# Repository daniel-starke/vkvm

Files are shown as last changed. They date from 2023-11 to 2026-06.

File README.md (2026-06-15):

vkvm
====

**V**irtual **K**eyboard **V**ideo **M**ouse equipment.  
This project consists of a software part which runs on the host (controller) computer and a hardware
unit (periphery). The periphery is connected via HDMI and USB to the USB port at the controller. The
controller uses this connection to control the connected periphery computer. Control works similar to
the control of a system running within a virtual machine.  
The vkvm ensures a non-intrusive connection to the periphery device. Therefore, no special drivers or
software is needed at the periphery. This grants maximum compatibility and high security not found in
VPN or SSH like solutions and works also before OS start-up (e.g. remote BIOS control).

```txt
+------------+       +----------------------+      +---------------+
|            |  <--- | Video Capture Device | <--- |               |
| Controller |       +----------------------+      | Remote Device |
|            |  <--> | VKVM Periphery       | <--> |               |
+------------+       +----------------------+      +---------------+
```

Features
========

- control application support for Windows and Linux
- USB UVC capture device compatible at controller
- USB HID boot keyboard/mouse compatible at periphery
- easy setup and use via plug'n'play
- cheap, small, low latency and portable design
- supports direct video output capture of periphery or web cam based operation
- multiple hardware variants are available to meet different hardware assembly skills and usage requirements
- remote device access before OS startup (e.g. enter BitLocker password or set BIOS settings)

Usage
=====

Use an available display to USB (not the other way around) converter to capture the video output
of a periphery machine at the controller. See chapter example for some possible variants. Connect
the VKVM hardware device to controller and periphery to control the keyboard and mouse of the
periphery via the controller. The vkvm control application enables you to perform the described hardware
connection on software level.  
Here you choose the connected capture source and serial interface which connects the vkvm hardware.
Click into the video frame to start controlling the remote device. Hit the right SHIFT and right CTRL key
to return control. Alternatively, press CTRL-K without a connected capture source for blind control.
This can be useful when controlling the periphery device with a connected physical monitor.  
To improve periphery operation, multiple ways of inputting data from controller (paste text) are provided.
Each type exists due to different compatibilities, either by applications or on OS level.  
Most of the user interface is made up of icons to avoid language barriers.

Status LED of the VKVM periphery:

|LED |State |Meaning
|:---:|---|---
| |always off|No remote device connected.
|LED0|blinking  |Power from remote device but not USB connection.
|LED1|always on |Fully connected to remote device.

Documentation
=============

- [Windows: VKVM Control Driver Installation](doc/win-driver.md)
- [Hardware](doc/hardware.md)
- [Software Architecture](doc/architecture.md)
- [Serial Protocol](doc/protocol.md)

Building
========


    

The following dependencies are given.  
Controller:  
- C99
- C++11
- [FLTK 1.3.4-1](https://github.com/fltk/fltk/tree/release-1.3.4-1)
- [nanosvg](https://github.com/memononen/nanosvg) (modified source included)
- OpenGL
- DirectShow (only on Windows)
- libv4l2 (only on Linux)
- lv4lconvert (only on Linux)

Periphery:  
- C18
- C++14
- [PlatformIO](https://platformio.org/)
- [STM32CubeDuino](https://github.com/daniel-starke/STM32CubeDuino)
- [HidDescCTC](https://github.com/daniel-starke/HidDescCTC)

Choose the appropriate Makefile to match your target system configuration.  
Windows with MinGW and GCC:  
```sh
make -f Makefile.mingw
```

Linux with GCC:
```sh
make -f Makefile.linux
```

This creates two applications:
- `vkvm`  
  The actual VKVM control application.
- `keyTest`  
  Development tool to create the OS key code to USB key code mapping.

To build and upload the firmware (depending on the target hardware):
```sh
pio run -e arduino -t upload
pio run -e vkm-b-controller -t upload
pio run -e vkm-b-periphery -t upload
```

Note that `VKVM_LED_PWM` for `vkm-b-periphery` can be changed in `platformio.ini` to any value
between 0 and 65535 to adjust the brightness of the status LED.

Also note that it is possible to set `upload_protocol = dfu` for `STM32CubeDuino` in `platformio.ini`
allowing first time programming via USB.

Open Points
===========

- [ ] command-line operations for instant video/serial connect and full screen switch
- [ ] automatically reconnect last serial/video device if it re-appears and was not disconnected by user
- [ ] alternative serial/video implementation using libusb/libuvc
- [ ] force aspect ratio option in aspect ratio button
- [ ] audio support
- [ ] configurable hot keys
- [ ] media key support (needs changes in the periphery firmware)
- [ ] fast store and load option for capture source settings
- [ ] option for file exchange via USB MTP (media transfer protocol)
- [ ] option for shared network access via USB ECM (Ethernet control model)

Limitation
==========

- keyboard and mouse input may not work with the Arduino firmware variant due to legacy BIOS
  incompatibilities with the CDC interface included by Arduino
- no OCR support (out of scope and can be done with existing screen reader applications)
- root permissions are required for the vkvm application on Linux

Debugging
=========

Choose the appropriate Makefile to match your target system configuration.  
Windows with MinGW and GCC:  
```sh
make -f Makefile.mingw DEBUG=1
```

Linux with GCC:
```sh
make -f Makefile.linux DEBUG=1
```

The macro `VKVM_TRACE` can be defined to create the serial trace file `vkvm.log`
during runtime. The GAWK script `script/prot-dec.awk` is able to decode this file into
a human readable format. The macro can be enabled by passing `TRACE=1` to Gnumake.

To debug the periphery firmware run:
```sh
pio debug -e vkm-b-periphery
pio run -e vkm-b-periphery -t upload -t nobuild
pio debug  -e vkm-b-periphery --interface=gdb -- -x .pioinit
```

The HID reports on the periphery device can be traced using
Wireshark (see [description](https://wiki.wireshark.org/CaptureSetup/USB)).

In Linux it is also possible to read and analyze the HID reports
with the following command:
```sh
cat /sys/kernel/debug/<dev>/events
```

This shows how the Linux HID driver interprets the HID reports.

License
=======

See [LICENSE](LICENSE).  

Contributions
=============

No content contributions are accepted. Please file a bug report or feature request instead.  
This decision was made in consideration of the used license.

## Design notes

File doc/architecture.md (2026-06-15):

Software Architecture
=====================

Controller
----------

### Basic Data Flow

```txt
+-------------+         +------+ 
|             | <-----> | User | ----.
|             |         +------+     |
|             |           A          V 
|             |           |    +-----------+      +--------------+      +---------+
|             | <---------+--> |VkvmDevice | <--> | SerialCommon | <--> | tSerial |
|             |           |    +-----------+      +--------------+      +---------+
| VkvmControl |           |
|             |      +----------+      +---------------+      +-----------------+
|             | <--> | VkvmView | <--- | CaptureDevice | <--- | DirectShow/V4L2 |
|             |      +----------+      +---------------+      +-----------------+
|             |
|             |      +--------------------------+
|             | <--- | NativeSerialPortProvider |
|             |      +--------------------------+
|             |      +----------------------------+
|             | <--- | NativeVideoCaptureProvider |
+-------------+      +----------------------------+
```

### GUI

The `VkvmControl` provides the main application window.

- `pcf::gui::VkvmControl` main control GUI
  - `pcf::video::NativeVideoCaptureProvider videoSource`  
    instance which provides capture devices
  - `pcf::serial::NativeSerialPortProvider serialPortSource`  
    instance which provides serial devices
  - `pcf::serial::VkvmDevice videoDevices`  
    actual video capture handle
  - `pcf::serial::SerialPort serialPorts`  
    actual serial handle

It receives device change notifications for serial and capture devices to
update the source lists and handle source device disconnections.  
The `VkvmControl` also owns sub classes for GUI control.

- `pcf::gui::<anonymous>::LicenseInfoWindow`  
  shows the license in a new window
- `pcf::gui::<anonymous>::OnClickBox`  
  helper class to add a mouse push callback to the status bar
- `pcf::gui::VkvmControlRotationPopup`  
  pop-up window for the possible capture rotation settings
- `pcf::gui::VkvmControlStatusPopup`  
  pop-up window for the status bar event history

And a control background thread to forward longer inputs (paste text) to the periphery.

- `pcf::gui::VkvmControlSerialSend`  
  forwards text in the given encoding to the periphery

The following classes implement further GUI functions used by `VkvmControl`.

- `pcf::gui::DynWidthButton`  
  add automatic width from label text function to `HoverButton`
- `pcf::gui::HoverButton`  
  flat `Fl_Button` with hover style used for toolbar icons
- `pcf::gui::HoverChoice`  
  flat `Fl_Menu_` with hover style used for toolbar menu entries
- `pcf::gui::HoverDropDown`  
  flat `Fl_Menu_` with hover style used for toolbar drop-down lists
- `pcf::gui::SvgButton`  
  button with optional hover style which shows an SVG image instead of text used for toolbar icons
- `pcf::gui::ScrollableValueInput`  
  adds value manipulation via mouse wheel to Fl_Value_Input (used in `src/pcf/video/CaptureVideo4Linux2.ipp`)
- `pcf::gui::SvgView`  
  SVG image viewer widget used for status bar icons
- `pcf::gui::VkvmView`  
  video capture device viewer

The SVG images used in this application can be found in `src/pcf/gui/SvgData.hpp`
and as original file in `src/*.svg`.

### Serial Device

These classes provide functions to list and handle serial devices for VKVM.

- `pcf::serial::SerialPort`  
  single serial port description
- `pcf::serial::SerialPortList`  
  list of serial port descriptions
- `pcf::serial::SerialPortListChangeCallback`  
  interface to receive serial port change notifications (plug/unplug)
- `pcf::serial::NativeSerialPortProvider`  
  platform specific serial port description provider (e.g. list available ports)
- `pcf::serial::VkvmCallback`  
  interface to receive VKVM command responses
- `pcf::serial::VkvmDevice`  
  handles a VKVM periphery device which all available commands; also allows to grab and forward the keyboard

The actual implementation of `VkvmDevice` and `NativeSerialPortProvider` is hidden
via PIMPLE pattern to allow easy replacement when linked dynamically.  
`VkvmDevice` and `VkvmCallback` can be used to implement a custom interface
(e.g. for scripting) to the VKVM device. `NativeSerialPortProvider` acts as helper
for this task.  
The actual OS portable serial device implementation is done in `src/libpcf/serial.h`
and `src/libpcf/serial.c`.  

### Video Device

These classes provide functions to list and handle video capture devices for VKVM.

- `pcf::serial::CaptureOrientation`  
  enumeration of possible vertical row orders
- `pcf::serial::CaptureCallback`  
  interface to receive VKVM capture frames
- `pcf::serial::CaptureDeviceChangeCallback`  
  interface to receive video capture device change notifications (plug/unplug)
- `pcf::serial::CaptureDevice`  
  handles a VKVM video capture device
- `pcf::serial::CaptureDeviceList`  
  list of multiple capture device instances
- `pcf::serial::CaptureDeviceProvider`  
  interface to handle video capture device lists
- `pcf::serial::NativeVideoCaptureProvider`  
  platform specific implementation of `CaptureDeviceProvider`

`NativeVideoCaptureProvider` uses DirectShow on Windows and Video4Linux2 on Linux.  
The DirectShow implementations uses the native configuration dialog for the capture device.  
The Video4Linux2 implementation uses a custom FLTK dialog to configure the capture device.

### Utility

#### Color utility classes

- `pcf::color::Rgb555`  
  helper for RBG555 color format
- `pcf::color::Rgb565`  
  helper for RBG565 color format
- `pcf::color::Rgb24`  
  helper for RGB24 color format
- `pcf::color::Bgr24`  
  helper for BGR24 color format
- `pcf::color::Rgb32`  
  helper for RGB32 color format
- `pcf::color::Bgr32`  
  helper for BGR32 color format
- `pcf::color::SplitColor`  
  helper to hold and convert between RGB and HSV color values

#### Image manipulation classes/functions

- `pcf::image::blendOver()`  
  blend foreground color over the opaque background color
- `pcf::image::drawCircleAA()`  
  draw anti-aliased circle
- `pcf::image::drawEllipseAA()`  
  draw anti-aliased ellipse
- `pcf::image::Filter`
  helper class to render an RGBA32 image with different visual filters
- `pcf::image::SvgRenderer`  
  SVG renderer based on [nanosvg](https://github.com/memononen/nanosvg)

#### GUI classes/functions/macros

- `pcf::gui::noSymLabelDraw()`  
  FLTK drawing function to draw text without symbol interpretion
- `pcf::gui::noSymLabelMeasure()`  
  FLTK measurement function to draw text without symbol interpretion
- `pcf::gui::adjDpiH()`  
  returns pixel width equivalent for 96 DPI
- `pcf::gui::adjDpiV()`  
  returns pixel height equivalent for 96 DPI
- `pcf::gui::LinkedHoverState`  
  interface used to link the hover state of multiple widgets (implemented in `SvgButton`)
- `PCF_GUI_BIND()`
  creates a static member function which maps the FLTK callback to a class method
- `PCF_GUI_CALLBACK()`
  derives the static member function name created via `PCF_GUI_BIND()`

#### String functions

- `cvutf8_toUtf16()`  
  converts a null-terminated UTF-8 string to UTF-16
- `cvutf8_toUtf16N()`  
  converts a fixed length UTF-8 string to UTF-16
- `cvutf8_fromUtf16()`  
  converts a null-terminated UTF-16 string to UTF-8
- `cvutf8_fromUtf16N()`  
  converts a fixed length UTF-16 string to UTF-8
- `ncs_cmp()`  
  compares two null-terminated string with natural order
- `ncs_icmp()`  
  compares two null-terminated string with natural order case-insensitive

#### Miscellaneous classes/functions/macros

- `pcf::CloneableInterface<Base>`  
  interface for classes that implement the cloneable API
- `pcf::Cloneable`  
  implements the `CloneableInterface<Derived, Base>`
- `pcf::ScopeExit`  
  helper class to implement `makeScopeExit()`
- `pcf::makeScopeExit()`  
  executes the given function at end of scope
- `pcf::xEINTR()`  
  Linux specific helper to redo an ioctl on `EINTR` error
- `PCF_IS_WIN`  
  macro which is `1` for Windows platforms and not defined otherwise
- `PCF_IS_NO_WIN`  
  macro which is `1` for non-Windows platforms and not defined otherwise
- `PCF_IS_LINUX`  
  macro which is `1` for Linux platforms and not defined otherwise
- `PCF_IS_NO_LINUX`  
  macro which is `1` for non-Linux platforms and not defined otherwise
- `PCF_PATH_SEP`  
  macro which evaluates to the platform typical path separator
- `PCF_UNUSED()`  
  macro to suppress variable not used warnings
- `PCF_PRINTF()`  
  macro to tell the compiler to warn if incorrect arguments have been passed
  to a `printf()`-like function

Firmware
--------

@todo

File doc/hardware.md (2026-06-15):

Hardware
========

VKM
----

### PCB

The VKVM periphery to control keyboard and mouse of the periphery can be ordered using the provided
Gerber and placement or KiCAD files. It is recommended to use the latest hardware version for full
function support.

- [KiCAD](../hw/vkm-c)
- [Gerber, BOM and placement](../hw/vkm-c/jlcpcb) for orders at [JLCPCB](https://jlcpcb.com/)
  - USB-A (J4) needs to be soldered by hand (may be required to sand a bit off from the PCB side)
  - The pin headers J2 (ST-Link) and J3 (UART) are optional.

**Important:** Be sure that the USB connectors are fully inserted and aligned when soldering.
Especially when handling the USB-A plug (J4). The plastic pins of the USB-A plug may need to be
removed to accomplish this depending on the actual component type.

Use the following parameters when ordering the PCB. Note that the values have only been tested with JLCPCB.
- layers: 2
- base material: FR4
- dimensions: 35.8x18.5mm
- thickness: 1mm
- surface finish: lead free HASL
- impedance control: no
- outer copper weight: 1oz

With no special extras.

### Connectors

- J1 shall be connected to the remote periphery.
- J2 is used for debugging and firmware upload.
- J3 is used for tracing.
- J4 shall be connected to the controller.
- The 3D printed connector housings [stlink-conn-A.stl](../hw/vkm-c/stlink-conn-A.stl) and [stlink-conn-B.stl](../hw/vkm-c/stlink-conn-B.stl)
  can be used to connect J2 to a Chinese [ST-Link/V2 clone](https://stm32world.com/wiki/DIY_STM32_Programmer_(ST-Link/V2-1)).
  Just glue them to jumper cables with the correct pin out.

### Wiring

Wiring for debugging/tracing via ST-Link/V2.

|VKVM  |ST-Link/V2 |Target |
|---|---|---|
|RESET |RST |Controller |
|BOOT  |- |Controller |
|SWDIO |SWDIO |Controller |
|SWCLK |SWCLK |Controller |
|GND |GND |Controller/Periphery |
|SWCLK |SWCLK |Periphery |
|SWDIO |SWDIO |Periphery |
|BOOT  |- |Periphery |
|RESET |RST |Periphery |

### Case

The case can be 3D printed in for example in PLA.  
Pre-created STL files for the variant without any pin header are included.
- [case-bottom.stl](../hw/vkm-c/case-bottom.stl)
- [case-top.stl](../hw/vkm-c/case-top.stl)

Tolerance can be adjusted to match the one of the printer using the spreadsheet within the included FreeCAD file.
This also includes cases for board variants with pin header.
- [case.FCStd](../hw/vkm-c/case.FCStd)

Use the given orientation for printing and the following parameters:
- layer height: 0.2mm
- infill: ≥15%
- solid layers: ≥5 top, ≥4 bottom
- perimeters: ≥3
- supports: none

Insert a transparent 1.75mm filament into the LED hole and cut it off at the case top edge. This acts as light guide.
Note that both sides of the case should just snap together. No glue is required.

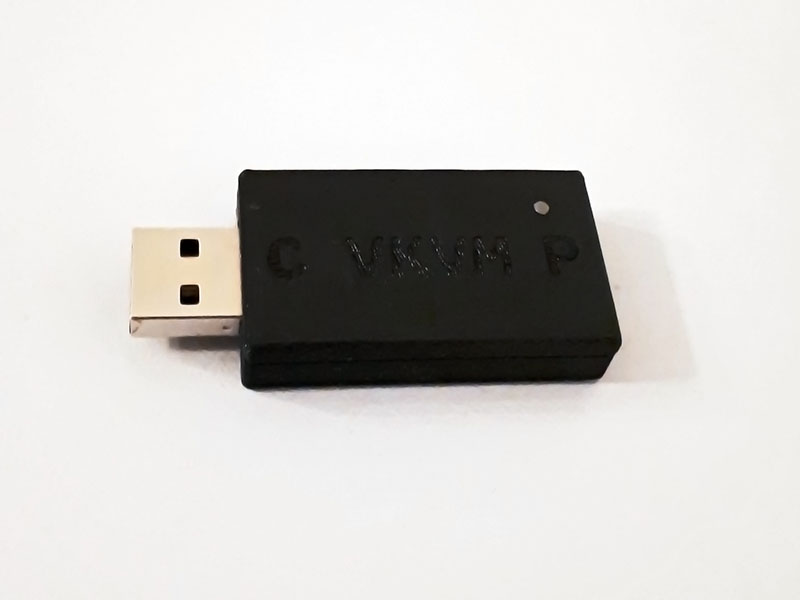
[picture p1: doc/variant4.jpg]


### Firmware Upload

The firmware can be uploaded via J2 using an ST-Link/V2 programmer or
by DFU upload at the first time with no firmware uploaded yet. Later
can be done by connecting each of the VKM USB connects once to the PC
and choosing DFU as upload method. Later uploads require an ST-Link/V2
programmer or similar device.

### Older Variants

Previous attempts to design a VKM device have been made and are listed here for reference.

#### Variant 1

Parts used:
- [HDMI Capture Variant 1](hdmi-cap1.md)
  - The board inside was reused without the housing.
- 4-Port USB2.0 Extension Board Module
  - https://www.aliexpress.com/item/4001031421760.html
  - https://www.aliexpress.com/item/4000355651437.html
  - https://www.aliexpress.com/item/1005003614172238.html
  - https://www.amazon.com/dp/B09P4899CF
- USB-A to TLL CH340G Module with modified pin header
  - https://www.aliexpress.com/item/4000120687489.html
  - https://www.aliexpress.com/item/4000120687489.html
  - https://www.amazon.com/dp/B09MKW6ZQ8
- TTL to Arduino ProMicro Board with Isolation
  - [PCB](../hw/ser)
- Short Arduino ProMicro
  - https://www.aliexpress.com/item/1005003717649243.html
  - https://eu.robotshop.com/products/cytron-arduino-pro-micro-compatible-w-pre-soldered-headers
  - https://www.amazon.com/dp/B09C5H78BP
- 3D printed case
  - [FreeCAD](../res/Case.FCStd)
  - [STL part A](../res/CaseA.stl)
  - [STL part B](../res/CaseB.stl)
- 1x 24..25mm M3 screw with nut

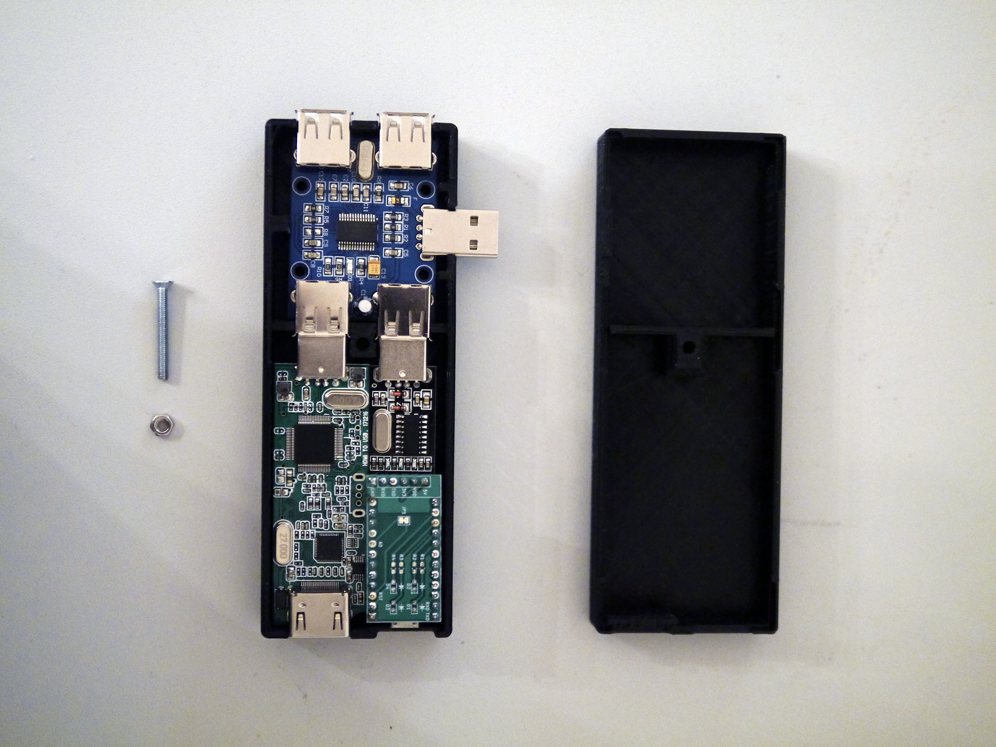
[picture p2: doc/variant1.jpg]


#### Variant 2

This is basically variant 1 without the HDMI capture device included.  
Parts used:
- 4-Port USB2.0 Extension Board Module
  - see variant 1
- USB-A to TLL CH340G Module with modified pin header
  - see variant 1
- TTL to Arduino ProMicro Board with Isolation
  - [PCB](../hw/ser)
- Short Arduino ProMicro
  - see variant 1
- 3D printed case
  - [FreeCAD](../res/Case.FCStd)
  - [STL part A](../res/SmallCaseA.stl)
  - [STL part B](../res/SmallCaseB.stl)
- 2x 22mm M3 screw with nuts

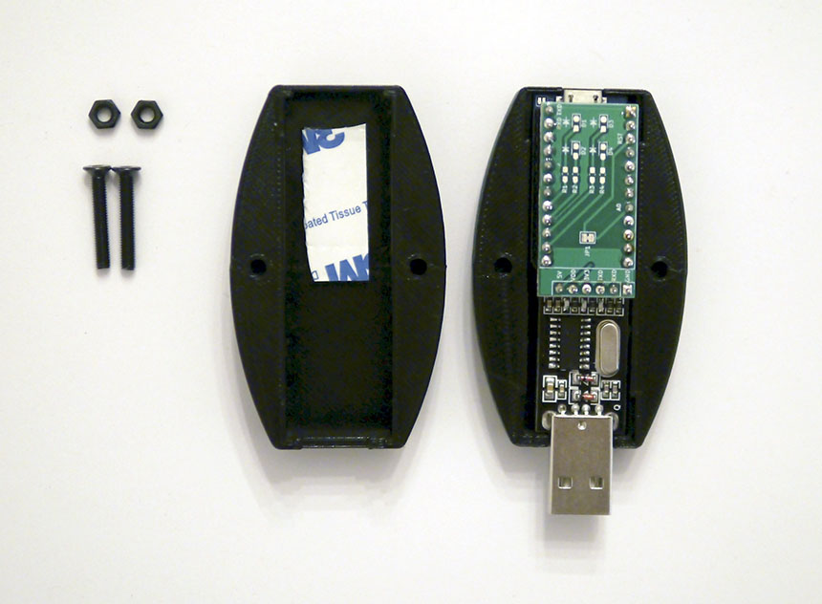
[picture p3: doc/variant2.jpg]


Video Capture Devices
---------------------

The following variants have been tested.

- [HDMI Capture Variant 1](hdmi-cap1.md)  
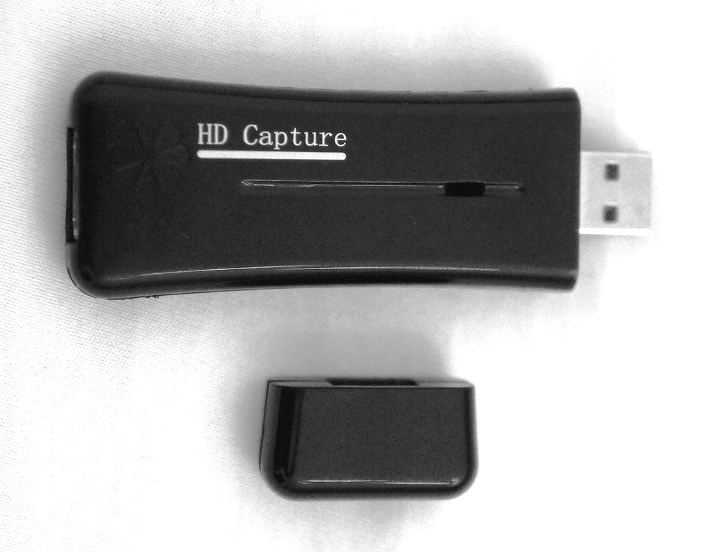
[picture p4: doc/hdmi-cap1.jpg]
  
- [HDMI Capture Variant 2](hdmi-cap2.md)  
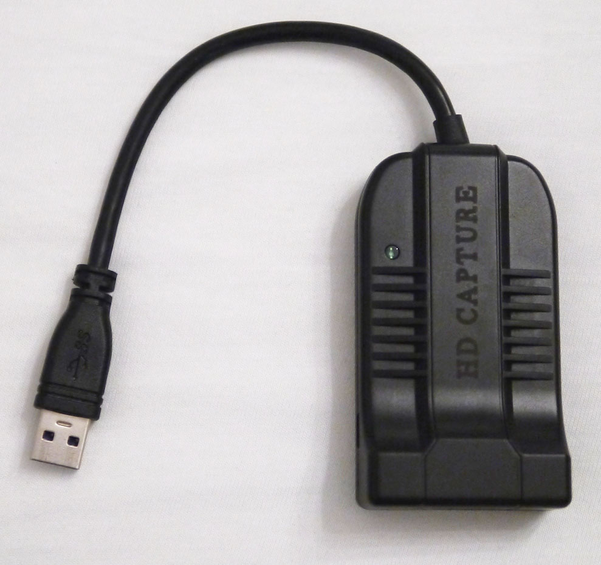
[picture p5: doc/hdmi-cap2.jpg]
  
- [HDMI Capture Variant 3](hdmi-cap3.md)  
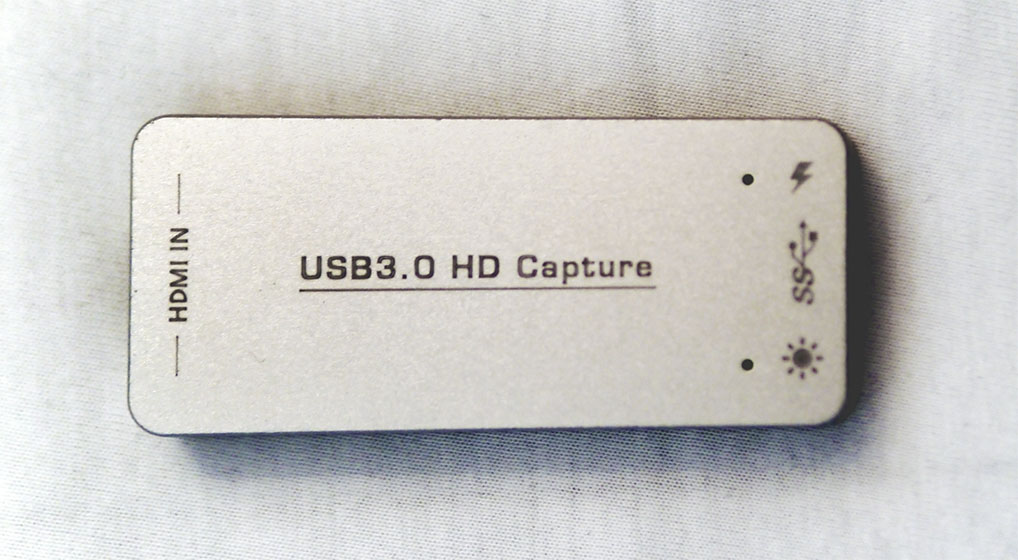
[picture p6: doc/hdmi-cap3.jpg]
  
- [HDMI Capture Variant 4](hdmi-cap4.md)  
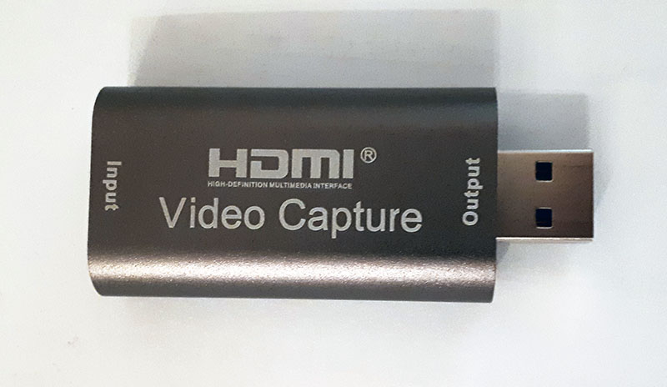
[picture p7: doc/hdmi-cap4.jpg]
  
- [HDMI Capture Variant 5](hdmi-cap5.md)  
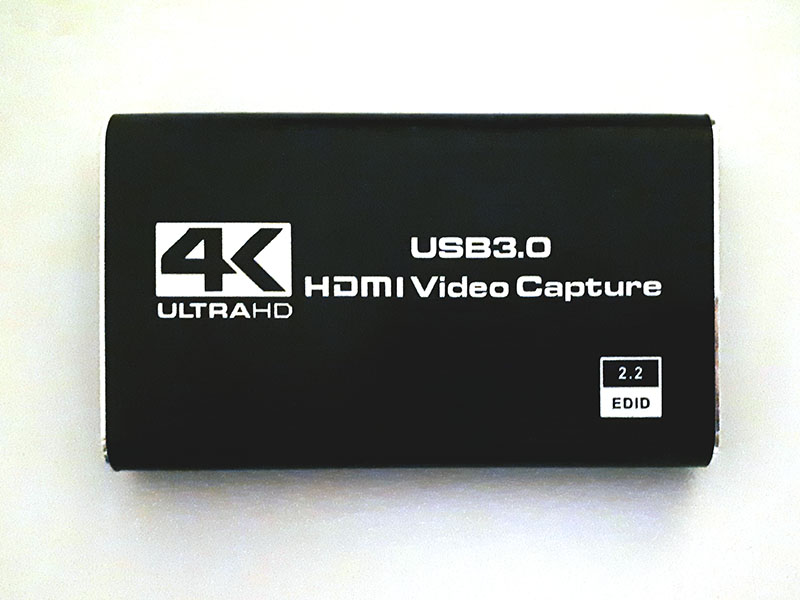
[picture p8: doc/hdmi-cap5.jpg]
  
- [HDMI Capture Variant 6](hdmi-cap6.md)  
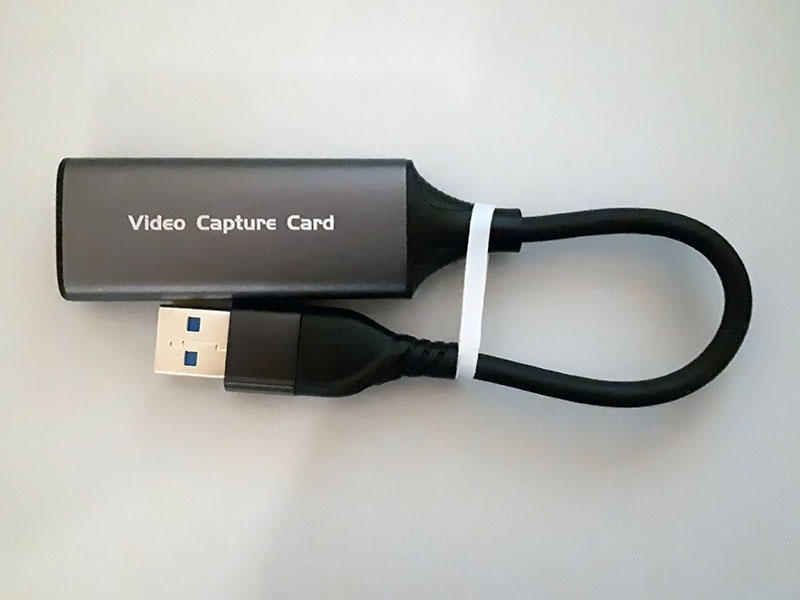
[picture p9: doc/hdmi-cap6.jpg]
  
- [HDMI Capture Variant 7](hdmi-cap7.md)  
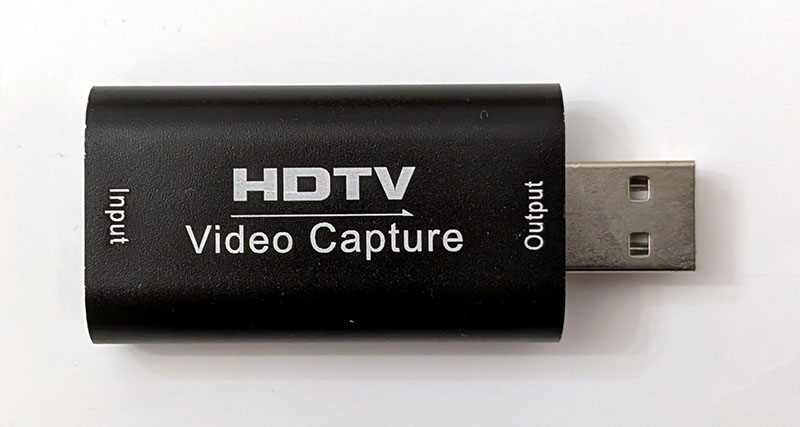
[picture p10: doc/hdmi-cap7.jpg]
  
- [HDMI Capture Variant 8](hdmi-cap8.md)  
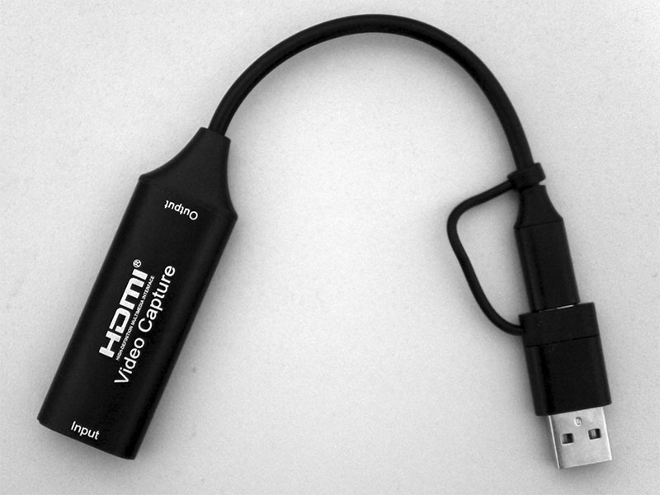
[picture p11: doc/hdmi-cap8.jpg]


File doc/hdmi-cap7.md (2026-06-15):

HDMI Capture Variant 7
======================



Available at AliExpress.com:
* https://www.aliexpress.com/item/1005006599533634.html
* https://www.aliexpress.com/item/1005006890646282.html
* https://www.aliexpress.com/item/1005006825608006.html

Supports plug and play with a UVC and UVA compatible USB capture interface.

**On Windows 7:**  
Monitor (HDMI connection) is detected as `1. MACROSILICON` with `HJW1836` (4096x2160, 1280x720 recommended).  
Capture device (USB connection) is detected as `USB Video` with `USB\VID_534D&PID_2109&REV_2100&MI_00` for video and `USB Digital Audio` with `USB\VID_534D&PID_2109&REV_2100&MI_02` for audio.

Description
===========

4K USB3.0 USB2.0 Audio Video Capture Card HDMI To USB 3.0 2.0 Acquisition
Card Live Streaming Plate Camera Switch Game Recording video capture can
capture both HDMI video and HDMI audio, sending audio and video signals to
computers and smart phones for preview and storage. Suitable for high
definition acquisition, teaching recording, medical imaging, etc.

Feature
-------

* Support input max resolution 3840×2160@30Hz;
* Support output max resolution 1920×1080@30Hz/60Hz;
* Support 8/10/12bit deep color;
* Support AWG26 HDMI standard cable: input up to 15 meters, (1080P and below resolution);
* Support most acquisition software, such as VLC, OBS, Amcap, etc;
* Support for Windows、Android and MacOS;
* Conform to USB Video and for UVC standard;
* Conform to USB Audio for UAC standard;
* Without external power supply, compact and portable.

Specifications
--------------

|Parameter | Value
|---|---
|HDMI resolution |Max input can be 3840×2160@30Hz
|Support video format |8/10/12bit Deep color
|Video output format |YUV, JPEG
|Video output resolution |Max output can be 1920×1080@30Hz/60Hz
|Support audio format |L-PCM
|Input cable distance |≤15m, AWG26 HDMI standard cable
|Max working current |0.4A/5VDC

Connection and Operation
------------------------

1. Connect the UHD signal source to the HDMI input of the video capture with one HDMI cable.
2. Connect the computer to the usb port of the video capture with usb cable.
3. Operation steps for USB video capture(OBS): Open the software→Choose sources of
   "Video capture Device" → Set the size of image → Choose "Studio Mode" (double window) → Choose "Start Recording".

Operation Example as below
1. Add new sources, choose "Nsendato Video Capture Device"

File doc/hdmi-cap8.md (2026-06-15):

HDMI Capture Variant 8
======================



Available at AliExpress.com:
* https://www.aliexpress.com/item/1005009379106163.html
* https://www.aliexpress.com/item/1005010107915473.html

Supports plug and play with a UVC and UVA compatible USB capture interface.

**On Windows 7:**  
Monitor (HDMI connection) is detected as `HD TO USB` with `HJW2109` (4096x2160, 1280x720 recommended).  
Capture device (USB connection) is detected as `USB Video` with `USB\VID_345F&PID_2109&REV_2100&MI_00` for video and `USB Digital Audio` with `USB\VID_345F&PID_2109&REV_2100&MI_02` for audio.

Description
===========

The video capture can capture both HDMI-compatible video and HDMI-compatible audio,
sending audio and video signals to computers and smart phones for previews and storage.
Suitable for high definition acquisition, teaching recording, medical imaging, etc.

Feature
-------

* Support input max resolution 4K@30Hz;
* Support output max resolution 1080P@60Hz;
* Support 24/30/36bit deep color;
* Support AWG26 HDMI-compatible standard cable: input up to 15 meters, (1080P and below resolution);
* Support most acquisition software, such as VLC, OBS, Amcap, etc;
* Support Windows, Android and MacOS;
* Conform to USB Video and UVC standard;
* Conform to USB Audio UAC standard;
* Support uncompressed(YUY2 1080P@60Hz) acquisition (USB3.0);
* No need external power supply, compact and portable.

Specifications
--------------

|Parameter | Value
|---|---
|HDMI resolution |Max input can be 3840x2160@30Hz
|Support video format |8/10/12bit Deep color
|Video output format |YUV, JPEG
|Video output resolution |Max output can be 1920x1080@60Hz
|Support audio format |L-PCM
|Input cable distance |≤15m, AWG26 HDMI standard cable
|Max working current |0.4A/5VDC
|Operating Temperature range |(-10 to +55°C)
|Dimension (L x W x H) |64x28x13 (mm)
|Weight |21.4g

Connection and Operation
------------------------

1. Connect the UHD signal source to the HDMI input of the video capture with
   one HDMI cable.
2. Connect the computer to the usb port of the video capture with usb cable.
3. Operation steps for USB video capture (OBS): Open the software→Choose
   source of "Video capture Device"→Set the size of image→Choose "Studio
   Mode"(double window)  Choose "Start Recording".
   Operation Example as below

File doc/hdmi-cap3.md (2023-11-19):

HDMI Capture Variant 3
======================



Available at AliExpress.com:
* https://www.aliexpress.com/item/4000417318610.html
* https://www.aliexpress.com/item/4000263805121.html
* https://www.aliexpress.com/item/4000315707681.html
* https://www.aliexpress.com/item/4000268193173.html

High heat buildup at full resolution and frame rate. Internal chips have thermal pads glued to the external aluminum case.  
Capture rate (not monitor rate) can only be 30 or 60 FPS.  
Supports plug and play with a UVC and UVA compatible USB capture interface.

**On Windows 7:**  
Monitor (HDMI connection) is detected as `SUNTECH PVR` with `SUM0000` (1920x1080).  
Capture device (USB connection) is detected as `UHD Capture` (or `FHD Capture` on USB2.0 port) with `USB\VID_1BCF&PID_2C99&REV_0200&MI_00` for video and `USB\VID_1BCF&PID_2C99&REV_0200&MI_02` for audio.

Product Description
===================

HDMI USB 3.0 Video Capture Card Adapter 1080HD Recorder Box for Windows HD Video Capture Card Adapter

Features: This is a HD to USB 3.0 video capture card adapter, which offers acquisition of single channel
HDMI HD audio and video signals, no drive needed, plug and play.
The input and output video signal is up to 1080P/60Hz.
Meets UVC standard, compatible with video capture and YUV422 video output.
Meets UAC standard, compatible with HDMI audio capture and 48KHz PCM audio output.
Suitable for Windows, for Linux, for OS X operation systems.

|Parameter | Value
|---|---
|Model Number |HD Video Capture Card
|Interface Type |USB
|Package |No
|Type |Video & TV Tuner Cards
|HDMI Capture |placa de captura HDMI
|HDMI Recorder |HDMI to USB 3.0 Video Capture
|HDMI Capture Card |Card Video Capture

Specification:

|Parameter | Value
|---|---
|HDMI |HDMI 1.4/HDCP 1.4, compatible with DVI 1.0
|USB |USB 3.0 * 300-350Mbps, USB 2.0 * 40Mbps
|HDMI Input Resolution |480i, 480p, 576i, 576p, 720p50, 720p60, 1080i50, 1080i60, 1080p24/25/30/50/60
|HDMI Output Resolution|640x480 / 720x480 / 720x576 / 768x576 / 800x600 / 1024x768 / 1280x720 / 1280x800 / 1280x960 / 1280x1024 / 1368x768 / 1440x900 / 1600x1200 / 1680x1050 / 1920x1080 / 1920x1200 / 640x360 / 856x480 / 960x540 / 1024x576
|Chromaticity Space |RGB/YCBCR 4:2:2 / YCBCR 4:4:4
|Audio Input |LPCM 32-192KHz
|Audio Output |LPCM 48KHz
|Bandwidth |165MHz (4.95Gbps)
|ESD Protection |Human-body Model ±8kV (air-gap discharge), ±4kV (contact discharge)
|Material |metal
|Color |silver
|Working Temperature |0°C to 40°C
|Storage Temperature |-20°C to 60°C
|Relative Humidity |20% to 90% RH (non-condensing)
|Size |approx. 9.9x5.5x1.5cm / 3.9x2.2x0.6in
|Weight |approx. 227g

Package Contents:
* 1x HD Video Capture Card Adapter
* 1x UBS Cable
* 1x HD line

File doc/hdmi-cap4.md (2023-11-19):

HDMI Capture Variant 4
======================



Available at AliExpress.com:
* https://www.aliexpress.com/item/1005001382235274.html
* https://www.aliexpress.com/item/1005005709766777.html
* https://www.aliexpress.com/item/1005005709924119.html
* https://www.aliexpress.com/item/1005005709924119.html

Supports plug and play with a UVC and UVA compatible USB capture interface.

**On Windows 7:**  
Monitor (HDMI connection) is detected as `HJW1836` with `MACROSILICON` (4096x2160, 1280x720 recommended).  
Capture device (USB connection) is detected as `USB Video` with `USB\VID_534D&PID_2109&REV_2100&MI_00` for video and `USB\VID_534D&PID_2109&REV_2100&MI_02` for audio.

Description
===========

The HD vedio capture card can capture HD vedio and audio at the same time.
USB 3.0 video converter transmit vedio and audio to the computer and smart phone to store it.
The HD 1080P audio recorder device supports 60fps and USB3.0, VLC, OBS,,Amcap.
The 60fps audio recorder can used to capture hd collection, teaching recording and medical image.
HD video converter surpports, replacement for Windows/replacement for Android/replacement for MacOS, so that it can be used widely.

Specification:

|Parameter | Value
|---|---
|HD resolution |3840x2160@60Hz
|Video input format |8/10/12 bit color depth
|Video output mode |YUV, JPEG
|Video output resolution |1920x1080@60Hz
|Support audio format |L-PCM
|Input cable length |≤15m, AWG26 HD cable
|Maximum working current |0.4A/5VDC
|Operating temperature range|-10 to +55°C
|Size |64x28x13mm
|Weight |21.4g

Package included:
* 1x capture card

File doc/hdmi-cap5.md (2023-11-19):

HDMI Capture Variant 5
======================



Available at AliExpress.com:
* https://www.aliexpress.com/item/1005006068616088.html
* https://www.aliexpress.com/item/1005002628899307.html
* https://www.aliexpress.com/item/1005004183322712.html
* https://www.aliexpress.com/item/1005006172319734.html

Supports plug and play with a UVC and UVA compatible USB capture interface.

**On Windows 7:**  
Monitor (HDMI connection) is detected as `1. Capture` with `CAP0100` (4096x2160, 3840x2160 recommended).  
Capture device (USB connection) is detected as `USB3.0 HD Video Capture` with `USB\VID_EBA4&PID_7588&REV_0328&MI_02` for video and `USB3.0 HD Audio Capture` with `USB\VID_EBA4&PID_7588&REV_0328&MI_00` for audio.

Description
===========

This USB capture card can collect HDMI-Compatible audio and video. HDMI-Compatible audio and video signals can be
transmitted to the computer and smartphone for preview and storage. Suitable for high-definition acquisition, teaching recording, medical imaging, etc.

Features
--------

* Support input resolution up to 4K
* Support output resolution up to 1080P
* One HDMI-Compatible input, One HDMI-Compatible loop out, Watching and Recording
* One Microphone input
* One 3.5mm stereo output
* Support 8/10/12 bit color depth
* Support AWG26 HDMI-Compatible standard cable, the maximum input transmission distance is 15 meters (1080P and below resolution)
* Support most acquisition software, such as for VLC, OBS, Amcap, etc.
* Support for Windows, for Android and for Mac OS
* Complies with USB video UVC specifications
* Complies with USB audio UAC specifications
* No external power supply, compact size, easy to Carry

Specification
-------------

|Parameter | Value
|---|---
|HDMI-Compatible resolution  |Maximum input support 4K
|Video input format |8/10/12-bit color depth
|Video output mode |MJPEG
|Video output resolution |Maximum output resolution 1080P @ 30Hz
|Support audio format |LPCM
|Input cable length |≤15m, AWG26 HDMI-Compatible-Compatible standard cable
|Maximum working current |0.4A / 5V DC
|Operating temperature range |(-10 to + 55°C)
|Product size(LxWxH) |68x27x9(mm)
|Product weight |50g

Connection Operation
--------------------

1. Connect the USB port of the video capture card to the USB port of the computer.
2. Use the HDMI-Compatible cable to connect the “HDMI-Compatible IN”interface of the capture card to the HDMI-Compatible output port of the video source device to be captured, and use another HDMI-Compatible cable to connect the “HDMI-Compatible OUT” interface of the video capture card to the display device,
3. Insert the microphone into the MIC interface of the capture card
4. Connect the headset or sound system to the R/L interface of the capture card, and the preliminary installation and connection work is completed.

Note
----

Computer hardware configuration requirements  
CPU: PC i5-3400 or above; NB i7-3537U 2.0GHZ or above  
Graphics card: PC NVIDIA GT630 or above; NC NVIDIA GT35M or above  
Storage: 4G RAM

Package included
----------------

* 1x HDMI-Compatible to USB Video Capture Card
* 1x User Manual

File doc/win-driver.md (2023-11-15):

Windows: VKVM Control Driver Installation
=========================================

The controller side of the VKVM periphery may require the user to install a driver.
The default USB VID/PID is treated as Arduino Leonardo and is automatically available
if the [Arduino IDE](https://www.arduino.cc/en/software) has been installed.

At its base it used a standard USB CDC/ACM interface for which Windows already offers the
right device driver. Follow the following steps to assign it manually to the VKVM periphery
controller side without any additional software being required.

1. Open the device manager. E.g. press WIN+R and run `devmgmt.msc`.
   Right click on the new device and select "Update driver".  
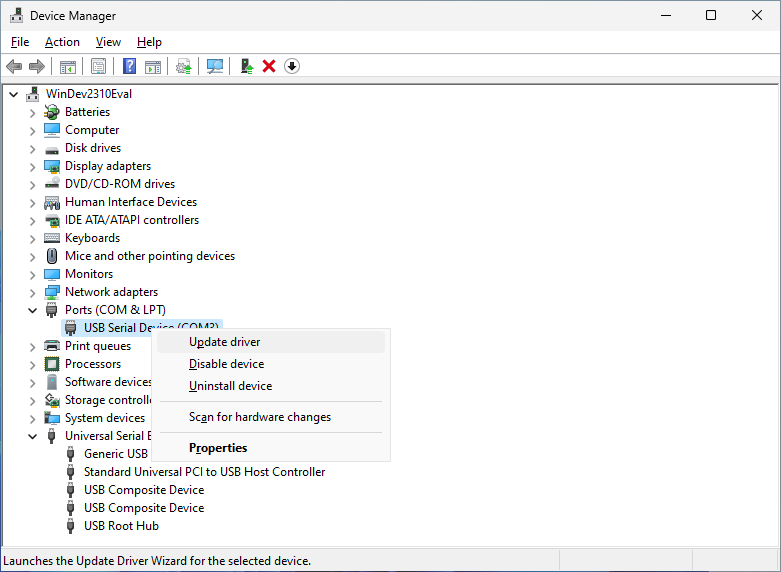
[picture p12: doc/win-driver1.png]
Device Manager
   
2. Choose "Browse my computer for drivers".  
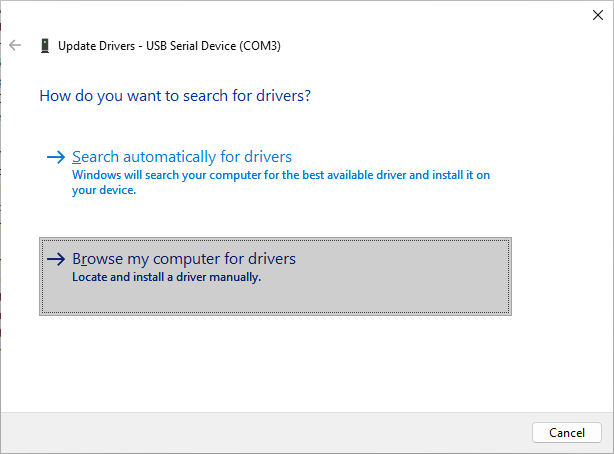
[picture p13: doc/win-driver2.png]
Source Selection
   
3. Choose "Let me pick from a list of available drivers on my computer".  
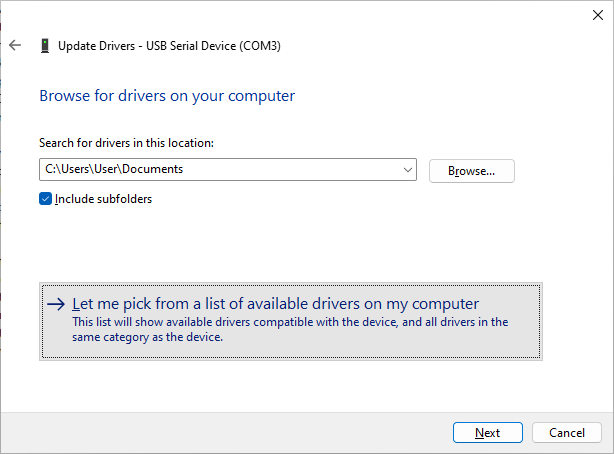
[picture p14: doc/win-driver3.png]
Path Selection
   
4. Clear "Show compatible hardware" and select "USB Serial Device" or a similar entry
   from "Microsoft". Other serial device drivers like from Prolific may also work.  
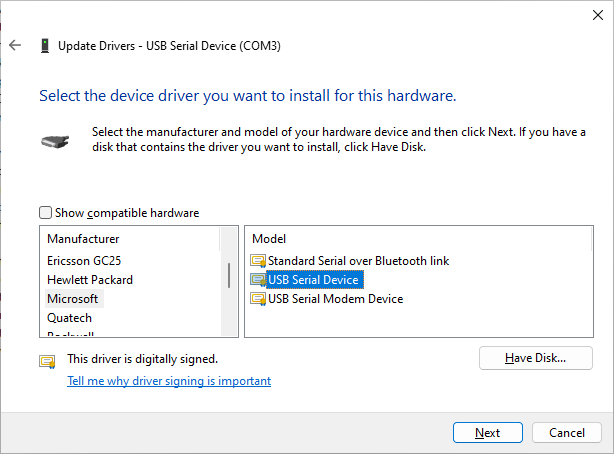
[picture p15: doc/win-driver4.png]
Driver Selection 1
   
5. For example "Serial" from "(Standard port types)".  
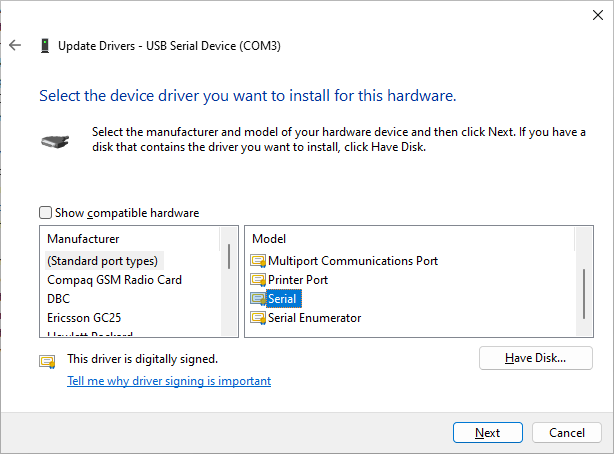
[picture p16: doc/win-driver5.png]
Driver Selection 2
   
6. Press "Next" to finish the driver installation.

This example applies to Windows 11 and is similar with other Windows versions.

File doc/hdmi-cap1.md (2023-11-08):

HDMI Capture Variant 1
======================



Available at AliExpress.com:
* https://www.aliexpress.com/item/4000007234729.html
* https://www.aliexpress.com/item/33054049749.html
* https://www.aliexpress.com/item/32996784167.html
* https://www.aliexpress.com/item/33007122036.html

Little heat buildup at full resolution and frame rate. No HD output (only input).  
Seems to use an HDMI to S-Video to USB converter internally.  
Contrast, brightness and other values are not optimal set by default and need to be adjusted for an optimal image.  
Chip: HD DVR1997 1824N 7AJP47457.000 BPM583.8  
**Caution: This device has no UVC/UVA support and needs special capture drivers usually found on the included CD.**  

**On Windows 7:**  
Monitor (HDMI connection) is detected as `HDMI` with `AGO0001` (1920x1080, 1024x768 recommended).  
Capture device (USB connection) is detected as `usbtv007` with `USB\VID_1B71&PID_3002&REV_0100` for video and audio.

Product Description
===================

HD Video Capture Card, USB 2.0 HDMI Video Capture Cards Accessories For Computer

Features:
* HDMI input resolution: 720x480 (30p), 720x576 (30p), 1280x720p (30P), 1280x720p (30p) 1920x1080 pixels at 30x, 1920x1080 pixels at 30P.
* Accord with Universal Serial Bus Specification Version 2.0.
* HDMI output 720 * 576 (50p).
* Video input: HDMI; Audio input: HDMI.
* Premium material guarantees a everlasting durability.

Specifications:

|Parameter | Value
|---|---
|Type |Video capture card
|Color |Black
|USB |USB 2.0
|HDMI input resolution |720x480 (30p), 720x576 (30p), 1280x720p (30P), 1280x720p (30p) 1920x1080 pixels at 30x, 1920x1080 pixels at 30P.
|Video/audio input |HDMI
|Dimension |8.7x3.1x1.3cm

System Requirement:
* P4 1.7GHz or higher.
* 256MB RAM.
* 32Mb VGA memory.
* USB2.0 port.
* Supports Windows XP/Vista/7/8/10 

Package list:
* 1x USB 2.0 HDMI Video Capture Card
* 1x Quick Start Guide
* 1x Software CD 

Sample Output
=============

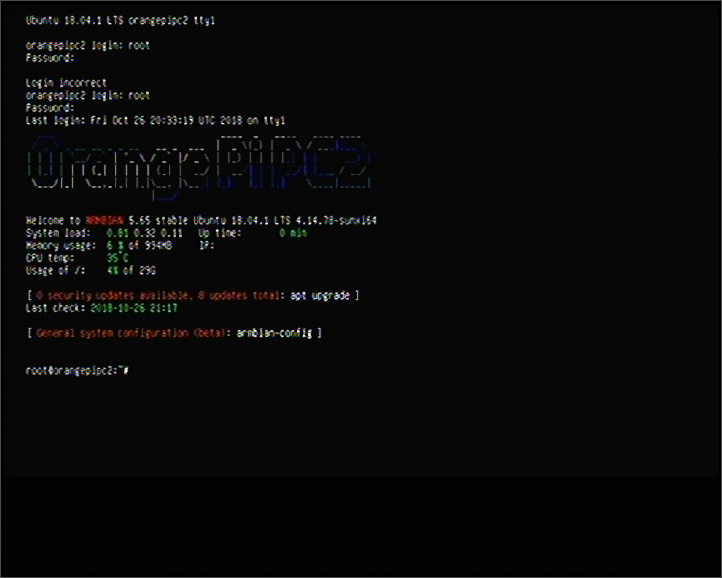
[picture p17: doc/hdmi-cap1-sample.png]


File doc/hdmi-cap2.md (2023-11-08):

HDMI Capture Variant 2
======================



Available at AliExpress.com (may look different now):
* https://www.aliexpress.com/item/33047139542.html
* https://www.aliexpress.com/item/4000162637370.html
* https://www.aliexpress.com/item/4000178966049.html
* https://www.aliexpress.com/item/1005002339348567.html

Moderate heat buildup at full resolution and frame rate.
Supports plug and play with a UVC and UVA compatible USB capture interface.

**On Windows 7:**  
Monitor (HDMI connection) is detected as `CAPTURE` with `GSM7666` (1920x1080).  
Capture device (USB connection) is detected as `FHD Capture` with `USB\VID_1BCF&PID_2C99&REV_0200&MI_00` for video and `USB\VID_1BCF&PID_2C99&REV_0200&MI_02` for audio.

[Included Manual (original)](hdmi-cap2.pdf)
===========================================

**USB 3.0 High Definition video capture, no driver support**  
**streaming media and live broadcast**

## 1. Introduction

It is a HDMI to USB3.0 High-definition Video Capture Dongle which no need
to install the drivers and supports plug and play. It features superior
performance, superior compatibility and easy to install & carry. It can
capture one single channel HD HDMI video signals and support the
resolution of Input and Output Video Signal up to 1080P@60Hz. In additional,
it has super compatibility, compatible with Windows, Linux, Mac OS X and
USB 3.0 interface. It will bring you much convenience and fun.

## 2. features

* USB 3.0 high-speed interface, which can record HD HDMI video to PC.
* UVC design, no need to install the drivers.
* Support most of the video software from windows system and the MAC system.
* Support video streaming, URL live and video conferencing, etc.
* Video Signal up to 1080P@60Hz

## 3. Application

It applies to a variety of fields include Medical, lecture recording, video
conference, live broadcast and IPTV, etc.

## 4. Specifications

|Connection |
|---|---
|Output |USB3.0 * 300-350MB/s bandwidth; USB3.0 40MB/s bandwidth
|Input |HDMI * 1
|HDMI Video input |1 * 1080P/60hz high definition HDMI signal
|HDMI Audio input |1 * LPCM Audio signal
|Standard |
|HDMI Input |HDMI 1.4a, support 1080p/60hz 8-bit, (RGB, YUV)
|Output |Resolution: 640 * 480, 720 * 480, 720 * 576, 800 * 600, 1280 * 720, 1280 * 800, 1280 * 960, 1280 * 1024, 1368 * 768, 960 * 540, 1024 * 576<br/>Frame rate: 25/29.97/30/50/59.94/60fps
|Video sampling rate |HDMI: 165MHZ
|Audio and Video capture  |UVC (USB video class), UAC (USB audio class)
|Color |YUY2, RGB24
|Video processing |
|Color space |Hardware
|Image zooming |Hardware
|Image adjustment |Brightness, contrast ratio, tone, saturation
|Others |
|System |X86 and X64 of Windows 7, Windows Server 2008 r2, Windows 8, Windows 8.1, Linux (Kernel version 2.6.38 and above), OS X (10.8 and Above)
|Compatibility |Windows Media Encoder (Windows), Adobe flash media live encoder (windows, OS X), Real Producer Plus (Windows), VLC (Windows, OS X, Linux), QuickTime Player (OS X), Wirecast (Windows, OS X), etc.

## 5. Installation Guide

Please confirm the package contents as below before you installation:
1) USB 3.0 to HDMI video capture * 1
2) User manual * 1

Installation Steps:
1) HDMI to USB3.0 video capture support hot-swappable. Please insert the USB 3.0 port to your PC.
2) USB3.0 is PnP device which do no need installation drivers, for example, POWER and ACTION LED work, then it works.

**Remind: Please insert  the HDMI cable at first, then insert the USB cable to the PC because the voltage of the HDMI port and the USB port is different. Otherwise, it is possible the product would not work correctly.**

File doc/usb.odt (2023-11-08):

USB Protocol

# Packets

Each packet transmits an integral number of bytes at the current transmission rate. Packets start with a synchronization pattern, followed by the data bytes of the packet, and concluded with an End-of-Packet (EOP) signal. All USB packet patterns are transmitted least significant bit first. Before and after the packet, the bus is in idle state.

A special packet is the Start-of-Frame packet (SOF) that splits the USB bus into time segments. Each pipe is allocated a slot in each frame. The Start-of-Frame packet is sent every 1ms on full speed links. At high speed, the 1ms frame is divided into 8 microframes of 125μs each. A Start-of-Frame packet is sent at the beginning of each microframe using the same frame number. The frame number increments every 1ms.

- Token packets
  - Initiate transaction

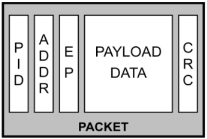
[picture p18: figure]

  - Identify device involved in transaction
  - Always sourced by the host
- Data packets
  - Delivers payload data
  - Sourced by host or device
- Handshake packets
  - Acknowledge error-free data receipt
  - Sourced by receiver of data
- Special packets

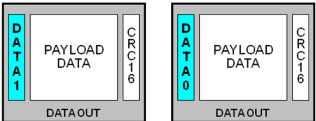
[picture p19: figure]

  - Facilitates speed differentials
  - Sourced by host-to-hub devices

# Transaction

1. The token packet is the header defining the transaction type and direction, the device address, and the endpoint.
2. Data is transferred in a data packet.
3. The final status of the transaction is acknowledges in the handshake packet.

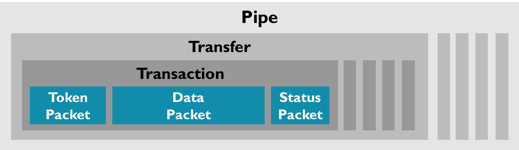
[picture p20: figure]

The transfer direction is specified in the token packet that is sent from the USB Host. Then, the source sends a data packet or indicates it has no data to transfer. In general, the destination responds with a handshake packet indicating whether the transfer was successful.

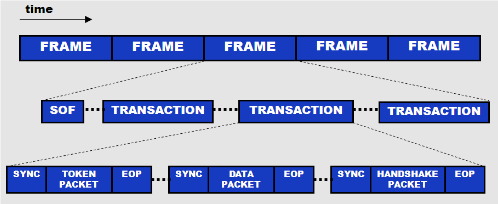
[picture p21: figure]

# Transfers

Transfers (data flow types) can consist of one or more transactions. A pipe supports only one of the following transfer types:

- Control Transfers are typically used to setup an USB device. They always use IN/OUT Endpoint 0.
- Interrupt Transfers can be used where data is sent regularly, for example for status updates.
- Isochronous Transfers transmit real-time data such as audio and video. They have a guaranteed, fixed bandwidth, but no error detection.
- Bulk Transfers can be used to send data where timing is not important, for example to a printer.

# Pipes

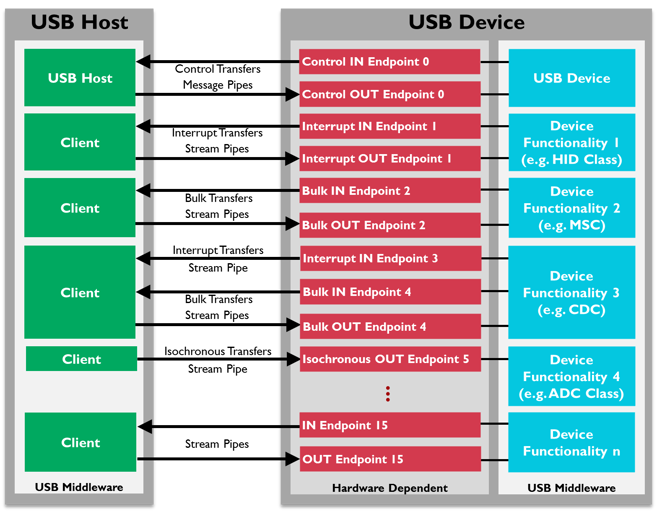
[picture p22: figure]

- Message pipes have a defined USB format and are host controlled. Message pipes allow data to flow in both directions and support Control Transfers only.
- Stream pipes have no defined USB format and can either be controlled by the host or by the device. The data stream has a predefined direction, either IN or OUT. Stream pipes support Interrupt Transfers, Isochronous Transfers, and Bulk Transfers.

Most pipes come into existence when an USB Device has been connected to the USB Bus and configured by the USB Host. A pipe originates from a data buffer within the host client and terminates inside the USB Device at an Endpoint.

# Endpoints

- A device can have up to 16 OUT and 16 IN endpoints.
- Each endpoint can have only one transfer direction.
- Endpoint 0 is used for control transfers only and can not be assigned to any other function.
- OUT always refers to the direction pointing from the host to the device.
- IN always refers to the direction pointing towards the host.

The total number of endpoints and the capability of each endpoint is defined by the underlying hardware.

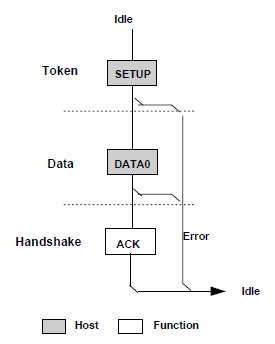
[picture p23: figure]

# Control Transfers

Control Transfers are bi-directional transfers reserved for the host to send and request configuration information to and from the device using the IN and OUT Endpoint 0.

Control Transfers have three stages:

1. The SETUP stage carries 8 bytes called the Setup packet, defining the request, and specifying how many data should be transferred in the DATA stage.
2. The DATA stage is optional. If present, it always starts with a transaction containing a DATA1 packet. Then, the transaction type alternates between DATA0 and DATA1 until all required data have been transferred.
3. The STATUS stage is a transaction containing a zero-length DATA1 packet. If the DATA stage was IN, then the STATUS stage is OUT, and vice-versa.

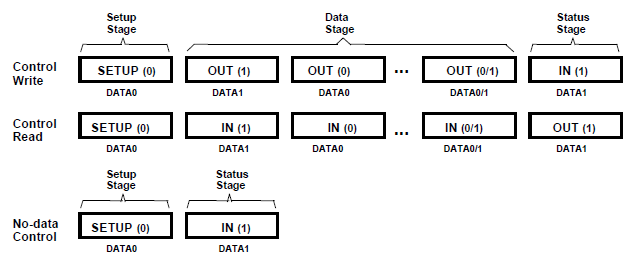
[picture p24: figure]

► https://www.beyondlogic.org/usbnutshell/usb4.shtml

References:

- https://www.cypress.com/file/134171/download
- https://www.beyondlogic.org/usbnutshell/usb3.shtml#USBProtocols
- https://www.keil.com/pack/doc/mw/USB/html/_u_s_b__endpoints.html
- http://www.usbmadesimple.co.uk/ums_4.htm

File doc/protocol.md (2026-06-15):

Serial Protocol
===============

The VKVM control and periphery communicate via USB CDC like a serial device.
This makes it necessary to use a proper framing protocol.
All related function to this are included in [Framing.hpp](../src/vkm-periphery/Framing.hpp).
The framing is done similar to [RFC 1662][RFC1662] with `0x7E` as start/stop byte,
`0x7D` as escape byte, which indicates that the next byte is XOR `0x20` to quote bytes
used for framing. The actual frame has the following structure with all bytes except
STX/ETX being properly quoted.

|Byte |Size |Field|Description |
|----:|----:|-----|---|
| 0| 1|STX  |Start of frame (`0x7E`). |
| 1| 1|SEQ  |Frame sequence number. |
| 2|  N-5|DATA |User payload. |
|  N-3| 2|CRC16|CRC16 over the unquoted payload.|
|  N-1| 1|ETX  |End of frame (`0x7E`). |

CRC16-CCITT like in HDLC (see [RFC 1662][RFC1662]) is being used here.

[RFC1662]: https://www.rfc-editor.org/rfc/rfc1662

### Constants

|Field |Name |Value |Description |
|---|---|-----:|---|
|RES |S_OK |  0x00|The request has been processed. |
|RES |I_USB_STATE_UPDATE |  0x40|Updated event of the USB periphery state.|
|RES |I_LED_UPDATE |  0x41|Updated event of the LED states. |
|RES |D_MESSAGE |  0x60|Debug message. |
|RES |E_BROKEN_FRAME |  0x80|Received broken frame. |
|RES |E_UNSUPPORTED_REQ_TYPE |  0x81|Received unsupported request type. |
|RES |E_INVALID_REQ_TYPE |  0x82|Received invalid request type. |
|RES |E_INVALID_FIELD_VALUE |  0x83|Received invalid field value. |
|RES |E_HOST_WRITE_ERROR |  0x85|Failed write to remote host. |
|REQ |GET_PROTOCOL_VERSION |  0x00|Request protocol version. |
|REQ |GET_ALIVE |  0x01|Request keep alive. |
|REQ |GET_USB_STATE |  0x02|Request USB periphery state. |
|REQ |GET_KEYBOARD_LEDS |  0x03|Request keyboard LED states. |
|REQ |SET_KEYBOARD_DOWN |  0x04|Push keyboard key down. |
|REQ |SET_KEYBOARD_UP |  0x05|Release keyboard key. |
|REQ |SET_KEYBOARD_ALL_UP |  0x06|Release all keyboard keys. |
|REQ |SET_KEYBOARD_PUSH |  0x07|Single push keyboard key. |
|REQ |SET_KEYBOARD_WRITE |  0x08|Write keyboard keys. |
|REQ |SET_MOUSE_BUTTON_DOWN |  0x09|Push mouse button down. |
|REQ |SET_MOUSE_BUTTON_UP |  0x0A|Release mouse button. |
|REQ |SET_MOUSE_BUTTON_ALL_UP |  0x0B|Release all mouse buttons. |
|REQ |SET_MOUSE_BUTTON_PUSH |  0x0C|Single push mouse button. |
|REQ |SET_MOUSE_MOVE_ABS |  0x0D|Absolute mouse movement. |
|REQ |SET_MOUSE_MOVE_REL |  0x0E|Relative mouse movement. |
|REQ |SET_MOUSE_SCROLL |  0x0F|Mouse wheel change. |
|USB |USBSTATE_OFF |  0x00|USB periphery is physically disconnected.|
|USB |USBSTATE_ON |  0x01|USB periphery is physically connected. |
|USB |USBSTATE_CONFIGURED |  0x02|USB periphery is configured by host. |
|USB |USBSTATE_ON_CONFIGURED |  0x03|USB periphery is fully functional. |
|USB |USBSTATE_BOOT_KEYBOARD |  0x04|USB periphery is in keyboard boot mode.  |
|USB |USBSTATE_BOOT_REL_MOUSE |  0x08|USB periphery is in rel mouse boot mode. |
|USB |USBSTATE_BOOT_ABS_MOUSE |  0x10|USB periphery is in abs mouse boot mode. |
|LED&#185; |USBLED_NUM_LOCK |  0x01|Num lock key status. |
|LED&#185; |USBLED_CAPS_LOCK |  0x02|Caps lock key status. |
|LED&#185; |USBLED_SCROLL_LOCK |  0x04|Scroll lock key status. |
|LED&#185; |USBLED_COMPOSE |  0x08|Composition mode enabled status. |
|LED&#185; |USBLED_KANA |  0x10|Kana key status. |
|LED&#185; |USBLED_POWER |  0x20|Power status. |
|LED&#185; |USBLED_SHIFT |  0x40|Shift function status. |
|LED&#185; |USBLED_DO_NOT_DISTURB |  0x80|Shift function status. |
|KEY&#178; |USBKEY_NO_EVENT |  0x00|No keyboard event indicator. |
|KEY&#178; |USBKEY_ERROR_ROLL_OVER |  0x01|Keyboard ErrorRollOver |
|KEY&#178; |USBKEY_POST_FAIL |  0x02|Keyboard POSTFail |
|KEY&#178; |USBKEY_ERROR_UNDEFINED |  0x03|Keyboard ErrorUndeﬁned |
|KEY&#178; |USBKEY_A |  0x04|Keyboard a and A |
|KEY&#178; |USBKEY_B |  0x05|Keyboard b and B |
|KEY&#178; |USBKEY_C |  0x06|Keyboard c and C |
|KEY&#178; |USBKEY_D |  0x07|Keyboard d and D |
|KEY&#178; |USBKEY_E |  0x08|Keyboard e and E |
|KEY&#178; |USBKEY_F |  0x09|Keyboard f and F |
|KEY&#178; |USBKEY_G |  0x0A|Keyboard g and G |
|KEY&#178; |USBKEY_H |  0x0B|Keyboard h and H |
|KEY&#178; |USBKEY_I |  0x0C|Keyboard i and I |
|KEY&#178; |USBKEY_J |  0x0D|Keyboard j and J |
|KEY&#178; |USBKEY_K |  0x0E|Keyboard k and K |
|KEY&#178; |USBKEY_L |  0x0F|Keyboard l and L |
|KEY&#178; |USBKEY_M |  0x10|Keyboard m and M |
|KEY&#178; |USBKEY_N |  0x11|Keyboard n and N |
|KEY&#178; |USBKEY_O |  0x12|Keyboard o and O |
|KEY&#178; |USBKEY_P |  0x13|Keyboard p and P |
|KEY&#178; |USBKEY_Q |  0x14|Keyboard q and Q |
|KEY&#178; |USBKEY_R |  0x15|Keyboard r and R |
|KEY&#178; |USBKEY_S |  0x16|Keyboard s and S |
|KEY&#178; |USBKEY_T |  0x17|Keyboard t and T |
|KEY&#178; |USBKEY_U |  0x18|Keyboard u and U |
|KEY&#178; |USBKEY_V |  0x19|Keyboard v and V |
|KEY&#178; |USBKEY_W |  0x1A|Keyboard w and W |
|KEY&#178; |USBKEY_X |  0x1B|Keyboard x and X |
|KEY&#178; |USBKEY_Y |  0x1C|Keyboard y and Y |
|KEY&#178; |USBKEY_Z |  0x1D|Keyboard z and Z |
|KEY&#178; |USBKEY_1 |  0x1E|Keyboard 1 and ! |
|KEY&#178; |USBKEY_2 |  0x1F|Keyboard 2 and @ |
|KEY&#178; |USBKEY_3 |  0x20|Keyboard 3 and # |
|KEY&#178; |USBKEY_4 |  0x21|Keyboard 4 and $ |
|KEY&#178; |USBKEY_5 |  0x22|Keyboard 5 and % |
|KEY&#178; |USBKEY_6 |  0x23|Keyboard 6 and ^ |
|KEY&#178; |USBKEY_7 |  0x24|Keyboard 7 and & |
|KEY&#178; |USBKEY_8 |  0x25|Keyboard 8 and * |
|KEY&#178; |USBKEY_9 |  0x26|Keyboard 9 and ( |
|KEY&#178; |USBKEY_0 |  0x27|Keyboard 0 and ) |
|KEY&#178; |USBKEY_ENTER |  0x28|Keyboard Return (ENTER) |
|KEY&#178; |USBKEY_ESCAPE |  0x29|Keyboard ESCAPE |
|KEY&#178; |USBKEY_BACKSPACE |  0x2A|Keyboard DELETE (Backspace) |
|KEY&#178; |USBKEY_TAB |  0x2B|Keyboard Tab |
|KEY&#178; |USBKEY_SPACE |  0x2C|Keyboard Spacebar |
|KEY&#178; |USBKEY_MINUS |  0x2D|Keyboard - and (underscore) |
|KEY&#178; |USBKEY_EQUAL |  0x2E|Keyboard = and + |
|KEY&#178; |USBKEY_OPEN_BRACKET |  0x2F|Keyboard \[ and { |
|KEY&#178; |USBKEY_CLOSE_BRACKET |  0x30|Keyboard ] and } |
|KEY&#178; |USBKEY_BACKSLASH |  0x31|Keyboard \\ and &#124; |
|KEY&#178; |USBKEY_NON_US_HASH |  0x32|Keyboard Non-US # and ˜ |
|KEY&#178; |USBKEY_SEMICOLON |  0x33|Keyboard ; and : |
|KEY&#178; |USBKEY_APOSTROPHE |  0x34|Keyboard ‘ and “ |
|KEY&#178; |USBKEY_ACCENT |  0x35|Keyboard Grave Accent and Ti |
|KEY&#178; |USBKEY_COMMA |  0x36|Keyboard , and < |
|KEY&#178; |USBKEY_PERIOD |  0x37|Keyboard . and > |
|KEY&#178; |USBKEY_SLASH |  0x38|Keyboard / and ? |
|KEY&#178; |USBKEY_CAPS_LOCK |  0x39|Keyboard Caps Lock |
|KEY&#178; |USBKEY_F1 |  0x3A|Keyboard F1 |
|KEY&#178; |USBKEY_F2 |  0x3B|Keyboard F2 |
|KEY&#178; |USBKEY_F3 |  0x3C|Keyboard F3 |
|KEY&#178; |USBKEY_F4 |  0x3D|Keyboard F4 |
|KEY&#178; |USBKEY_F5 |  0x3E|Keyboard F5 |
|KEY&#178; |USBKEY_F6 |  0x3F|Keyboard F6 |
|KEY&#178; |USBKEY_F7 |  0x40|Keyboard F7 |
|KEY&#178; |USBKEY_F8 |  0x41|Keyboard F8 |
|KEY&#178; |USBKEY_F9 |  0x42|Keyboard F9 |
|KEY&#178; |USBKEY_F10 |  0x43|Keyboard F10 |
|KEY&#178; |USBKEY_F11 |  0x44|Keyboard F11 |
|KEY&#178; |USBKEY_F12 |  0x45|Keyboard F12 |
|KEY&#178; |USBKEY_PRINT_SCREEN |  0x46|Keyboard PrintScreen |
|KEY&#178; |USBKEY_SCROLL_LOCK |  0x47|Keyboard Scroll Lock |
|KEY&#178; |USBKEY_PAUSE |  0x48|Keyboard Pause |
|KEY&#178; |USBKEY_INSERT |  0x49|Keyboard Insert |
|KEY&#178; |USBKEY_HOME |  0x4A|Keyboard Home |
|KEY&#178; |USBKEY_PAGE_UP |  0x4B|Keyboard PageUp |
|KEY&#178; |USBKEY_DELETE |  0x4C|Keyboard Delete Forward |
|KEY&#178; |USBKEY_END |  0x4D|Keyboard End |
|KEY&#178; |USBKEY_PAGE_DOWN |  0x4E|Keyboard PageDown |
|KEY&#178; |USBKEY_RIGHT_ARROW |  0x4F|Keyboard RightArrow |
|KEY&#178; |USBKEY_LEFT_ARROW |  0x50|Keyboard LeftArrow |
|KEY&#178; |USBKEY_DOWN_ARROW |  0x51|Keyboard DownArrow |
|KEY&#178; |USBKEY_UP_ARROW |  0x52|Keyboard UpArrow |
|KEY&#178; |USBKEY_NUM_LOCK |  0x53|Keypad Num Lock and Clear |
|KEY&#178; |USBKEY_KP_DIVIDE |  0x54|Keypad / |
|KEY&#178; |USBKEY_KP_MULTIPLY |  0x55|Keypad * |
|KEY&#178; |USBKEY_KP_SUBTRACT |  0x56|Keypad - |
|KEY&#178; |USBKEY_KP_ADD |  0x57|Keypad + |
|KEY&#178; |USBKEY_KP_ENTER |  0x58|Keypad ENTER |
|KEY&#178; |USBKEY_KP_1 |  0x59|Keypad 1 and End |
|KEY&#178; |USBKEY_KP_2 |  0x5A|Keypad 2 and Down Arrow |
|KEY&#178; |USBKEY_KP_3 |  0x5B|Keypad 3 and PageDn |
|KEY&#178; |USBKEY_KP_4 |  0x5C|Keypad 4 and Left Arrow |
|KEY&#178; |USBKEY_KP_5 |  0x5D|Keypad 5 |
|KEY&#178; |USBKEY_KP_6 |  0x5E|Keypad 6 and Right Arrow |
|KEY&#178; |USBKEY_KP_7 |  0x5F|Keypad 7 and Home |
|KEY&#178; |USBKEY_KP_8 |  0x60|Keypad 8 and Up Arrow |
|KEY&#178; |USBKEY_KP_9 |  0x61|Keypad 9 and PageUp |
|KEY&#178; |USBKEY_KP_0 |  0x62|Keypad 0 and Insert |
|KEY&#178; |USBKEY_KP_DECIMAL |  0x63|Keypad . and Delete |
|KEY&#178; |USBKEY_NON_US_BACKSLASH |  0x64|Keyboard Non-US \\ and &#124; |
|KEY&#178; |USBKEY_APPLICATION |  0x65|Keyboard Application |
|KEY&#178; |USBKEY_POWER |  0x66|Keyboard Power |
|KEY&#178; |USBKEY_KP_EQUAL |  0x67|Keypad = |
|KEY&#178; |USBKEY_F13 |  0x68|Keyboard F13 |
|KEY&#178; |USBKEY_F14 |  0x69|Keyboard F14 |
|KEY&#178; |USBKEY_F15 |  0x6A|Keyboard F15 |
|KEY&#178; |USBKEY_F16 |  0x6B|Keyboard F16 |
|KEY&#178; |USBKEY_F17 |  0x6C|Keyboard F17 |
|KEY&#178; |USBKEY_F18 |  0x6D|Keyboard F18 |
|KEY&#178; |USBKEY_F19 |  0x6E|Keyboard F19 |
|KEY&#178; |USBKEY_F20 |  0x6F|Keyboard F20 |
|KEY&#178; |USBKEY_F21 |  0x70|Keyboard F21 |
|KEY&#178; |USBKEY_F22 |  0x71|Keyboard F22 |
|KEY&#178; |USBKEY_F23 |  0x72|Keyboard F23 |
|KEY&#178; |USBKEY_F24 |  0x73|Keyboard F24 |
|KEY&#178; |USBKEY_EXECUTE |  0x74|Keyboard Execute |
|KEY&#178; |USBKEY_HELP |  0x75|Keyboard Help |
|KEY&#178; |USBKEY_MENU |  0x76|Keyboard Menu |
|KEY&#178; |USBKEY_SELECT |  0x77|Keyboard Select |
|KEY&#178; |USBKEY_STOP |  0x78|Keyboard Stop |
|KEY&#178; |USBKEY_AGAIN |  0x79|Keyboard Again |
|KEY&#178; |USBKEY_UNDO |  0x7A|Keyboard Undo |
|KEY&#178; |USBKEY_CUT |  0x7B|Keyboard Cut |
|KEY&#178; |USBKEY_COPY |  0x7C|Keyboard Copy |
|KEY&#178; |USBKEY_PASTE |  0x7D|Keyboard Paste |
|KEY&#178; |USBKEY_FIND |  0x7E|Keyboard Find |
|KEY&#178; |USBKEY_MUTE |  0x7F|Keyboard Mute |
|KEY&#178; |USBKEY_VOLUME_UP |  0x80|Keyboard Volume Up |
|KEY&#178; |USBKEY_VOLUME_DOWN |  0x81|Keyboard Volume Down |
|KEY&#178; |USBKEY_LOCKING_CAPS_LOCK |  0x82|Keyboard Locking Caps Lock |
|KEY&#178; |USBKEY_LOCKING_NUM_LOCK |  0x83|Keyboard Locking Num Lock |
|KEY&#178; |USBKEY_LOCKING_SCROLL_LOCK |  0x84|Keyboard Locking Scroll Lock |
|KEY&#178; |USBKEY_KP_COMMA |  0x85|Keypad Comma |
|KEY&#178; |USBKEY_KP_EQUAL_SIGN |  0x86|Keypad Equal Sign |
|KEY&#178; |USBKEY_INT_1 |  0x87|Keyboard International1 |
|KEY&#178; |USBKEY_INT_2 |  0x88|Keyboard International2 |
|KEY&#178; |USBKEY_INT_3 |  0x89|Keyboard International3 |
|KEY&#178; |USBKEY_INT_4 |  0x8A|Keyboard International4 |
|KEY&#178; |USBKEY_INT_5 |  0x8B|Keyboard International5 |
|KEY&#178; |USBKEY_INT_6 |  0x8C|Keyboard International6 |
|KEY&#178; |USBKEY_INT_7 |  0x8D|Keyboard International7 |
|KEY&#178; |USBKEY_INT_8 |  0x8E|Keyboard International8 |
|KEY&#178; |USBKEY_INT_9 |  0x8F|Keyboard International9 |
|KEY&#178; |USBKEY_IME_KANA |  0x88|Keyboard International1 |
|KEY&#178; |USBKEY_IME_CONVERT |  0x8A|Keyboard International2 |
|KEY&#178; |USBKEY_IME_NONCONVERT |  0x8B|Keyboard International3 |
|KEY&#178; |USBKEY_LANG_1 |  0x90|Keyboard LANG1 |
|KEY&#178; |USBKEY_LANG_2 |  0x91|Keyboard LANG2 |
|KEY&#178; |USBKEY_LANG_3 |  0x92|Keyboard LANG3 |
|KEY&#178; |USBKEY_LANG_4 |  0x93|Keyboard LANG4 |
|KEY&#178; |USBKEY_LANG_5 |  0x94|Keyboard LANG5 |
|KEY&#178; |USBKEY_LANG_6 |  0x95|Keyboard LANG6 |
|KEY&#178; |USBKEY_LANG_7 |  0x96|Keyboard LANG7 |
|KEY&#178; |USBKEY_LANG_8 |  0x97|Keyboard LANG8 |
|KEY&#178; |USBKEY_LANG_9 |  0x98|Keyboard LANG9 |
|KEY&#178; |USBKEY_ALT_ERASE |  0x99|Keyboard Alternate Erase |
|KEY&#178; |USBKEY_ATTN |  0x9A|Keyboard SysReq/Attention |
|KEY&#178; |USBKEY_CANCEL |  0x9B|Keyboard Cancel |
|KEY&#178; |USBKEY_CLEAR |  0x9C|Keyboard Clear |
|KEY&#178; |USBKEY_PRIOR |  0x9D|Keyboard Prior |
|KEY&#178; |USBKEY_RETURN |  0x9E|Keyboard Return |
|KEY&#178; |USBKEY_SEPARATOR |  0x9F|Keyboard Separator |
|KEY&#178; |USBKEY_OUT |  0xA0|Keyboard Out |
|KEY&#178; |USBKEY_OPER |  0xA1|Keyboard Oper |
|KEY&#178; |USBKEY_CLEAR_AGAIN |  0xA2|Keyboard Clear/Again |
|KEY&#178; |USBKEY_CRSEL_PROPS |  0xA3|Keyboard CrSel/Props |
|KEY&#178; |USBKEY_EXSEL |  0xA4|Keyboard ExSel |
|KEY&#178; |USBKEY_KP_00 |  0xB0|Keypad 00 |
|KEY&#178; |USBKEY_KP_000 |  0xB1|Keypad 000 |
|KEY&#178; |USBKEY_THOUSENDS_SEP |  0xB2|Thousands Separator |
|KEY&#178; |USBKEY_DECIMAL_SEP |  0xB3|Decimal Separator |
|KEY&#178; |USBKEY_CURRENCY_UNIT |  0xB4|Currency Unit |
|KEY&#178; |USBKEY_CURRENCY_SUB_UNIT |  0xB5|Currency Sub-unit |
|KEY&#178; |USBKEY_KP_OPEN_BRACKET |  0xB6|Keypad ( |
|KEY&#178; |USBKEY_KP_CLOSE_BRACKET |  0xB7|Keypad ) |
|KEY&#178; |USBKEY_KP_OPEN_CURLY_BRACKET  |  0xB8|Keypad { |
|KEY&#178; |USBKEY_KP_CLOSE_CURLY_BRACKET |  0xB9|Keypad } |
|KEY&#178; |USBKEY_KP_TAB |  0xBA|Keypad Tab |
|KEY&#178; |USBKEY_KP_BACKSPACE |  0xBB|Keypad Backspace |
|KEY&#178; |USBKEY_KP_A |  0xBC|Keypad A |
|KEY&#178; |USBKEY_KP_B |  0xBD|Keypad B |
|KEY&#178; |USBKEY_KP_C |  0xBE|Keypad C |
|KEY&#178; |USBKEY_KP_D |  0xBF|Keypad D |
|KEY&#178; |USBKEY_KP_E |  0xC0|Keypad E |
|KEY&#178; |USBKEY_KP_F |  0xC1|Keypad F |
|KEY&#178; |USBKEY_KP_XOR |  0xC2|Keypad XOR |
|KEY&#178; |USBKEY_KP_CARET |  0xC3|Keypad ^ |
|KEY&#178; |USBKEY_KP_PERCENT |  0xC4|Keypad % |
|KEY&#178; |USBKEY_KP_LESS |  0xC5|Keypad < |
|KEY&#178; |USBKEY_KP_GREATER |  0xC6|Keypad > |
|KEY&#178; |USBKEY_KP_AND |  0xC7|Keypad & |
|KEY&#178; |USBKEY_KP_AND2 |  0xC8|Keypad && |
|KEY&#178; |USBKEY_KP_OR |  0xC9|Keypad &#124; |
|KEY&#178; |USBKEY_KP_OR2 |  0xCA|Keypad &#124;&#124; |
|KEY&#178; |USBKEY_KP_COLON |  0xCB|Keypad : |
|KEY&#178; |USBKEY_KP_HASH |  0xCC|Keypad # |
|KEY&#178; |USBKEY_KP_SPACE |  0xCD|Keypad Space |
|KEY&#178; |USBKEY_KP_AT |  0xCE|Keypad @ |
|KEY&#178; |USBKEY_KP_EXCLAMATION |  0xCF|Keypad ! |
|KEY&#178; |USBKEY_KP_MEM_STORE |  0xD0|Keypad Memory Store |
|KEY&#178; |USBKEY_KP_MEM_RECALL |  0xD1|Keypad Memory Recall |
|KEY&#178; |USBKEY_KP_MEM_CLEAR |  0xD2|Keypad Memory Clear |
|KEY&#178; |USBKEY_KP_MEM_ADD |  0xD3|Keypad Memory Add |
|KEY&#178; |USBKEY_KP_MEM_SUB |  0xD4|Keypad Memory Subtract |
|KEY&#178; |USBKEY_KP_MEM_MUL |  0xD5|Keypad Memory Multiply |
|KEY&#178; |USBKEY_KP_MEM_DIV |  0xD6|Keypad Memory Divide |
|KEY&#178; |USBKEY_KP_PLUS_MINUS |  0xD7|Keypad +/- |
|KEY&#178; |USBKEY_KP_CLEAR |  0xD8|Keypad Clear |
|KEY&#178; |USBKEY_KP_CLEAR_ENTRY |  0xD9|Keypad Clear Entry |
|KEY&#178; |USBKEY_KP_BIN |  0xDA|Keypad Binary |
|KEY&#178; |USBKEY_KP_OCT |  0xDB|Keypad Octal |
|KEY&#178; |USBKEY_KP_DEC |  0xDC|Keypad Decimal |
|KEY&#178; |USBKEY_KP_HEX |  0xDD|Keypad Hexadecimal |
|KEY&#178; |USBKEY_LEFT_CONTROL |  0xE0|Keyboard LeftControl |
|KEY&#178; |USBKEY_LEFT_SHIFT |  0xE1|Keyboard LeftShift |
|KEY&#178; |USBKEY_LEFT_ALT |  0xE2|Keyboard LeftAlt |
|KEY&#178; |USBKEY_LEFT_GUI |  0xE3|Keyboard Left GUI |
|KEY&#178; |USBKEY_RIGHT_CONTROL |  0xE4|Keyboard RightControl |
|KEY&#178; |USBKEY_RIGHT_SHIFT |  0xE5|Keyboard RightShift |
|KEY&#178; |USBKEY_RIGHT_ALT |  0xE6|Keyboard RightAlt |
|KEY&#178; |USBKEY_RIGHT_GUI |  0xE7|Keyboard Right GUI |
|MOD |USBWRITE_LEFT_CONTROL |  0x01|Left control key is being pressed. |
|MOD |USBWRITE_LEFT_SHIFT |  0x02|Left shift key is being pressed. |
|MOD |USBWRITE_LEFT_ALT |  0x04|Left alt key is being pressed. |
|MOD |USBWRITE_RIGHT_CONTROL |  0x08|Right control key is being pressed. |
|MOD |USBWRITE_RIGHT_SHIFT |  0x10|Right shift key is being pressed. |
|MOD |USBWRITE_RIGHT_ALT |  0x20|Right alt key is being pressed. |
|MOD |USBWRITE_RIGHT_NUM_LOCK |  0x40|Num lock is active. |
|MOD |USBWRITE_RIGHT_KANA |  0x80|Kana is being enabled. |
|BUTTON&#179; |USBBUTTON_LEFT |  0x01|Button 1 (primary/trigger) |
|BUTTON&#179; |USBBUTTON_RIGHT |  0x02|Button 2 (secondary) |
|BUTTON&#179; |USBBUTTON_MIDDLE |  0x04|Button 3 (tertiary) |

1\) See also [HID Usage Tables for USB v1.2 ch. 11](https://www.usb.org/sites/default/files/hut1_2.pdf#page=91) for LED values.  
2\) See also [HID Usage Tables for USB v1.2 ch. 10](https://www.usb.org/sites/default/files/hut1_2.pdf#page=83) for keyboard key values.  
3\) See also [HID Usage Tables for USB v1.2 ch. 12](https://www.usb.org/sites/default/files/hut1_2.pdf#page=103) for mouse button values.  

### Request/Response Fields

|Size |C Type  |Name |Description |
|----:|---:|---|---|
| 1| uint8_t|KEY |Keyboard key values. Up to 6 |
| 1| uint8_t|NKEY |Number of keys processed. |
| 1| uint8_t|MOD |Keyboard key modifier. |
| 1| uint8_t|USB |USB periphery state. |
| 1| uint8_t|LED |Keyboard LED bits. |
| 1| uint8_t|BUTTON  |Mouse button value. |
| 1| uint8_t|NBUTTON |Number of buttons processed. |
| 1|  int8_t|REL_X |Relative mouse x coordinate. |
| 1|  int8_t|REL_Y |Relative mouse y coordinate. |
| 1|  int8_t|WHEEL |Relative mouse wheel change. |
| 2| int16_t|ABS_X |Absolute mouse x coordinate. |
| 2| int16_t|ABS_Y |Absolute mouse y coordinate. |
| 2|uint16_t|VER |Protocol version (0x0101). |

### Request Message

The user payload is structured as following for requests (control &#8680; periphery).

|Byte |Size |Field |Description |
|----:|----:|---|---|
| 0| 1|REQ |Request type. |
| 1|  N-1|FIELDS|Request fields (optional).|

### Response Message

The user payload is structured as following for responses (control &#8678; periphery).

|Byte |Size |Field |Description |
|----:|----:|---|---|
| 0| 1|RES |Response type. |
| 1|  N-1|FIELDS|Response fields (optional).|

### Request/Response Description

The following request/response messages are defined including unsolicited responses.

|Name |Request Fields |Response Fields |
|---|---|---|
|GET_PROTOCOL_VERSION |- |VER |
|GET_ALIVE |- |- |
|GET_USB_STATE |- |USB |
|GET_KEYBOARD_LEDS |- |LED |
|SET_KEYBOARD_DOWN |KEY\[1..6] |- |
|SET_KEYBOARD_UP |KEY\[1..6] |- |
|SET_KEYBOARD_ALL_UP |- |- |
|SET_KEYBOARD_PUSH |KEY\[0..N]&#185; |NKEY |
|SET_KEYBOARD_WRITE |MOD, KEY\[0..N]&#185;|NKEY |
|SET_MOUSE_BUTTON_DOWN |BUTTON\[1..3] |- |
|SET_MOUSE_BUTTON_UP |BUTTON\[1..3] |- |
|SET_MOUSE_BUTTON_ALL_UP |- |- |
|SET_MOUSE_BUTTON_PUSH |BUTTON\[0..N]&#185;  |NBUTTON |
|SET_MOUSE_MOVE_ABS |ABS_X, ABS_Y |- |
|SET_MOUSE_MOVE_REL |REL_X, REL_Y |- |
|SET_MOUSE_SCROLL |WHEEL |- |
|USB state update interrupt&#178;|- |USB |
|LED update interrupt&#179; |- |LED |
|DEBUG message&#8308; |- |<arbitrary string>|

1\) The maximum frame size is 256 bytes which limits the maximum number of keys/buttons per request.  
2\) The USB state update interrupt has the sequence number 0 and response type I_USB_STATE_UPDATE.  
3\) The LED update interrupt has the sequence number 0 and response type I_LED_UPDATE.  
4\) The DEBUG message has the sequence number 0 and response type D_MESSAGE.

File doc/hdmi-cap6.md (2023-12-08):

HDMI Capture Variant 6
======================



Available at AliExpress.com:
* https://www.aliexpress.com/item/1005005567572444.html
* https://www.aliexpress.com/item/1005005936067068.html
* https://www.aliexpress.com/item/1005005940071989.html

Supports plug and play with a UVC and UVA compatible USB capture interface.

**On Windows 7:**  
Monitor (HDMI connection) is detected as `1. HDMI Encoder` with `___8360` (3840x2160, 1920x1080 recommended).  
Capture device (USB connection) is detected as `Display capture-UVC05` with `USB\VID_1DE1&PID_F105&REV_0409&MI_00` for video and `Display capture-UVC05` with `USB\VID_1DE1&PID_F105&REV_0409&MI_02` for audio.

Description
===========

Specifications
--------------

* Brand: Unnlink
* Name: HDMI to USB/Type-C Video Capture Card
* Input: HDMI(4K30fps)
* Output: USB/Type-C(1080P60fps-record)
* USB version: USB2.0
* Shell: Alloy

Package
-------

* 1x Video Capture Card
* 1x Manual


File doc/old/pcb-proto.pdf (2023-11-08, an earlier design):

PCB Prototyping

Iteration | Total
Type | Fix Costs | Costs | Duration | Costs | Duration | 1x Stencil | Solderable | Reflow | Reference
toner+silver adhesive | 20,00 € | 0,50 € | 00:10:00 | 22,50 € | 00:50:00 | no | no | yes | https://www.youtube.com/watch?v=mwwA1d2s2OQhttps://en.wikipedia.org/wiki/Flexible_electronics
manufacturer | 0,00 € | 5,00 € | 1680:00:00 | 25,00 € | 8400:00:00 | 16,00 € | yes | yes | https://www.smart-prototyping.com/PCB-Prototyping.html
toner+etching | 20,00 € | 10,00 € | 01:00:00 | 70,00 € | 05:00:00 | no | yes | yes | https://www.mikrocontroller.net/articles/Platinenherstellung_mit_der_Tonertransfermethodehttps://www.youtube.com/watch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
pen+etching | 100,00 € | 10,00 € | 01:00:00 | 150,00 € | 05:00:00 | no | yes | yes | https://www.youtube.com/watch?v=oPVc9ixj0iU
inkjet with graphene ink | 260,00 € | 0,50 € | 00:01:00 | 262,50 € | 00:05:00 | no | no | yes | https://www.instructables.com/id/Print-Conductive-Circuits-With-An-Inkjet-Printer/https://cambridgenanosystems.com/product/camink-sp/https://www.youtube.com/watch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
standard 3D printer | 300,00 € | 5,00 € | 04:00:00 | 325,00 € | 20:00:00 | 5,00 € | no | no | https://www.blackmagic3d.com/Conductive-p/grphn-pla.htm
laser+etching | 300,00 € | 10,00 € | 01:00:00 | 350,00 € | 05:00:00 | 2,00 € | yes | yes | https://www.youtube.com/watch?v=1hFNj86L7skhttps://www.youtube.com/watch?v=ZzO9skEYqwY
laser+curing | 300,00 € | 10,00 € | 01:00:00 | 350,00 € | 05:00:00 | 3,00 € | yes | yes | https://www.youtube.com/watch?v=Z228xymQYho
inkjet with silver nano particle ink | 350,00 € | 0,50 € | 00:01:00 | 352,50 € | 00:05:00 | no | no | yes | https://www.instructables.com/id/Print-Conductive-Circuits-With-An-Inkjet-Printer/http://diamond-jet.com/silvernanoinkjetsystem.aspx
laser cutter (15W blue laser) | 400,00 € | 5,00 € | 00:30:00 | 425,00 € | 02:30:00 | 5,00 € | yes | yes
CNC mill for PCB | 1.600,00 € | 5,00 € | 01:00:00 | 1.625,00 € | 05:00:00 | 5,00 € | yes | yes | https://www.zippyrobotics.com/
special 3D printer | 3.000,00 € | 20,00 € | 01:00:00 | 3.100,00 € | 05:00:00 | unneeded | yes | included | https://www.voltera.io/store/
laser cutter (50W fiber laser) | 6.000,00 € | 5,00 € | 00:30:00 | 6.025,00 € | 02:30:00 | 5,00 € | yes | yes

Target: 5 iterations with 2 PCBs each, 16mil width/spacing, single layer

https://de.aliexpress.com/item/Assembled-15W-laser-15000MW-diy-laser-engraving-machine-14-20cm-metal-engraver-marking-machine-metal-carving/32776808845.html

https://de.aliexpress.com/item/Raycus-IPG-faserlaser-50-Watt-laserbeschriftungsanlage-faser-laserbeschriftungsanlage-30-Watt-20-Watt-50-watt-100-watt/32852134879.htm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

## Etching Techniques

### CuCl can be recycled by electrolysis

Type | Chemicals | Reference
Standard | FeCl3 | https://www.youtube.com/watch?v=tWnfnt2rNO0
Standard | Na2S2O8 | https://www.youtube.com/watch?v=fCUWmfDF_ho
Standard | MnO2, HCl | https://www.youtube.com/watch?v=qE-PBOXzpbQ
Sponge | FeCl3 | https://www.youtube.com/watch?v=M0Gy8ISjvhE
Electrolysis | H2O, NaCl | https://www.youtube.com/watch?v=L4KyRhFN4qUhttps://www.youtube.com/watch?v=ANwnmT1PLH8

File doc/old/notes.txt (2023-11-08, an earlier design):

VKVM (Virtual Keyboard Video Mouse) Adapter
===========================================

- provide USB keyboard/mouse and VGA connector to slave
- offer screen and keyboard/mouse control to master
- ESP8266 for remote access
- Windows Keyboard Hooks: http://ntcoder.com/bab/2007/06/12/wh_keyboard_ll/
- OpenGL Keyboard Mouse Events with glutKeyboardFunc() and glutMouseFunc()
- Linux Keyboard/Mouse Hooks: https://gist.github.com/matthewaveryusa/a721aad80ae89a5c69f7c964fa20fec1

- Monitor Boards (to LVDS):
  3EUR http://cnd.manufacturer.globalsources.com/si/6008834407515/pdtl/LCD-controller/1159217153/LVDS-LCD-controller-board.htm
  3EUR http://cnd.manufacturer.globalsources.com/si/6008834407515/pdtl/LCD-controller/1158952800/LCD-Monitor-VGA-Board.htm
  5EUR http://cnd.manufacturer.globalsources.com/si/6008834407515/pdtl/LCD-controller/1160399179/LCD-panel-controller-board.htm
  5EUR https://www.pollin.de/p/lvds-interface-pi-mt6820-vga-zu-lvds-810220

- VGA decoder IC:
! http://www.ti.com/lit/ds/symlink/tvp7002.pdf
  -> 5EUR https://www.digikey.com/product-detail/en/texas-instruments/TVP7002PZPR/296-41784-2-ND/1910137
  -> 7EUR https://www.mouser.de/ProductDetail/Texas-Instruments/TVP7002PZPR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
  https://media.digikey.com/pdf/Data%20Sheets/Texas%20Instruments%20PDFs/TVP5146.pdf
  -> 4EUR https://www.aliexpress.com/item/TVP5146PFP-TVP5146-QFP-100-Original/32830664185.html
  -> 8EUR https://www.mouser.de/ProductDetail/Texas-Instruments/TVP5146M2PFP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
  -> 8EUR https://www.digikey.de/product-detail/de/texas-instruments/TVP5146M2PFP/296-18306-ND/807613
  https://www.intersil.com/content/dam/Intersil/documents/tw88/tw8832-32s.pdf
  -> 7EUR https://www.aliexpress.com/item/TW8832S-LB1-CR-80LQFP-TW8832S-LB1-CR-8832-TW8832S-TW8832-1PCS/1000006347742.html
  -> 8EUR https://www.digikey.de/product-detail/de/renesas-electronics-america-inc/TW8832-LB1-CR/TW8832-LB1-CR-ND/2773224
  -> 8EUR https://www.mouser.de/ProductDetail/Renesas-Intersil/TW8832-LB1-CR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
  https://www.intersil.com/content/dam/Intersil/documents/tw88/tw8830.pdf
  -> 7EUR https://www.digikey.de/products/de?keywords=TW8830
  https://www.intersil.com/content/dam/Intersil/documents/isl7/isl79985-86.pdf
  -> 10EUR https://www.mouser.de/ProductDetail/Renesas-Intersil/ISL79985IRZ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
  https://media.digikey.com/pdf/Data%20Sheets/Texas%20Instruments%20PDFs/THS8200.pdf
  -> 7EUR https://www.digikey.de/product-detail/de/texas-instruments/THS8200PFP/296-15622-ND/571452
  -> 7EUR https://www.mouser.de/ProductDetail/Texas-Instruments/THS8200PFP?qs=sGAEpiMZZMuo%252bmZx5g6tFBtdy9TJ1eQT
  http://www.ti.com/product/TVP70025I
  -> 9EUR https://www.digikey.de/product-detail/de/texas-instruments/TVP70025IPZP/296-23680-ND/1910134
  https://www.marutsu.co.jp/contents/shop/marutsu/ds/tw8835.pdf
  -> 10EUR https://www.digikey.de/product-detail/de/renesas-electronics-america-inc/TW8835-LA2-CR/TW8835-LA2-CR-ND/3178336
  http://www.analog.com/media/en/technical-documentation/data-sheets/ADV7181D.pdf
  -> 12EUR https://www.digikey.de/product-detail/de/analog-devices-inc/ADV7181DBCPZ/ADV7181DBCPZ-ND/4915078
  -> 13EUR https://www.aliexpress.com/item/ADV7181DWBCPZ-LFCSP-64-IC-VIDEO-DECODER-SD-HD-64LFCSP-ADV7181D/32857019510.html
  https://www.intersil.com/content/dam/intersil/documents/isl9/isl98001.pdf
  -> 12EUR https://www.digikey.de/product-detail/de/renesas-electronics-america-inc/ISL98001IQZ-140/ISL98001IQZ-140-ND/1915145
  -> 12EUR https://www.mouser.de/ProductDetail/Renesas-Intersil/ISL98001IQZ-140?qs=sGAEpiMZZMsLKVrzu2LM0AT5Qi2F4f4a
  http://www.analog.com/media/en/technical-documentation/data-sheets/ADV7181C.pdf
  -> 13EUR https://www.digikey.de/product-detail/de/analog-devices-inc/ADV7181CBSTZ/ADV7181CBSTZ-ND/1971692
  -> 13EUR https://www.mouser.de/ProductDetail/Analog-Devices/ADV7181CBSTZ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
  https://www.intersil.com/content/dam/Intersil/documents/isl9/isl98002.pdf
  -> 18EUR https://www.digikey.de/product-detail/de/renesas-electronics-america-inc/ISL98002CRZ-170/ISL98002CRZ-170-ND/1976767
  -> 18EUR https://www.mouser.de/ProductDetail/Renesas-Intersil/ISL98002CRZ-170?qs=sGAEpiMZZMsLKVrzu2LM0M8Fpq7UuMM6
  -> 18EUR https://www.avnet.com/shop/us/products/renesas-electronics/isl98002crz-170-3074457345624817358/
  http://www.analog.com/media/en/technical-documentation/data-sheets/ADV7604.pdf (VGA+HDMI)
  -> 19EUR https://www.digikey.de/products/de?keywords=ADV7604
  -> ????? https://www.mouser.de/ProductDetail/Analog-Devices/ADV7604BBCZ-5P?qs=sGAEpiMZZMv9Q1JI0Mo%2ftTRrUseWGTpx
  https://www.intersil.com/content/dam/Intersil/documents/tw88/tw8813b.pdf
  -> 26EUR https://www.mouser.de/ProductDetail/Renesas-Intersil/TW8813-LB2-GR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

- VGA decoder IC (with TTL output):
  https://www.intersil.com/content/dam/Intersil/documents/tw88/tw8826.pdf
  -> 6EUR https://www.digikey.de/product-detail/de/renesas-electronics-america-inc/TW8826-LA3-GR/TW8826-LA3-GR-ND/2391823
  https://www.intersil.com/content/dam/Intersil/documents/tw88/tw8830.pdf
  -> 7EUR https://www.digikey.de/products/de?keywords=TW8830
  https://www.intersil.com/content/dam/Intersil/documents/tw88/tw8832-32s.pdf
  -> 7EUR https://www.aliexpress.com/item/TW8832S-LB1-CR-80LQFP-TW8832S-LB1-CR-8832-TW8832S-TW8832-1PCS/1000006347742.html
  -> 8EUR https://www.digikey.de/product-detail/de/renesas-electronics-america-inc/TW8832-LB1-CR/TW8832-LB1-CR-ND/2773224
  -> 8EUR https://www.mouser.de/ProductDetail/Renesas-Intersil/TW8832-LB1-CR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
  http://www.intersil.com/content/dam/Intersil/documents/tw88/tw8834.pdf
  -> 9EUR https://www.digikey.de/product-detail/de/renesas-electronics-america-inc/TW8834-TA2-CR/TW8834-TA2-CR-ND/4895560
  -> 9EUR https://www.mouser.de/ProductDetail/Renesas-Intersil/TW8834-TA2-CR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
  https://www.marutsu.co.jp/contents/shop/marutsu/ds/tw8835.pdf
  -> 10EUR https://www.digikey.de/product-detail/de/renesas-electronics-america-inc/TW8835-LA2-CR/TW8835-LA2-CR-ND/3178336
  http://www.intersil.com/content/dam/Intersil/documents/tw88/tw8823c.pdf
  -> 21EUR https://www.digikey.de/product-detail/de/renesas-electronics-america-inc/TW8823-LC2-CE/TW8823-LC2-CE-ND/4439577
  http://www.analog.com/media/en/technical-documentation/data-sheets/ADV7403.pdf
  -> 37EUR https://www.digikey.de/product-detail/de/analog-devices-inc/ADV7403BSTZ-110/ADV7403BSTZ-110-ND/996492

- TDMS (DVI/HDMI) Deserializer:
  http://www.ti.com/lit/ds/symlink/tfp401a.pdf
  -> 8EUR https://www.digikey.de/product-detail/de/texas-instruments/TFP401APZP/296-9991-ND/380157
  http://www.ti.com/lit/ds/symlink/tfp401.pdf
  -> 8EUR https://www.mouser.de/ProductDetail/Texas-Instruments/TFP401PZP?qs=sGAEpiMZZMuo%252bmZx5g6tFDrLhqmO%252bWg2
  http://www.analog.com/media/en/technical-documentation/data-sheets/ADV7611.pdf
  -> 13EUR https://www.digikey.de/product-detail/de/analog-devices-inc/ADV7611BSWZ-P/ADV7611BSWZ-P-ND/2643232

- ADC:
  http://www.ti.com/lit/ds/symlink/adc08060.pdf

- SDRAM:
  http://www.winbond.com/resource-files/w9864g6kh_a03_20170326.pdf
  -> 2EUR https://www.digikey.com/product-detail/en/winbond-electronics/W9864G6KH-6/W9864G6KH-6-ND/4490112
  https://www.mouser.de/datasheet/2/198/42-45S16400J-258565.pdf
  -> 2EUR https://www.mouser.de/ProductDetail/ISSI/IS42S16400J-5TL?qs=sGAEpiMZZMti5BT4iPSEnZSv2uQuVb3PJGb1N565sig%3d
  https://www.alliancememory.com/wp-content/uploads/pdf/Alliance%20Memory_64M_AS6C6416-55TIN%20v1.0%20July%202017.pdf
  -> 24EUR https://www.digikey.de/product-detail/de/alliance-memory-inc/AS6C6416-55TIN/1450-1464-ND/7791412
  https://www.mouser.de/datasheet/2/12/Alliance%20Memory_64M_AS6C6416-55TIN%20v1.0%20July%202017-1223671.pdf
  -> 25EUR https://www.mouser.de/ProductDetail/Alliance-Memory/AS6C6416-55TIN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

- DRAM (with DQS):
  https://www.mouser.de/datasheet/2/12/Datasheet%20Alliance%20128Mb%20DDR1_AS4C8M16D1A-5T(CI)N--1288448.pdf
  -> 2EUR https://www.mouser.de/ProductDetail/Alliance-Memory/AS4C8M16D1A-5TCN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

- CPU:
  http://ww1.microchip.com/downloads/en/DeviceDoc/SAM-E70S70V70V71-Family%20DataSheet-DS60001527B.pdf (SRAM, SDRAM)
  -> 6EUR https://www.digikey.com/product-detail/en/microchip-technology/ATSAMS70J21A-AN/1611-ATSAMS70J21A-AN-ND/6829743
  -> 9EUR https://www.mouser.de/ProductDetail/Microchip-Technology/ATSAMS70Q19A-AN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
  -> 9EUR https://www.digikey.de/product-detail/de/microchip-technology/ATSAMS70Q19A-AN/ATSAMS70Q19A-AN-ND/5235927
  -> 10EUR https://www.mouser.de/ProductDetail/Microchip-Technology/ATSAMS70J21A-AN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
  https://www.st.com/content/ccc/resource/technical/document/datasheet/65/cb/75/50/53/d6/48/24/DM00141306.pdf/files/DM00141306.pdf/jcr:content/translations/en.DM001413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 (SRAM, SDRAM)
  -> 6EUR https://www.digikey.de/product-detail/de/stmicroelectronics/STM32F446RCT6/497-17472-ND/7650386
  http://www.nxp.com/documents/data_sheet/LPC1850_30_20_10.pdf (SRAM, SDRAM)
  -> 8EUR https://www.digikey.de/product-detail/de/nxp-usa-inc/LPC1820FBD144551/568-13151-ND/3430905
  https://www.nxp.com/docs/en/data-sheet/LPC4350_30_20_10.pdf (SRAM, SDRAM)
  -> 8EUR https://www.digikey.de/product-detail/de/nxp-usa-inc/LPC4330FBD144551/568-9450-ND/2840463
  https://www.nxp.com/docs/en/data-sheet/LPC540xx.pdf (SRAM, SDRAM)
  -> 8EUR https://www.digikey.de/product-detail/de/nxp-usa-inc/LPC54005JBD100E/568-13833-ND/8134961
  https://www.microchip.com/wwwproducts/en/ATSAM3X8E (SRAM)
  -> 10EUR https://www.digikey.com/product-detail/en/microchip-technology/ATSAM3X8EA-AU/ATSAM3X8EA-AU-ND/3128687
  http://www.nxp.com/documents/data_sheet/LPC178X_7X.pdf (SDRAM)
  -> 11EUR https://www.digikey.de/product-detail/de/nxp-usa-inc/LPC1788FBD144551/568-7576-ND/2677570
  https://www.nxp.com/docs/en/data-sheet/LPC1769_68_67_66_65_64_63.pdf (No Real External Memory Interface)
  -> 12EUR https://www.digikey.com/product-detail/en/nxp-usa-inc/LPC1768FBD100551/568-4796-ND/2089968

- FPGA:
  http://www.latticesemi.com/~/media/LatticeSemi/Documents/DataSheets/MachXO23/MachXOFamilyDataSheet.pdf
  -> 6EUR https://www.digikey.de/product-detail/de/lattice-semiconductor-corporation/LCMXO1200C-3TN144C/220-1178-ND/2731479
  -> 6EUR https://www.mouser.de/ProductDetail/Lattice/LCMXO1200C-3TN144C?qs=sGAEpiMZZMu6TJb8E8Cjr%2fcQ3fuZ6KqL
  https://www.xilinx.com/support/documentation/data_sheets/ds529.pdf
  -> 10EUR https://www.digikey.de/product-detail/de/xilinx-inc/XC3S50A-4TQG144C/122-1541-ND/1756100
  https://www.xilinx.com/support/documentation/data_sheets/ds162.pdf
  -> 10EUR https://www.digikey.de/product-detail/de/xilinx-inc/XC6SLX4-2TQG144C/122-1734-ND/2339857
  https://www.mouser.de/datasheet/2/225/MachXO2FamilyDataSheet-948089.pdf
  -> 10EUR https://www.mouser.de/ProductDetail/Lattice/LCMXO2-4000HC-4TG144C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
  -> 10EUR https://www.digikey.de/product-detail/de/lattice-semiconductor-corporation/LCMXO2-4000HC-4TG144C/220-1460-ND/2785571
  https://www.intel.com/content/dam/www/programmable/us/en/pdfs/literature/hb/cyc2/cyc2_cii5v1.pdf
  -> 14EUR https://www.mouser.de/ProductDetail/Intel-Altera/EP2C5Q208C8N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
  -> 14EUR https://www.digikey.de/product-detail/de/intel/EP2C5Q208C8N/544-1673-ND/1084587
  https://www.mouser.de/datasheet/2/225/LatticeXP2FamilyDataSheet-310950.pdf
  -> 14EUR https://www.mouser.de/ProductDetail/Lattice/LFXP2-5E-5QN208C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

- FPGA with Ballgrid Array:
  http://www.latticesemi.com/view_document?document_id=50461
  https://www.latticestore.com/products/tabid/417/categoryid/9/productid/122770/searchid/1/searchvalue/lfe5u-12f-6bg256c/default.aspx
  -> 5EUR https://www.digikey.de/product-detail/de/lattice-semiconductor-corporation/LFE5U-12F-6BG256C/220-2202-ND/9553915
  -> 5EUR https://www.mouser.de/ProductDetail/Lattice/LFE5U-12F-6BG256C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
  https://www.latticesemi.com/view_document?document_id=50121
  -> 11EUR https://www.digikey.de/product-detail/de/lattice-semiconductor-corporation/LCMXO3L-9400E-5BG256C/220-2163-ND/8687502

- FGPA with SERDES (serializer/deserializer)
  https://www.xilinx.com/support/documentation/data_sheets/ds162.pdf
  -> 10EUR https://www.digikey.de/product-detail/de/xilinx-inc/XC6SLX4-2TQG144C/122-1734-ND/2339857
  https://www.xilinx.com/support/documentation/data_sheets/ds162.pdf
  -> 15EUR https://www.digikey.de/product-detail/de/xilinx-inc/XC6SLX9-2TQG144C/122-1745-ND/2339919
  https://www.xilinx.com/support/documentation/data_sheets/ds162.pdf
  -> 17EUR https://www.digikey.de/product-detail/de/xilinx-inc/XC6SLX9-2FTG256C/122-1951-ND/2339917

- CPLD:
  https://www.intel.com/content/dam/www/programmable/us/en/pdfs/literature/hb/max-v/mv51003.pdf
  -> 5EUR https://www.digikey.com/product-detail/en/intel/5M240ZT100C5N/544-2716-ND/2499439
  -> 5EUR https://www.mouser.de/ProductDetail/Intel-Altera/5M240ZT100C5N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
  https://www.mouser.de/datasheet/2/612/max5_handbook-1098935.pdf
  -> 7EUR https://www.mouser.de/ProductDetail/Intel-Altera/5M570ZT100C5N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
  -> 7EUR https://www.digikey.de/products/de?keywords=5M570ZT100C5N
  https://www.intel.com/content/dam/www/programmable/us/en/pdfs/literature/hb/max2/max2_mii51006.pdf
  -> 8EUR https://www.digikey.com/product-detail/en/intel/EPM240T100C5N/544-1964-ND/705409
  https://www.xilinx.com/support/documentation/data_sheets/ds093.pdf
  -> 9EUR https://www.digikey.com/product-detail/en/xilinx-inc/XC2C128-7VQG100C/122-1285-ND/826888
  https://www.intel.com/content/dam/www/programmable/us/en/pdfs/literature/hb/max-v/mv51003.pdf
  -> 9EUR https://www.digikey.de/product-detail/de/intel/5M570ZT144C5N/544-2720-ND/2499443
  -> 9EUR https://www.mouser.de/ProductDetail/Intel-Altera/5M570ZT144C5N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
  https://www.intel.com/content/dam/www/programmable/us/en/pdfs/literature/hb/max-v/mv51003.pdf
  -> 10EUR https://www.digikey.de/product-detail/de/intel/5M1270ZT144C5N/544-2840-ND/2660788
  -> 10EUR https://www.mouser.de/ProductDetail/Intel-Altera/5M1270ZT144C5N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

- VGA HD15 Connector:
  https://www.mouser.de/datasheet/2/18/c-cd-0012-1365176.pdf
  -> 1EUR https://www.mouser.de/ProductDetail/Amphenol-FCI/ICD15S13E4GX00LF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
  -> 1EUR https://www.digikey.de/product-detail/de/amphenol-fci/ICD15S13E4GX00LF/609-5181-ND/1536501

- DVI-DA Connector:
  https://www.molex.com/pdm_docs/sd/743209004_sd.pdf
  -> 4EUR https://www.mouser.de/ProductDetail/Molex/74320-9004?qs=%2fha2pyFaduh4Ft0auSXQS%2fhhbJy%252b3m6SxATfBZv07PQ%3d
  -> 4EUR https://www.digikey.de/product-detail/de/molex-connector-corporation/74320-9004/WM6095-ND/1989238

- VGA-DVI-A Adapter:
  https://assets.tripplite.com/product-pdfs/en/p120000.pdf
  -> ???? https://www.mouser.de/ProductDetail/Tripp-Lite/P120-000?qs=sGAEpiMZZMtAYTMy7wxArxjV6M6xKDmRNn7UoKy237I%3d
  -> 6EUR https://www.digikey.de/product-detail/de/tripp-lite/P120-000/TL1135-ND/1533410
  https://www.intos.de/ArboroPDFCreatorSW4?id=17
  -> 3EUR https://www.amazon.de/InLine-Analog-Adapter-Monitoradapter-Stecker/dp/B000VFG6UC

- HDMI-DVI-D Adapter:
  -> 2EUR https://www.amazon.de/Stecker-Buchse-Konverter-Adapter-Unterstützung/dp/B01KH1UGMS
  -> 3EUR https://www.amazon.de/HDMI-Adapter-vergoldeten-Anschlüßen-Female/dp/B000NHNV1U

- HDMI Connector:
  https://www.mouser.de/datasheet/2/206/B-0233-2E_DC3-784461.pdf
  -> 2EUR https://www.mouser.de/ProductDetail/JAE-Electronics/DC3RX19JA3R1700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
  -> 2EUR https://www.digikey.de/product-detail/de/jae-electronics/DC3RX19JA3R1700/670-2861-1-ND/5823256

- USB Bridge:
  http://www.ftdichip.com/Support/Documents/DataSheets/ICs/DS_FT2232H.pdf
  -> 6EUR https://www.digikey.de/product-detail/de/ftdi-future-technology-devices-international-ltd/FT2232HL-REEL/768-1024-1-ND/1986057
  -> 6EUR https://www.mouser.de/ProductDetail/FTDI/FT2232HL-REEL?qs=sGAEpiMZZMs5ceO8zL%252bTx6ksD1BB0CN5

- USB HID Bridge:
  https://www.mouser.de/datasheet/2/163/DS_FT260-888033.pdf
  -> 2EUR https://www.mouser.de/ProductDetail/FTDI/FT260S-U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
  -> 2EUR https://www.digikey.de/product-detail/de/ftdi-future-technology-devices-international-ltd/FT260S-U/768-1282-5-ND/6124909

- USB-C Controller:
  https://www.mouser.de/datasheet/2/308/FUSB303-D-1315695.pdf
  -> 1EUR https://www.mouser.de/ProductDetail/ON-Semiconductor/FUSB303TMX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

- USB-Switch:
  https://www.mouser.de/datasheet/2/408/TC7USB42MU_datasheet_en_20130205-1082938.pdf
  -> 1EUR https://www.mouser.de/ProductDetail/Toshiba/TC7USB42MULF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

- 2x USB-C Connector:
  http://www.jae.com/z-en/pdf_download_exec.cfm?param=MB-0301-3E_DX07_PLUG.pdf
  -> 2EUR https://www.digikey.de/product-detail/de/amphenol-commercial-products/12401598E4-2A/12401598E4-2ACT-ND/6051824
  -> 2EUR https://www.mouser.de/ProductDetail/Amphenol-Commercial-Products/12401598E42A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

- 2x USB-C Cable:
  https://www.mouser.de/datasheet/2/276/0687980009_CABLE_ASSEMBLIES-1315748.pdf
  -> 6EUR https://www.mouser.de/ProductDetail/Molex/68798-0009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

- 2x JTAG Socket:
  https://drawings-pdf.s3.amazonaws.com/10492.pdf
  -> 1EUR https://www.digikey.de/product-detail/de/sullins-connector-solutions/PPPC062LFBN-RC/S7109-ND/810246
  https://www.mouser.de/datasheet/2/1/ts0815-31700.pdf
  -> 1EUR https://www.mouser.de/ProductDetail/3M-Electronic-Solutions-Division/929975-01-06-RK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

- 2x JTAG ARM 10-Pin:
  http://suddendocs.samtec.com/prints/ftsh-1xx-xx-xxx-dv-xxx-xxx-mkt.pdf
  -> 3EUR https://www.mouser.de/ProductDetail/Samtec/FTSH-105-01-L-DV-007-K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
  -> 3EUR https://www.digikey.de/product-detail/de/samtec-inc/FTSH-105-01-L-DV-007-K/SAM9438-ND/6678175

- 12MHz 30PPM <150pS Jitter Crystal (needed for USB Bridge):
  https://www.mouser.de/datasheet/2/3/abls-44621.pdf
  -> 1EUR https://www.mouser.de/ProductDetail/ABRACON/ABLS-12000MHZ-B4-T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
  -> 1EUR https://www.digikey.de/product-detail/de/abracon-llc/ABLS-12.000MHZ-B4-T/535-10218-1-ND/2184253

- 14.31818MHz Crystal (needed for VGA Decoder TVP5146)
  https://www.mouser.de/datasheet/2/741/LFXTAL026507Bulk-995055.pdf
  -> 1EUR https://www.mouser.de/ProductDetail/IQD/LFXTAL026507Bulk?qs=sGAEpiMZZMsMyYRRhGMFNnDI%2fhPdOp0nGmLAAMgbONQ%3d

- 20MHz Crystal:
  https://www.mouser.de/datasheet/2/741/LFXTAL020131Bulk-993049.pdf
  -> 1EUR https://www.mouser.de/ProductDetail/IQD/LFXTAL020131Bulk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

- 24MHz Oscillator:
  https://www.jauch.com/downloadfile/57ff59acdb721_99e1810aedd15407c828/jo22h-1v8-111115.pdf
  -> 2EUR https://www.digikey.de/product-detail/de/jauch-quartz/O-240-JO22H-E-18-1-T1-LF/1908-1005-1-ND/8108117
  https://www.mouser.de/datasheet/2/122/ECS-2520MV-1314080.pdf
  -> 1EUR https://www.mouser.de/ProductDetail/ECS/ECS-2520MV-240-BN-TR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
  https://www.mouser.de/datasheet/2/741/LFXTAL012504Bulk-940380.pdf
  -> 1EUR https://www.mouser.de/ProductDetail/IQD/LFXTAL012504Cutt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
  http://www.foxonline.com/pdfs/C4SD.pdf
  -> 1EUR https://www.digikey.de/product-detail/de/fox-electronics/FC4SDCBMF24.0-T1/631-1020-1-ND/1024725
  
-> 24MHz to 200MHz Multiplier:
  https://www.mouser.de/datasheet/2/268/PL611-01-1101889.pdf
  -> 1EUR https://www.mouser.de/ProductDetail/Microchip-Technology/PL611-01-F93TC-R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

Side notes:
- VGA spec:
  https://www.digikey.com/eewiki/pages/viewpage.action?pageId=15925278
  http://www.javiervalcarce.eu/html/vga-signal-format-timming-specs-en.html
  http://www.eng.ucy.ac.cy/theocharides/Courses/ECE664/VGA.pdf
  http://multimedia.3m.com/mws/media/297467O/3mtm-flat-panel-display-interface-technologies.pdf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
- DVI/HDMI (TMDS):
  https://www.latticesemi.com/en/Products/DesignSoftwareAndIP/IntellectualProperty/ReferenceDesigns/ReferenceDesign04/71LVDSVideoInterfaceXO2XO3ECP5
  https://www.latticesemi.com/en/Products/DesignSoftwareAndIP/IntellectualProperty/ReferenceDesigns/ReferenceDesigns02/HDMIDVIVideoInterface
  https://www.xilinx.com/support/documentation/application_notes/xapp495_S6TMDS_Video_Interface.pdf
  http://www.analog.com/en/products/audio-video/hdmidvi-receivers.html
  https://electronics.stackexchange.com/questions/130942/transmitting-hdmi-dvi-over-an-fpga-with-no-support-for-tmds
  https://www.fpga4fun.com/HDMI.html
  http://hamsterworks.co.nz/mediawiki/index.php/HDMI_Input
  http://www.latticesemi.com/-/media/LatticeSemi/Documents/UserManuals/JL/Lattice71VDSVideoDemoKitUsersGuide.ashx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
  https://kompendium.infotip.de/lvds_tmds.html
  https://www.xilinx.com/support/documentation/application_notes/xapp495_S6TMDS_Video_Interface.pdf
- HDMI License: https://www.hdmi.org/manufacturer/terms.aspx
- similar project: http://www.rpg.fi/desaster/blog/2013/04/19/vga-framegrabbing-with-tvp7002/
- HID implementation keyboard/mouse: https://www.sparkfun.com/tutorials/337
- multi HID implementation: https://github.com/NicoHood/HID
- FPGA to HS USB: https://www.eetimes.com/document.asp?doc_id=1279155
- FPGA to USB example: https://rohitksingh.in/ftdi-asynchronous-fifo-usb-communication-with-fpga.html
- FPGA Clock Mux: http://www.fpgadeveloper.com/2011/09/code-templates-clock-mux.html
- Difference between FPGA and CPLD: https://www.quora.com/What-is-the-difference-between-CPLD-and-FPGA
- LCD UV exposure to PCB:
  http://www.robotmaker.eu/ROBOTmaker/rapid-pcb-prototyping/prototyping-pcb-using-lcd
  https://www.heise.de/newsticker/meldung/Displayweek-3D-Drucker-mit-LCD-als-Belichtungsmaske-2678960.html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
  https://electronics.stackexchange.com/questions/247239/blasting-copper-off-a-substrate-with-a-808nm-laser-diode-viability
  https://electronics.stackexchange.com/questions/100857/laser-diode-to-remove-copper-layer-from-pcb
  https://www.youtube.com/watch?v=uIIwU29H3E8
  https://www.reichelt.de/fotoplatine-einseitig-160x100mm-1-5mm-35-bel-160x100-1-p33767.html
  https://www.conrad.de/de/basismaterial-fotobeschichtung-positiv-einseitig-35-m-l-x-b-160-mm-x-100-mm-130306e33-bungard-1-st-523580.html
- Printed Circuit: https://www.instructables.com/id/Print-Conductive-Circuits-With-An-Inkjet-Printer/ (Brother DCP-J140w)
  http://diamond-jet.com/silvernanoinkjetsystem.aspx
  https://www.blackmagic3d.com/Conductive-p/grphn-pla.htm

Memory Requirements (double buffering):
-  640x480x16 -> 10MBit
-  640x480x24 -> 15MBit
-  800x600x16 -> 16MBit
-  800x600x24 -> 24MBit
- 1024x768x16 -> 26MBit
- 1024x768x24 -> 38MBit

Pins:
  TMDS:
  -> 8 differential output for digital colors
  TVP7002:
  -> 27 output for digital colors
  -> 4 output for timings
  -> 10 input for analog colors
  -> 7 inputs for timings
  -> 3 for I2C interface
  FT2232H:
  -> 16 input/output for data
  -> 10 input/output for command
  FT260S:
  -> 2 input for HID selection
  -> 7 input/output for data
  DRAM:
  -> 28 input/output address/data/clock
  Total:
  -> 122 !!

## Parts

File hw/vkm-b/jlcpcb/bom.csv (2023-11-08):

Comment | Designator | Footprint | LCSC
10u | C7,C11 | Capacitor_Tantalum_SMD:CP_EIA-3216-10_Kemet-I | C7171
100n | C8,C9,C10,C4,C1,C2,C3,C6,C5 | Capacitor_SMD:C_0603_1608Metric | C14663
APM4953KC-TRG | Q1 | Package_SO:SOP-8_3.9x4.9mm_P1.27mm | C20897
5.1k | R1,R2 | Resistor_SMD:R_0603_1608Metric | C23186
10k | R3,R7,R4,R8 | Resistor_SMD:R_0603_1608Metric | C25804
2.2k | R6,R5 | Resistor_SMD:R_0603_1608Metric | C4190
STM32F042F6Px | U1,U2 | Package_SO:TSSOP-20_4.4x6.5mm_P0.65mm | C81000
AMS1117-3.3 | U3 | Package_TO_SOT_SMD:SOT-223-3_TabPin2 | C6186

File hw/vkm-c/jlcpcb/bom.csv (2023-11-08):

Comment | Designator | Footprint | LCSC
10u | C7,C11 | Capacitor_SMD:C_0603_1608Metric | C19702
100n | C8,C9,C10,C2,C3,C6,C5 | Capacitor_SMD:C_0603_1608Metric | C14663
B5819WSL | D1,D2 | Diode_SMD:D_SOD-123 | C8598
GREEN | D3 | LED_SMD:LED_0603_1608Metric | C72043
USB_C_Receptacle_USB2.0 | J1 | Connector_USB:USB_C_HRO_TYPE_C_31_M_12 | C165948
Conn_01x09 | J2 | Connector_PinHeader_2.54mm:PinHeader_1x09_P2.54mm_Vertical
Conn_01x03 | J3 | vkm-c:PinHeader_1x03_P2.54mm_Horizontal_Edge
USB_A | J4 | Connector_USB:USB_A_TH_AM90 | C9739
5.1k | R1,R2 | Resistor_SMD:R_0603_1608Metric | C23186
33k | R10,R9 | Resistor_SMD:R_0603_1608Metric | C4216
820R | R11 | Resistor_SMD:R_0603_1608Metric | C23253
10k | R3,R7,R4,R8 | Resistor_SMD:R_0603_1608Metric | C25804
2.2k | R6,R5 | Resistor_SMD:R_0603_1608Metric | C4190
USB1 | TP3 | TestPoint:TestPoint_Pad_D1.0mm
USB2 | TP4 | TestPoint:TestPoint_Pad_D1.0mm
5V | TP5 | TestPoint:TestPoint_Pad_D1.0mm
3V3 | TP6 | TestPoint:TestPoint_Pad_D1.0mm
GND | TP7 | TestPoint:TestPoint_Pad_D1.0mm
STM32F042F6Px | U1,U2 | Package_SO:TSSOP-20_4.4x6.5mm_P0.65mm | C81000
XC6206P332MR | U3 | Package_TO_SOT_SMD:SOT-23 | C5446

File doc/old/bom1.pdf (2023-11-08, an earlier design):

Bill of materials for variant 1

Pos Qty Type | Manufacturer Number | Description | Price 1 | Total 1 | Source 1
10 | 1 PCB | 5x 100x100mm PCB | 10.00 € | 10.00 € https://www.smart-prototyping.com/PCB-Prototyping.html
20 | 1 FPGA | LCMXO2-4000HC-4TG144C | 9.82 € | 9.82 € https://www.mouser.de/ProductDetail/Lattice/LCMXO2-4000HC-4TG144C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
30 | 1 VGA Decoder | TVP7002PZPR | 6.65 € | 6.65 € https://www.mouser.de/ProductDetail/Texas-Instruments/TVP7002PZPR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
40 | 1 VGA Connector | ICD15S13E4GX00LF | connection to slave | 1.06 € | 1.06 € https://www.mouser.de/ProductDetail/Amphenol-FCI/ICD15S13E4GX00LF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
50 | 1 DVI-DA Connector | 74320-9004 | connection to FPGA as optional input | 3.25 € | 3.25 € https://www.mouser.de/ProductDetail/Amphenol-FCI/ICD15S13E4GX00LF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
60 | 1 128MBit DRAM (DQS) AS4C8M16D1A-5TCN | image FIFO | 1.98 € | 1.98 € https://www.mouser.de/ProductDetail/Alliance-Memory/AS4C8M16D1A-5TCN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
70 | 1 USB Bridge | FT2232HL-REEL | connection to master | 5.70 € | 5.70 € https://www.mouser.de/ProductDetail/FTDI/FT2232HL-REEL?qs=sGAEpiMZZMs5ceO8zL%252bTx6ksD1BB0CN5
80 | 1 USB HID | FT260S-U | connection to slave | 1.56 € | 1.56 € https://www.mouser.de/ProductDetail/FTDI/FT260S-U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
90 | 2 USB-C Connector | 10137062-00021LF | to connect master and slave | 1.69 € | 3.38 € https://www.mouser.de/ProductDetail/Amphenol-FCI/10137062-00021LF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
100 | 2 USB-C Cable | 68798-0009 | to connect master and slave | 5.79 € | 11.58 € https://www.mouser.de/ProductDetail/Molex/68798-0009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
110 | 1 12MHz 30PPM Crystal LFXTAL020131Bulk | clock source for USB Bridge | 0.21 € | 0.21 € https://www.mouser.de/ProductDetail/ABRACON/ABLS-12000MHZ-B4-T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
120 | 1
130 | 1
140 | 1
150 | 1
Total: | 55.19 €

Last Update: 2018-09-03

maps VGA/DVI to USB via DRAM buffer and passes keyboard/mouse input from master to USB HID used to decode analog VGA
signals from slave to digital outputs https://www.mouser.de/ProductDetail/Lattice/LCMXO2-4000HC-4TG144C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

https://www.mouser.de/ProductDetail/Texas-Instruments/TVP7002PZPR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

https://www.mouser.de/ProductDetail/Amphenol-FCI/ICD15S13E4GX00LF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

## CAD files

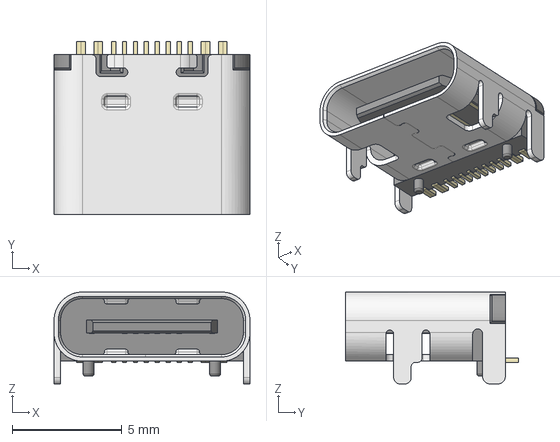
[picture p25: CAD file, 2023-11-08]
etc/HRO_TYPE-C-31-M-12.step
8.95 x 7.90 x 4.20 mm

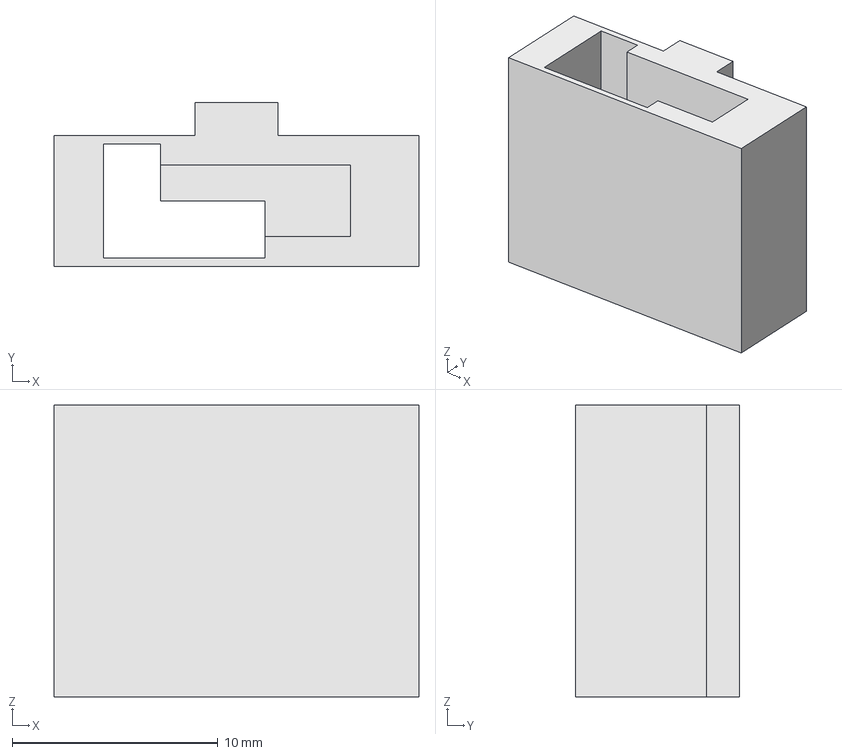
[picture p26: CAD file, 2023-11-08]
hw/vkm-c/stlink-conn.FCStd
17.8 x 7.96 x 14.2 mm

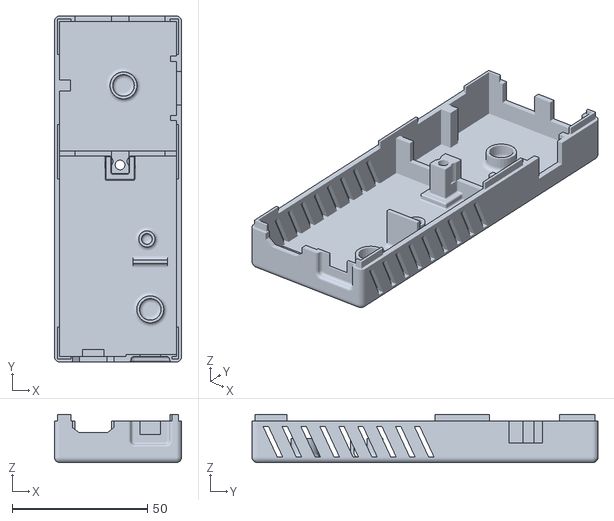
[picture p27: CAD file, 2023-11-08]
res/CaseA.stl
47.1 x 128.0 x 17.8

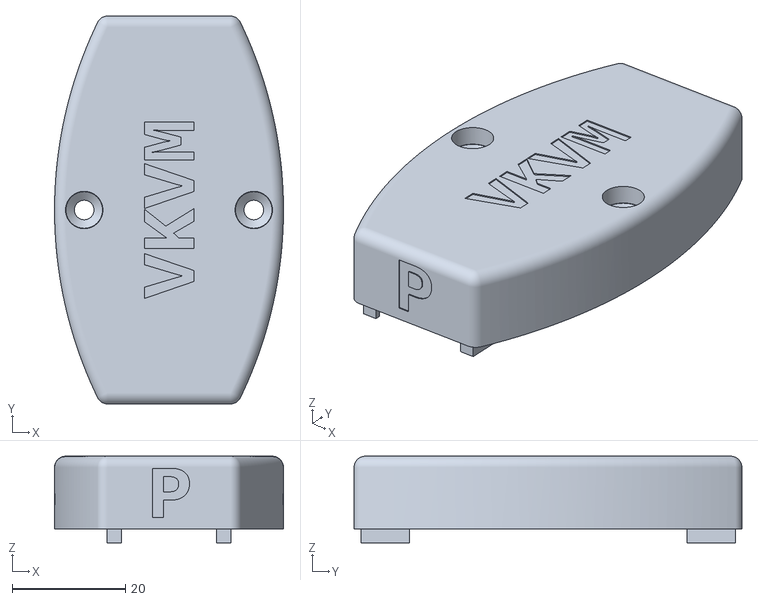
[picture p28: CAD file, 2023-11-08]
res/SmallCaseB.stl
40.4 x 68.5 x 15.3

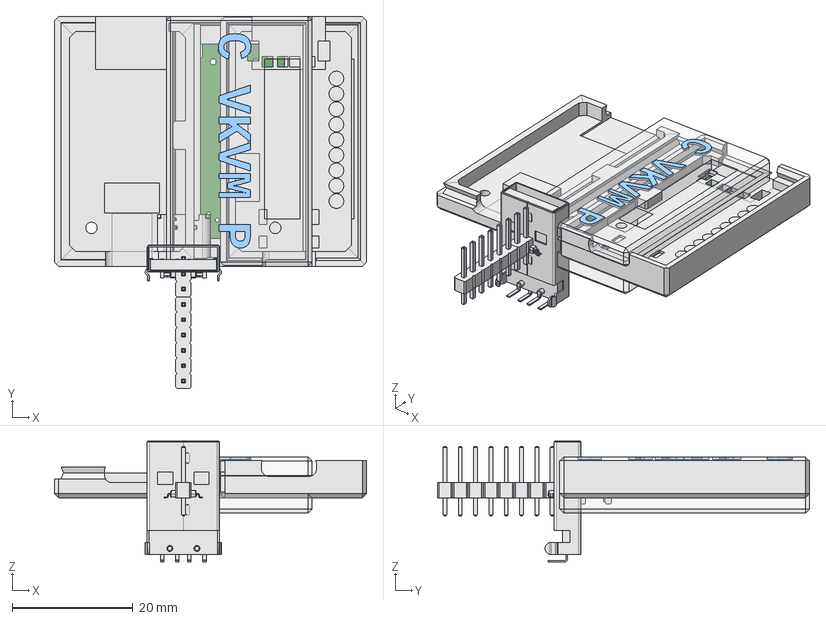
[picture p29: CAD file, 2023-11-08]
hw/vkm-c/case.FCStd
51.7 x 61.8 x 20.0 mm
Case
Gap
Labels
PO_DebugPinsBottom
PO_DebugPinsTop
PO_BaseBottom
PO_BaseTop
PO_AllPinsBottom
PO_AllPinsTop

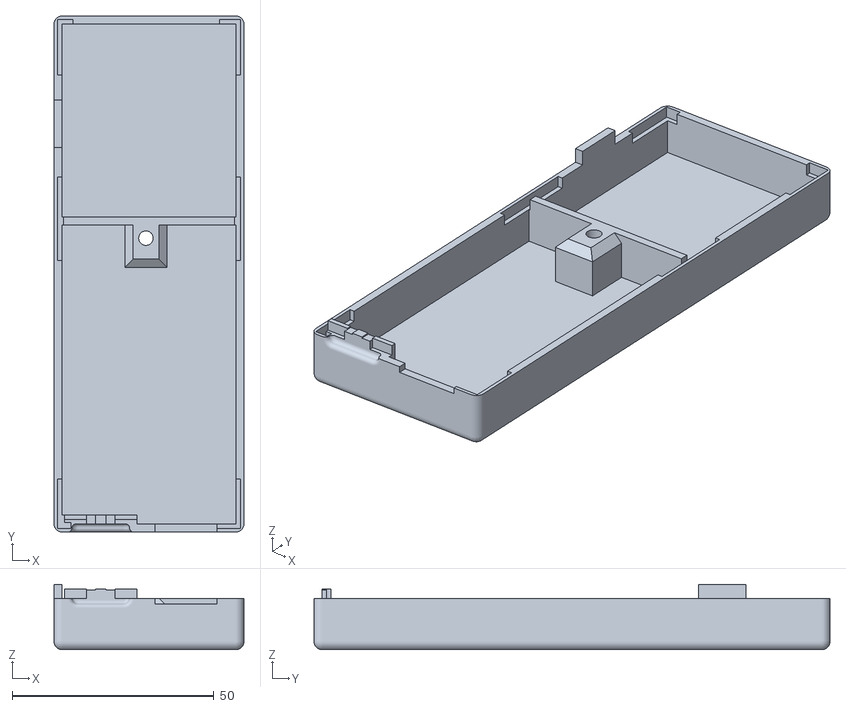
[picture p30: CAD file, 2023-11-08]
res/CaseB.stl
47.1 x 128.0 x 16.2

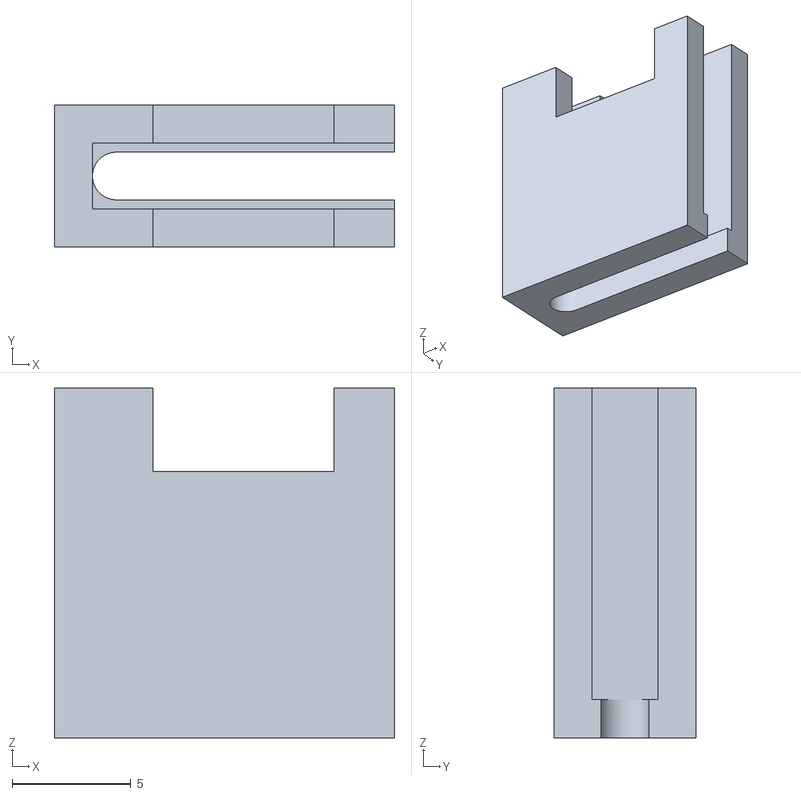
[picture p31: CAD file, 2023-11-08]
hw/vkm-c/stlink-conn-A.stl
14.3 x 5.98 x 14.7

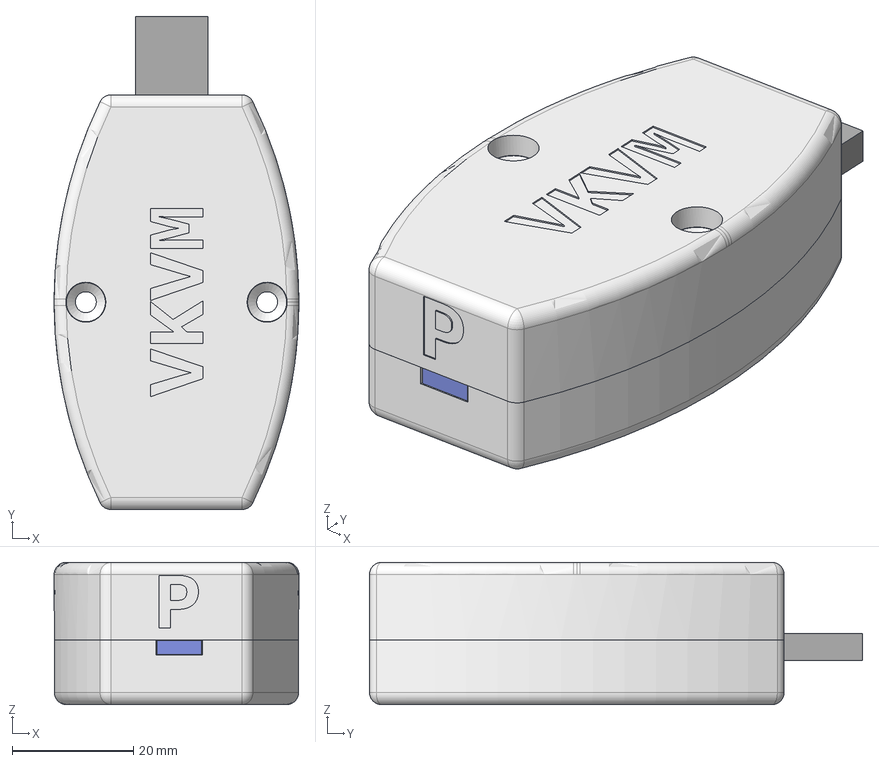
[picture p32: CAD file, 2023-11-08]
res/Case.FCStd
40.4 x 81.5 x 23.5 mm
UsbSer
UsbHid
Ser
SmallCaseA
SmallCaseB

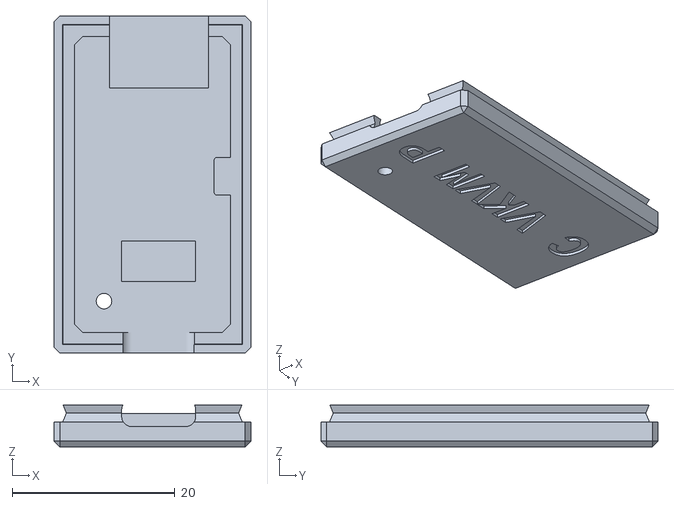
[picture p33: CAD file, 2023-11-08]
hw/vkm-c/case-top.stl
24.2 x 41.5 x 5.14

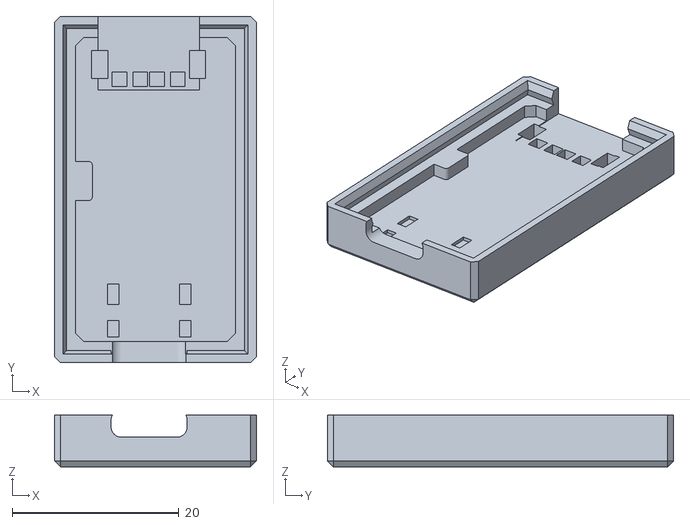
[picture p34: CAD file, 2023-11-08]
hw/vkm-c/case-bottom.stl
24.2 x 41.5 x 6.19

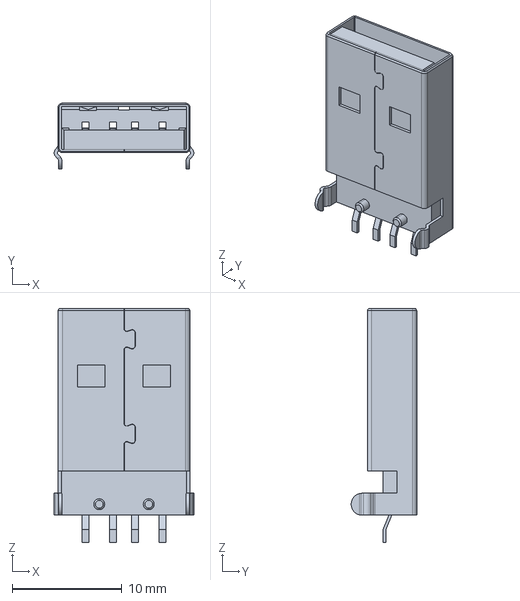
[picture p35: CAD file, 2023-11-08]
etc/480371000.stp
12.7 x 5.97 x 21.3 mm

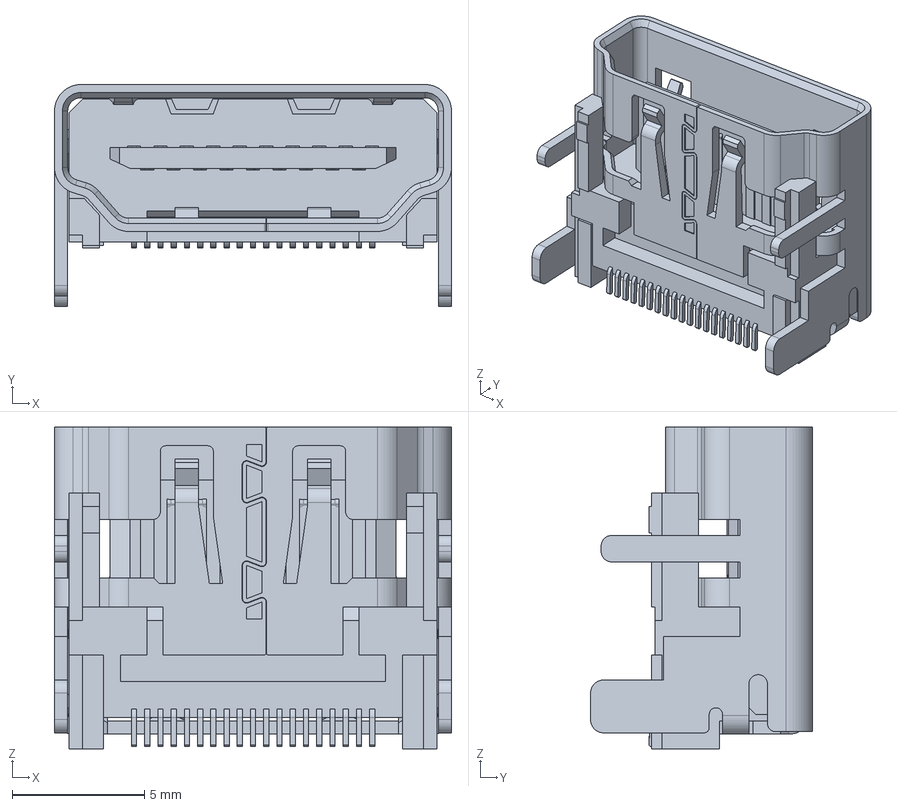
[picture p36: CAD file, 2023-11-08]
etc/2086581001.stp
15.0 x 8.38 x 12.2 mm

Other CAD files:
hw/vkm-c/stlink-conn-B.stl
etc/HRO_TYPE-C-31-M-12.FCStd

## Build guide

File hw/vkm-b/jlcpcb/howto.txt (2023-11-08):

Gerber: https://support.jlcpcb.com/article/44-how-to-export-kicad-pcb-to-gerber-files
BOM+Placement: https://support.jlcpcb.com/article/84-how-to-generate-the-bom-and-centroid-file-from-kicad
Order: https://jlcpcb.com/

Important: Be sure to place the auxilary point in pcbnew (KiCad) at the bottom left corner of the board (including any gerber output dimensions, not only board edge) before generation all files for JLCPCB to ensure positive coordinates

Fix wrong rotation in position output for:
CP_EIA-3216-10_Kemet-I -> +180deg
AMS1117-3.3 -> +180deg
DVIULC6-4SC6 -> +180deg
LM339PWR -> +90deg

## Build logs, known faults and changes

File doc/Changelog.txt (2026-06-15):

version numbering schema:
M.N.P
| | +-- patch: increased if only bug fixed were incorporated
| +---- minor: increased if syntax/semantic breaking changes were applied
+------ major: increased if elementary changes (from user's point of view) were made

1.3.0 (2026-06-14)
 - added: added periphery USB HID boot protocol mode indicator
 - changed: improved SVG rendering performance by caching blended images
 - changed: use double based absolute mouse positioning at Vkvm API
 - changed: use proper anti-aliased radio buttons in send keys popup menu
 - changed: use libv4lconvert to do the capture image conversion manually on Linux
 - fixed: incorrect internal result value for key releases within the firmware
 - fixed: USB HID conformance issues
 - fixed: HID compatibility issues with some non-standard conform hosts
 - fixed: proper mouse movement if VKVM runs within a remote session (e.g. RDP)
 - fixed: out of bounds issue for video frames from broken video capture devices
 - fixed: missing input value validation within internal image functions
 - fixed: possible deadlocks in serial connection termination
 - fixed: possible memory leak when pasting text to the remote host
 - fixed: possible use after free in video capture device destruction
 - fixed: wrong OS API handling in UTF-8 conversion functions
 - fixed: memory leak in video capture device monitoring on Linux
 - fixed: possible NULL dereferencing in IMediaFilter::GetSyncSource implementation
 - fixed: wrong allocation error handling in IPin::QueryId implementation
 - fixed: potential crash if video capture device is unplugged or reconfigured during capture
 - fixed: possible crash on ARM based hosts when saving/exporting a processed image
 - fixed: hardened serial connection timeout handling against rare race conditions
 - fixed: unreliable video capture device add/remove detection (and a possible crash) on Linux
 - fixed: serial read/write timeout could corrupt data or crash on Windows
 - fixed: potential stack overflow when reading serial status lines from a failing device on Windows
 - fixed: out of bounds ctype handling for non-ASCII names/text in natural-order compare
 - fixed: duplicate GUI process spawn on sudo helper error path on Linux
 - fixed: sudo password not cleared from memory before exec on Linux
 - fixed: top-bottom inverse video capture output
 - fixed: missing redraw of the connection status indicator on Linux

1.2.3 (2024-11-04)
 - added: description for HDMI Capture Variant 7
 - changed: internal sorting algorithm to a stable sorting variant
 - fixed: special characters handling in video and serial drop-down list
 - fixed: duplicate name case for video devices handling by adding the device path
 - fixed: missing linker plugin flag for LTO build

1.2.2 (2024-02-23)
 - fixed: missing explicit cleanup of password string for sudo on Linux

1.2.1 (2024-02-18)
 - fixed: broken mouse capture handling for none default DPI systems on Windows
 - fixed: broken meta key reset after input capturing on Windows

1.2.0 (2024-02-15)
 - added: root privileges enforcement on Linux
 - changed: resize window according to capture output resolution on capture start
 - fixed: misleading status output on capture device close

1.1.0 (2023-12-08)
 - added: description for HDMI Capture Variant 6
 - changed: add video device index number in capture device list on Linux
 - changed: object life-time management in DirectShow capture source
 - fixed: missing capture devices if multiple share the same name
 - fixed: ignore non-capture capable video devices on Linux
 - fixed: missing file in build dependency tracking for Linux
 - fixed: output format selection issue in DirectShow capture source
 - fixed: laggy DirectShow based rendering by dropping frames at capture source

1.0.0 (2023-11-08)
 - first release

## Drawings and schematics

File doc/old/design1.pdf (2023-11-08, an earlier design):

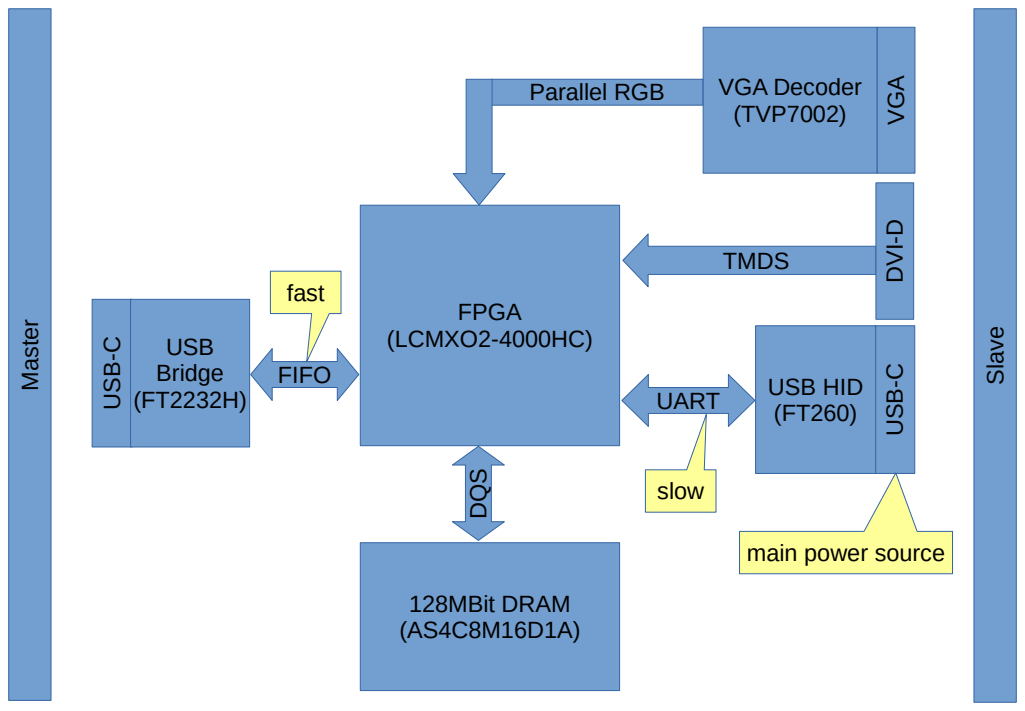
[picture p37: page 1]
VGA Decoder (TVP7002); USB Bridge (FT2232H); USB HID (FT260); FPGA (LCMXO2-4000HC); FIFO; Parallel RGB; UART; slow; fast; Sla; 128MBit DRAM (AS4C8M16D1A); TMDS

main power source

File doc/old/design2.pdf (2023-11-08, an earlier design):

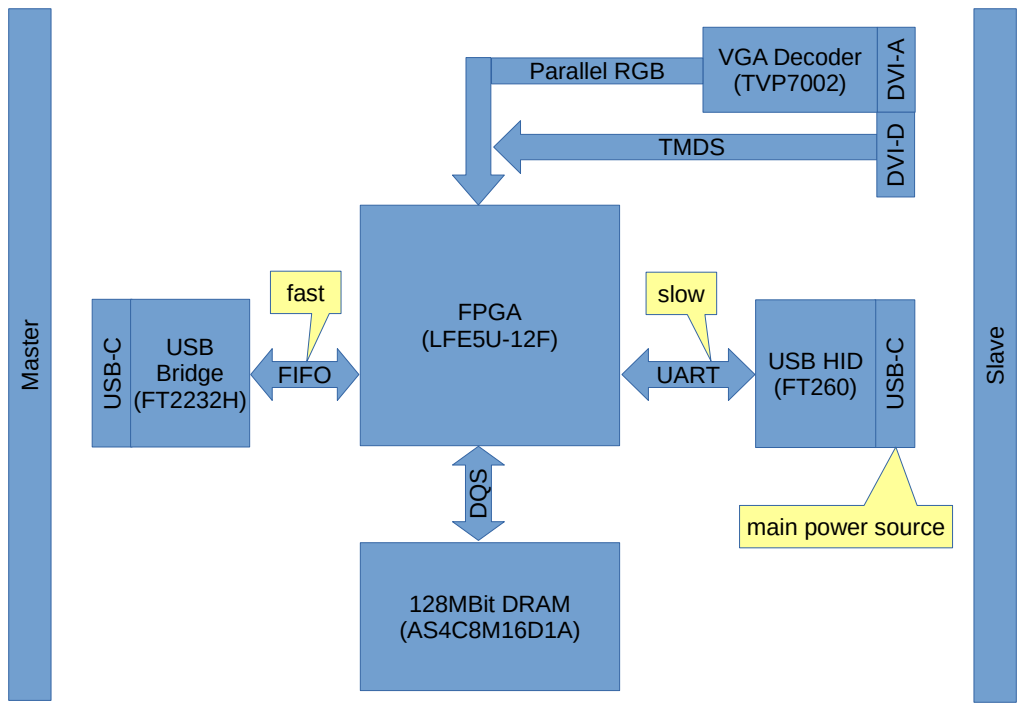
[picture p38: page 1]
FPGA (LFE5U-12F); Sla; USB Bridge (FT2232H); FIFO; fast; USB HID (FT260) UART; slow; 128MBit DRAM (AS4C8M16D1A); VGA Decoder; (TVP7002); Parallel RGB; TMDS

main power source

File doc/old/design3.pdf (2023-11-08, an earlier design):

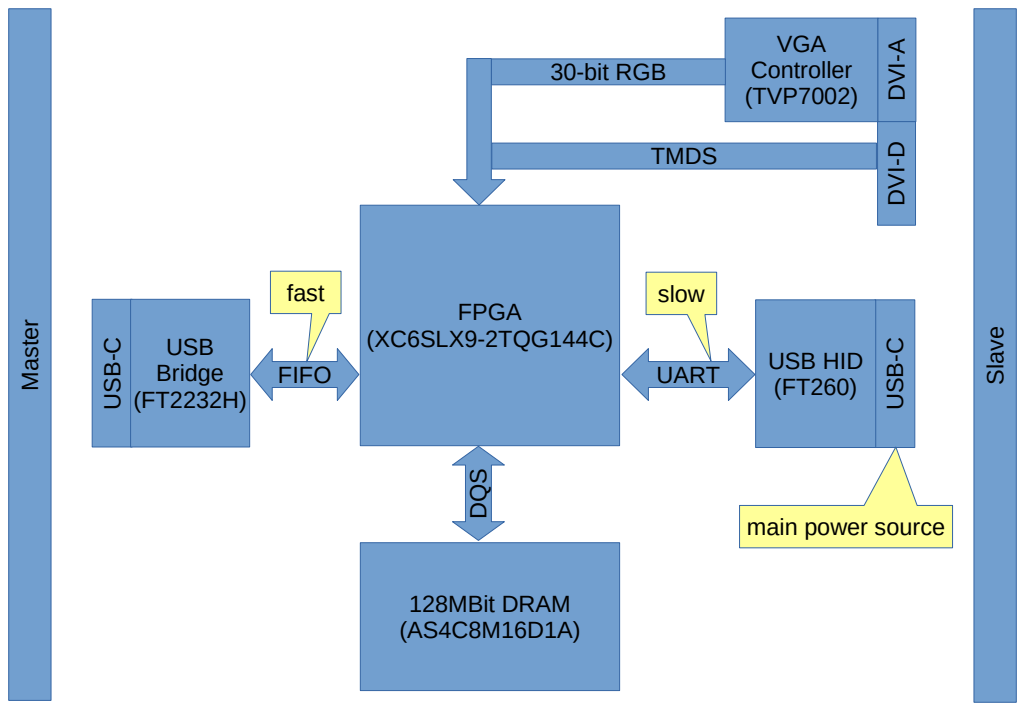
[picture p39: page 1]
VGA Controller; (TVP7002); FPGA (XC6SLX9-2TQG144C); 30-bit RGB; Sla; USB Bridge (FT2232H); FIFO; fast; USB HID (FT260) UART; slow; 128MBit DRAM (AS4C8M16D1A); TMDS

main power source

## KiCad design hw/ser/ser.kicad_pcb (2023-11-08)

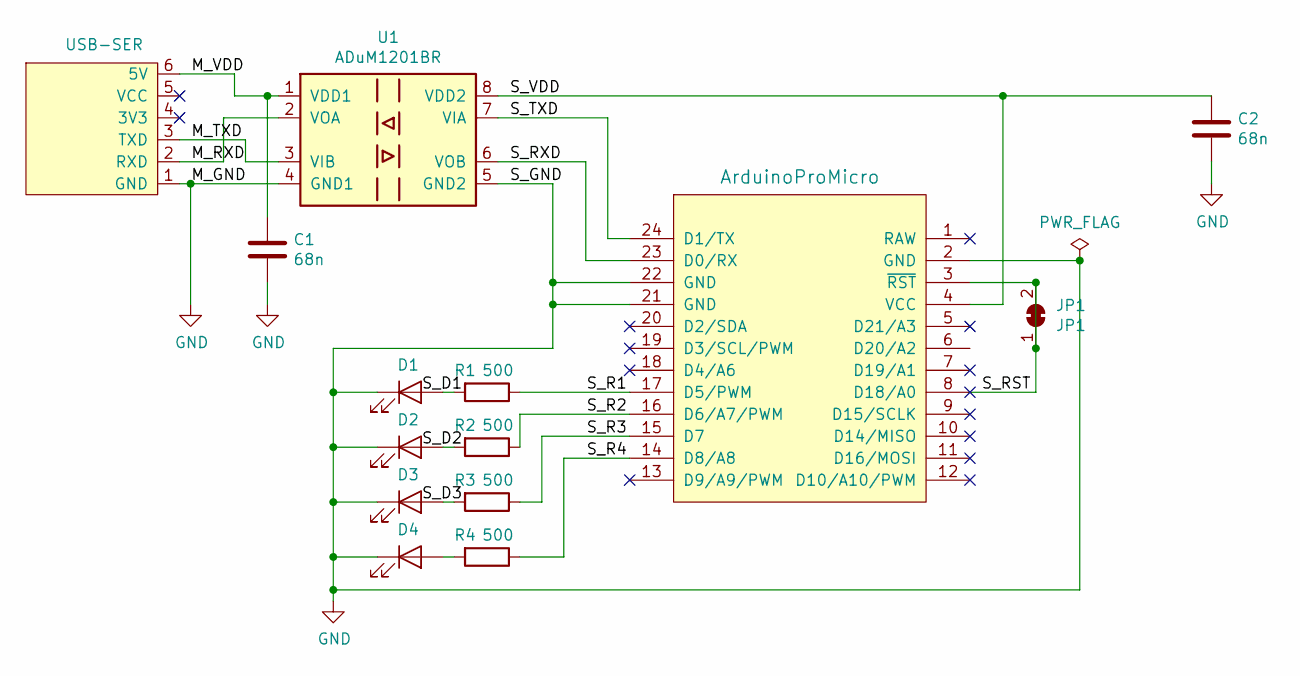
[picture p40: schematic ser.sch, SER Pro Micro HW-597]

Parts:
C1, C2: 68n; C_0603_1608Metric_Pad1.05x0.95mm_HandSolder
D1, D2, D3, D4: LED; LED_0603_1608Metric_Pad1.05x0.95mm_HandSolder
IC1: ArduinoProMicro; ArduinoProMicro_Custom
JP1: JP1; SolderJumper-2_P1.3mm_Bridged_Pad1.0x1.5mm
JT1: USB-SER; PinHeader_1x06_P2.54mm_Vertical_Custom
R1, R2, R3, R4: 500; R_0603_1608Metric_Pad1.05x0.95mm_HandSolder
U1: ADuM1201BR; SOIC-8_3.9x4.9mm_P1.27mm

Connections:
/M_RXD: JT1.2 (RXD), U1.2 (VOA)
/M_TXD: JT1.3 (TXD), U1.3 (VIB)
/M_VDD: C1.1, JT1.6 (5V), U1.1 (VDD1)
/S_R1: IC1.17 (D5/PWM), R1.1
/S_R2: IC1.16 (D6/A7/PWM), R2.1
/S_R3: IC1.15 (D7), R3.1
/S_R4: IC1.14 (D8/A8), R4.1
/S_RST: IC1.3 (~RST), IC1.8 (D18/A0), JP1.1 (A), JP1.2 (B)
/S_RXD: IC1.23 (D0/RX), U1.6 (VOB)
/S_TXD: IC1.24 (D1/TX), U1.7 (VIA)
/S_VDD: C2.1, IC1.4 (VCC), U1.8 (VDD2)
GND: C1.2, C2.2, D1.1 (K), D2.1 (K), D3.1 (K), D4.1 (K), IC1.2 (GND), IC1.21 (GND), IC1.22 (GND), JT1.1 (GND), U1.4 (GND1), U1.5 (GND2)
unnamed: D1.2 (A), R1.2
unnamed: D2.2 (A), R2.2
unnamed: D3.2 (A), R3.2
unnamed: D4.2 (A), R4.2

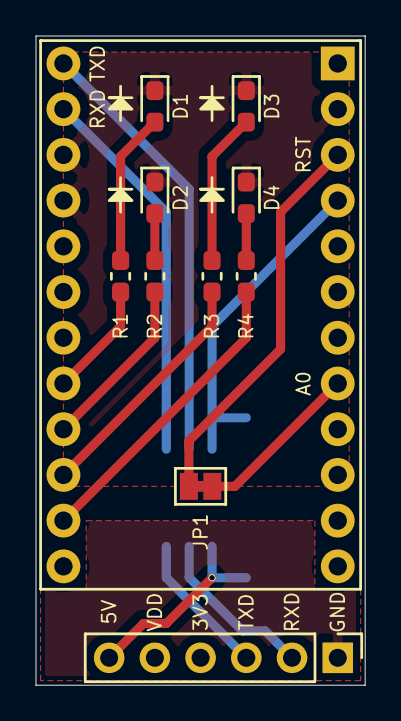
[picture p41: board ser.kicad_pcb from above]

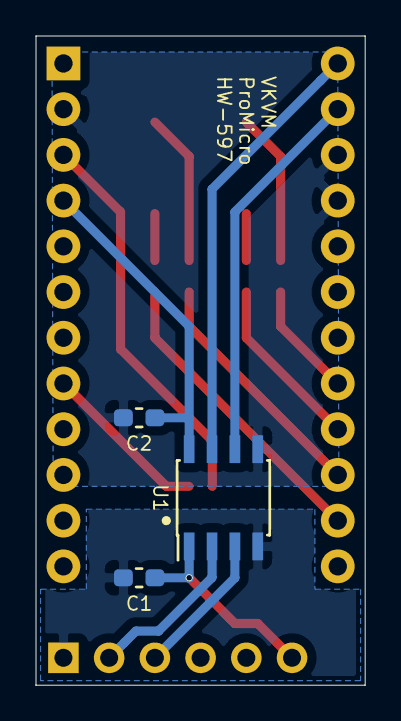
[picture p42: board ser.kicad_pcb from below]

Board: 2 copper layers, 18.3 x 36.1 mm, 14 parts (3 on the bottom side), 16 nets.

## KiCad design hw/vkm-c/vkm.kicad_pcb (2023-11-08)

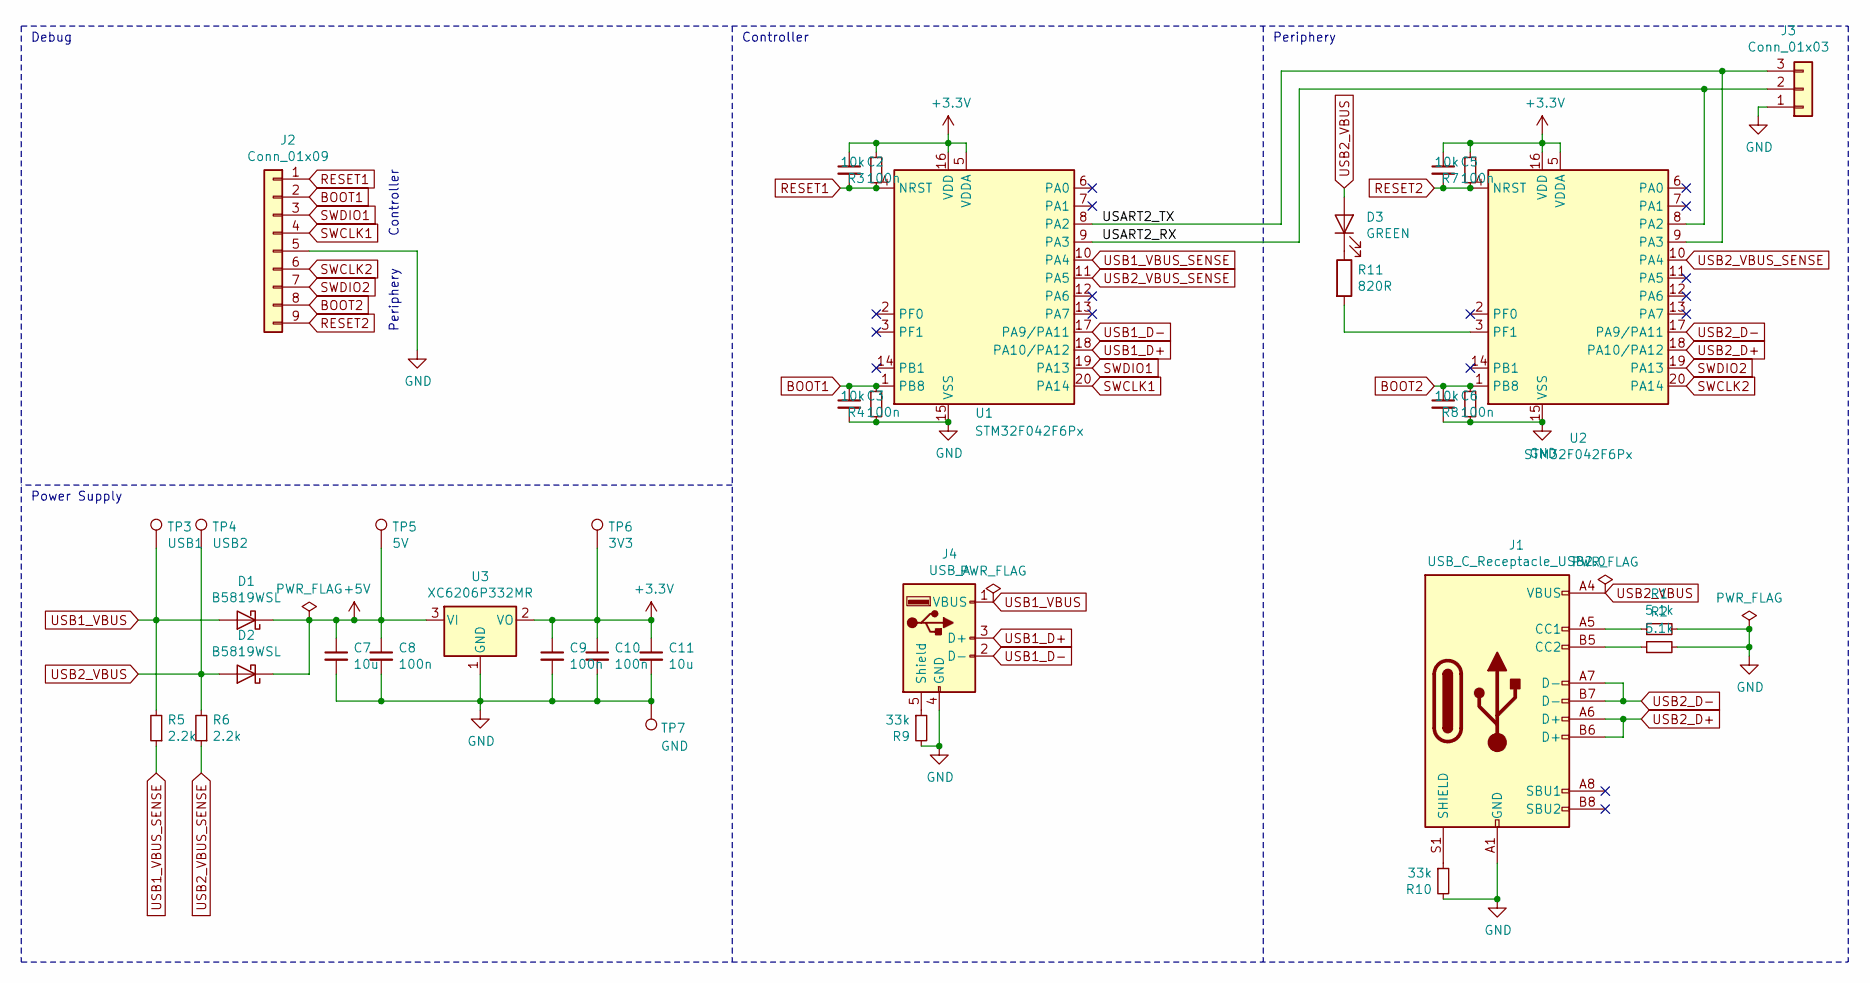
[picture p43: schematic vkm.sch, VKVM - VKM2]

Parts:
C2, C3, C5, C6, C8, C9, C10: 100n; C_0603_1608Metric; LCSC C14663
C7, C11: 10u; C_0603_1608Metric; LCSC C19702
D1, D2: B5819WSL; D_SOD-123; LCSC C8598
D3: GREEN; LED_0603_1608Metric; LCSC C72043
J1: USB_C_Receptacle_USB2.0; USB_C_HRO_TYPE_C_31_M_12; LCSC C165948
J2: Conn_01x09; PinHeader_1x09_P2.54mm_Vertical
J3: Conn_01x03; PinHeader_1x03_P2.54mm_Horizontal_Edge
J4: USB_A; USB_A_TH_AM90; LCSC C9739
R1, R2: 5.1k; R_0603_1608Metric; LCSC C23186
R3, R4, R7, R8: 10k; R_0603_1608Metric; LCSC C25804
R5, R6: 2.2k; R_0603_1608Metric; LCSC C4190
R9, R10: 33k; R_0603_1608Metric; LCSC C4216
R11: 820R; R_0603_1608Metric; LCSC C23253
TP3: USB1; TestPoint_Pad_D1.0mm
TP4: USB2; TestPoint_Pad_D1.0mm
TP5: 5V; TestPoint_Pad_D1.0mm
TP6: 3V3; TestPoint_Pad_D1.0mm
TP7: GND; TestPoint_Pad_D1.0mm
U1, U2: STM32F042F6Px; TSSOP-20_4.4x6.5mm_P0.65mm; LCSC C81000
U3: XC6206P332MR; SOT-23; LCSC C5446

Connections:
+3V3: C2.1, C5.1, C9.1, C10.1, C11.1, R3.1, R7.1, TP6.1, U1.5 (VDDA), U1.16 (VDD), U2.5 (VDDA), U2.16 (VDD), U3.2 (VO)
+5V: C7.1, C8.1, D1.1 (K), D2.1 (K), TP5.1, U3.3 (VI)
/USART2_RX: J3.2, U1.9 (PA3), U2.8 (PA2)
/USART2_TX: J3.3, U1.8 (PA2), U2.9 (PA3)
BOOT1: C3.1, J2.2, R4.1, U1.1 (PB8)
BOOT2: C6.1, J2.8, R8.1, U2.1 (PB8)
GND: C3.2, C6.2, C7.2, C8.2, C9.2, C10.2, C11.2, J1.A1 (GND), J1.A12 (GND), J1.B1 (GND), J1.B12 (GND), J2.5, J3.1, J4.4 (GND), R1.2, R2.2, R4.2, R8.2, R9.2, R10.2, TP7.1, U1.15 (VSS), U2.15 (VSS), U3.1 (GND)
unnamed: D3.1 (K), R11.1
unnamed: J1.A5 (CC1), R1.1
unnamed: J1.B5 (CC2), R2.1
unnamed: J1.S1 (SHIELD), R10.1
unnamed: J4.5 (Shield), R9.1
unnamed: R11.2, U2.3 (PF1)
RESET1: C2.2, J2.1, R3.2, U1.4 (NRST)
RESET2: C5.2, J2.9, R7.2, U2.4 (NRST)
SWCLK1: J2.4, U1.20 (PA14)
SWCLK2: J2.6, U2.20 (PA14)
SWDIO1: J2.3, U1.19 (PA13)
SWDIO2: J2.7, U2.19 (PA13)
USB1_D+: J4.3 (D+), U1.18 (PA10/PA12)
USB1_D-: J4.2 (D-), U1.17 (PA9/PA11)
USB1_VBUS: D1.2 (A), J4.1 (VBUS), R5.2, TP3.1
USB1_VBUS_SENSE: R5.1, U1.10 (PA4)
USB2_D+: J1.A6 (D+), J1.B6 (D+), U2.18 (PA10/PA12)
USB2_D-: J1.A7 (D-), J1.B7 (D-), U2.17 (PA9/PA11)
USB2_VBUS: D2.2 (A), D3.2 (A), J1.A4 (VBUS), J1.A9 (VBUS), J1.B4 (VBUS), J1.B9 (VBUS), R6.2, TP4.1
USB2_VBUS_SENSE: R6.1, U1.11 (PA5), U2.10 (PA4)

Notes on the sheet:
Controller
Periphery
Debug
Power Supply

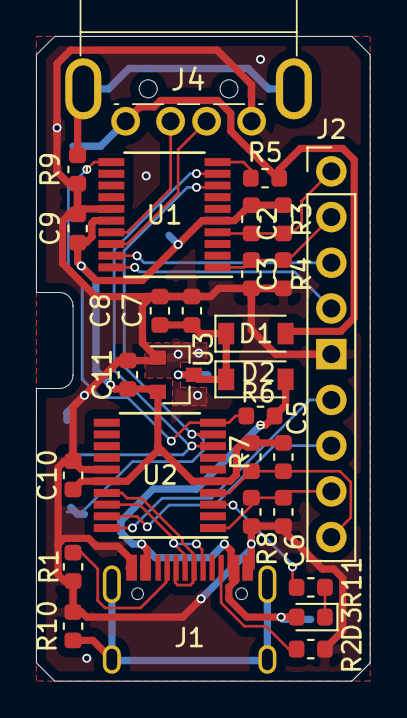
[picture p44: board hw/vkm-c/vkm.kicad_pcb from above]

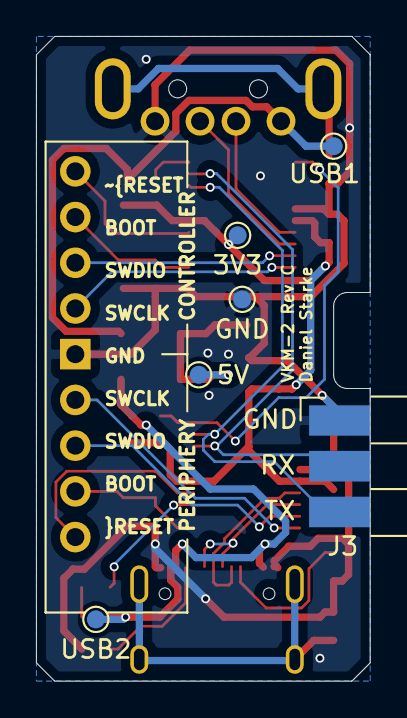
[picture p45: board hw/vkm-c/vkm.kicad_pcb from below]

Board: 2 copper layers, 18.5 x 35.8 mm, 35 parts (6 on the bottom side), 27 nets.

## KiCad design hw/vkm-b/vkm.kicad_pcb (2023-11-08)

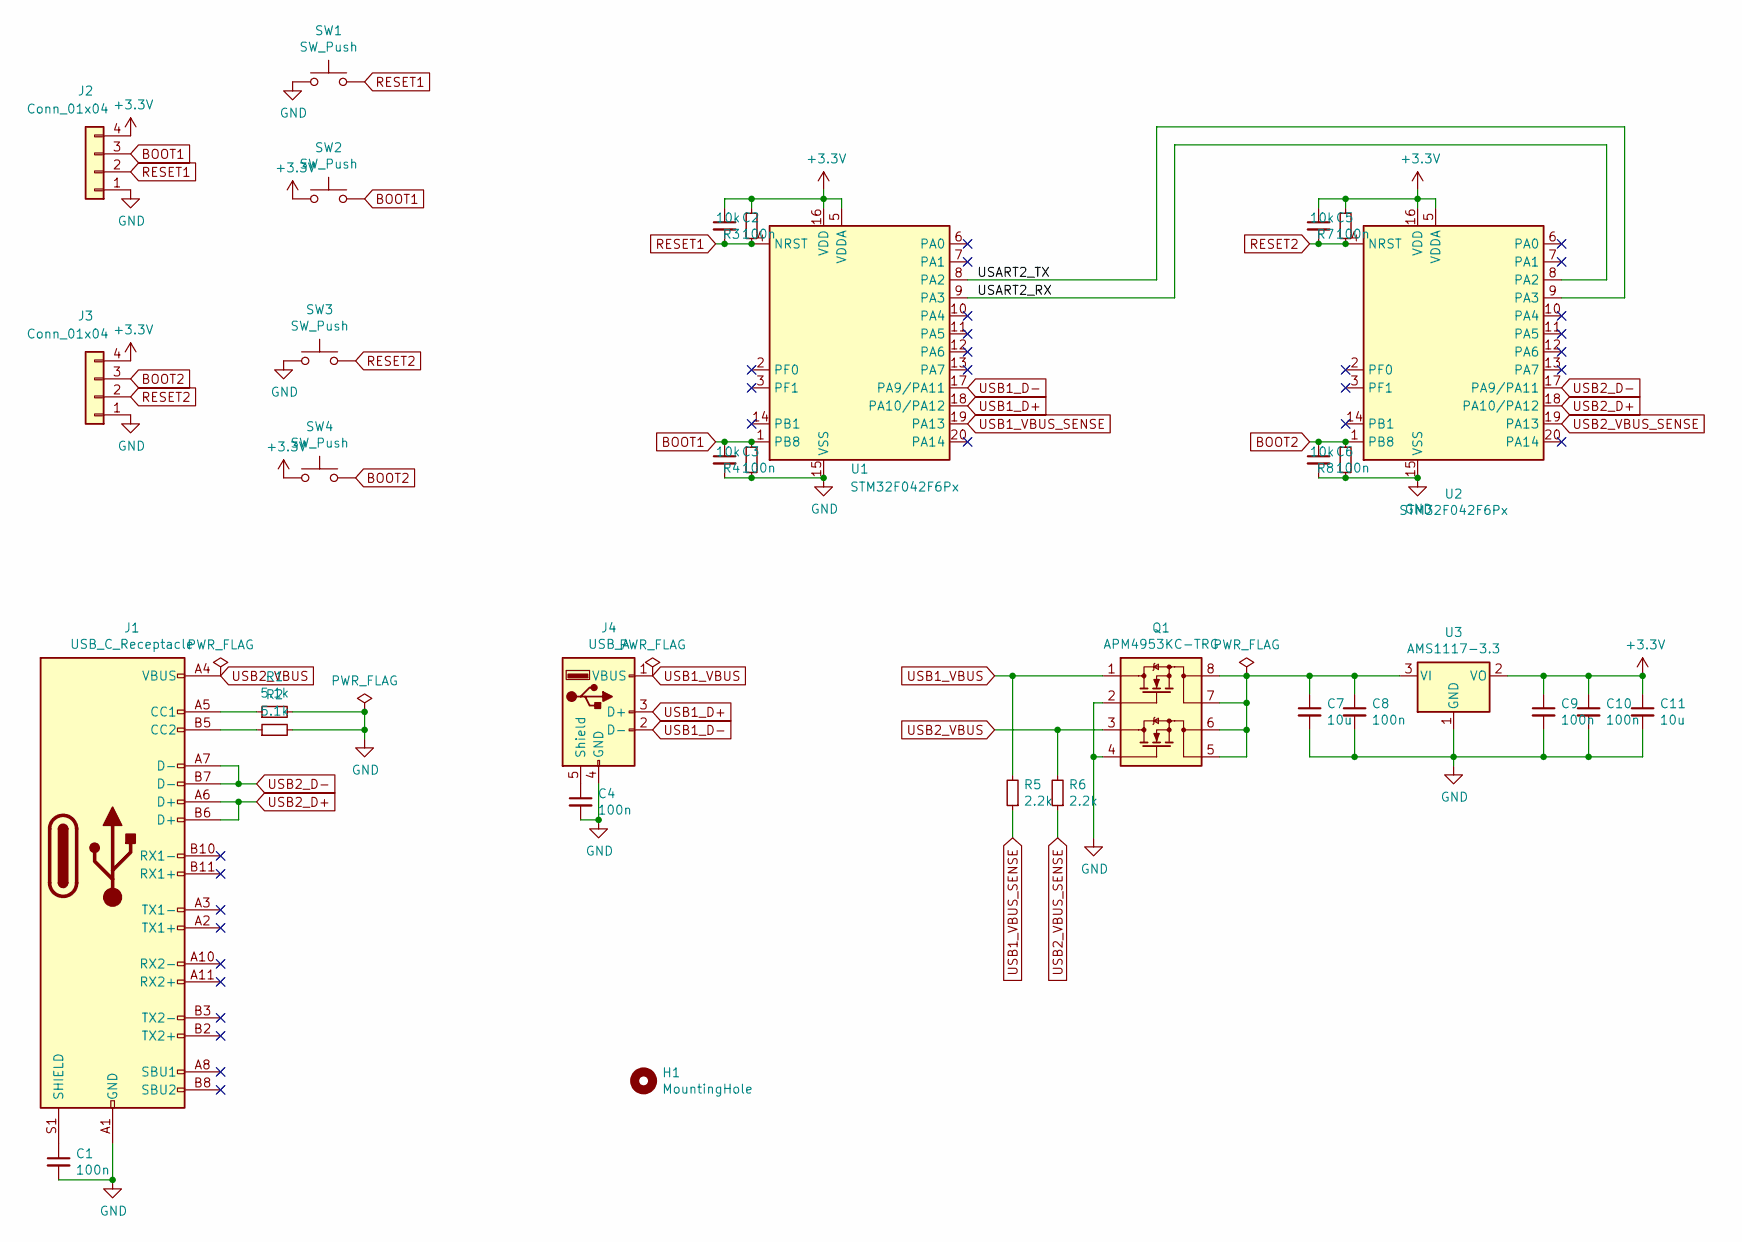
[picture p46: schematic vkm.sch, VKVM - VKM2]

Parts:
C1, C2, C3, C4, C5, C6, C8, C9, C10: 100n; C_0603_1608Metric; LCSC C14663
C7, C11: 10u; CP_EIA-3216-10_Kemet-I; LCSC C7171
H1: MountingHole; MountingHole_3.2mm_M3_DIN965_Pad
J1: USB_C_Receptacle; USB_C_HRO_TYPE_C_31_M_12; LCSC C165948
J2, J3: Conn_01x04; PinHeader_1x04_P2.54mm_Vertical
J4: USB_A; USB_A_TH_AM90; LCSC C9739
Q1: APM4953KC-TRG; SOP-8_3.9x4.9mm_P1.27mm; LCSC C20897
R1, R2: 5.1k; R_0603_1608Metric; LCSC C23186
R3, R4, R7, R8: 10k; R_0603_1608Metric; LCSC C25804
R5, R6: 2.2k; R_0603_1608Metric; LCSC C4190
SW1, SW2, SW3, SW4: SW_Push; SW_SPST_TL3342
U1, U2: STM32F042F6Px; TSSOP-20_4.4x6.5mm_P0.65mm; LCSC C81000
U3: AMS1117-3.3; SOT-223-3_TabPin2; LCSC C6186

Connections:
+3V3: C2.1, C5.1, C9.1, C10.1, C11.1, J2.4, J3.4, R3.1, R7.1, SW2.1, SW4.1, U1.5 (VDDA), U1.16 (VDD), U2.5 (VDDA), U2.16 (VDD), U3.2 (VO)
/USART2_RX: U1.9 (PA3), U2.8 (PA2)
/USART2_TX: U1.8 (PA2), U2.9 (PA3)
BOOT1: C3.1, J2.3, R4.1, SW2.2, U1.1 (PB8)
BOOT2: C6.1, J3.3, R8.1, SW4.2, U2.1 (PB8)
GND: C1.2, C3.2, C4.2, C6.2, C7.2, C8.2, C9.2, C10.2, C11.2, J1.A1 (GND), J1.A12 (GND), J1.B1 (GND), J1.B12 (GND), J2.1, J3.1, J4.4 (GND), Q1.2 (G1), Q1.4 (G2), R1.2, R2.2, R4.2, R8.2, SW1.1, SW3.1, U1.15 (VSS), U2.15 (VSS), U3.1 (GND)
unnamed: C1.1, J1.S1 (SHIELD)
unnamed: C4.1, J4.5 (Shield)
unnamed: C7.1, C8.1, Q1.5 (D2), Q1.6 (D2), Q1.7 (D1), Q1.8 (D1), U3.3 (VI)
unnamed: J1.A5 (CC1), R1.1
unnamed: J1.B5 (CC2), R2.1
RESET1: C2.2, J2.2, R3.2, SW1.2, U1.4 (NRST)
RESET2: C5.2, J3.2, R7.2, SW3.2, U2.4 (NRST)
USB1_D+: J4.3 (D+), U1.18 (PA10/PA12)
USB1_D-: J4.2 (D-), U1.17 (PA9/PA11)
USB1_VBUS: J4.1 (VBUS), Q1.1 (S1), R5.2
USB1_VBUS_SENSE: R5.1, U1.19 (PA13)
USB2_D+: J1.A6 (D+), J1.B6 (D+), U2.18 (PA10/PA12)
USB2_D-: J1.A7 (D-), J1.B7 (D-), U2.17 (PA9/PA11)
USB2_VBUS: J1.A4 (VBUS), J1.A9 (VBUS), J1.B4 (VBUS), J1.B9 (VBUS), Q1.3 (S2), R6.2
USB2_VBUS_SENSE: R6.1, U2.19 (PA13)

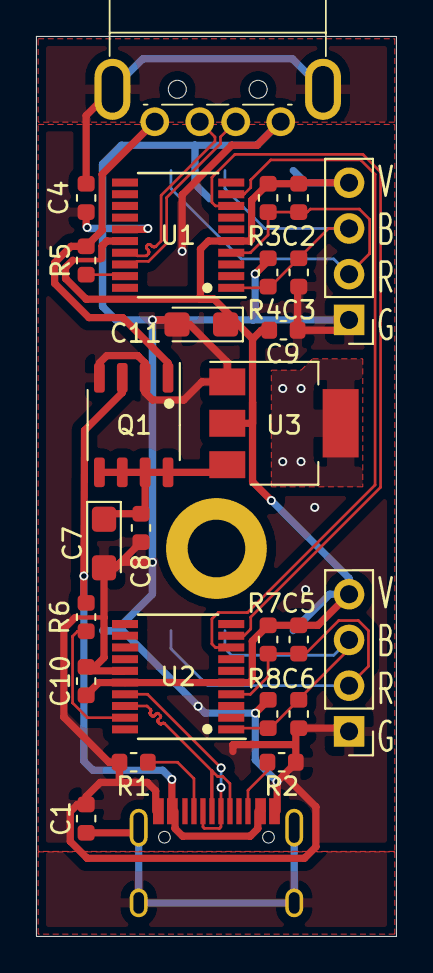
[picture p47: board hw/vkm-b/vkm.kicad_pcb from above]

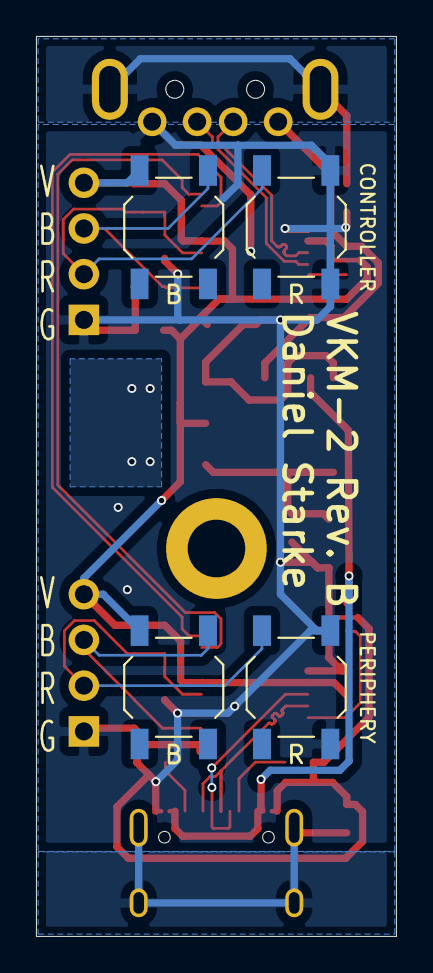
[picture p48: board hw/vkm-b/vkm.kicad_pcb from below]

Board: 2 copper layers, 20.0 x 50.0 mm, 32 parts (4 on the bottom side), 21 nets.

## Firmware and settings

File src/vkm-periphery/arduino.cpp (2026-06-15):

/**
 * @file arduino.ino
 * @author Daniel Starke
 * @copyright Copyright 2019-2026 Daniel Starke
 * @date 2019-10-11
 * @version 2026-06-13
 *
 * Virtual Keyboard/Mouse periphery device.
 * Tested with Arduino IDE 1.8.5 and ATmega32U4 (a.k.a. Arduino Pro Micro).
 */
#include <Arduino.h>
#include "arduino.hpp"
#ifdef VKVM_LED_PWM
#include <wiring_irq.h>
#include <wiring_private.h>
#endif /* VKVM_LED_PWM */


Framing<VKVM_MAX_FRAME_SIZE> framing(handleWrite);


const tHandler handler[RequestType::COUNT] VKVM_ROM = {
	getProtocolVersion,
	getAlive,
	getUsbState,
	getKeyboardLeds,
	setKeyboardDown,
	setKeyboardUp,
	setKeyboardAllUp,
	setKeyboardPush,
	setKeyboardWrite,
	setMouseButtonDown,
	setMouseButtonUp,
	setMouseButtonAllUp,
	setMouseButtonPush,
	setMouseMoveAbs,
	setMouseMoveRel,
	setMouseScroll
};


#ifdef DEBUG
const char * frameType[] = {
	"GET_PROTOCOL_VERSION",
	"GET_ALIVE",
	"GET_USB_STATE",
	"GET_KEYBOARD_LEDS",
	"SET_KEYBOARD_DOWN",
	"SET_KEYBOARD_UP",
	"SET_KEYBOARD_ALL_UP",
	"SET_KEYBOARD_PUSH",
	"SET_KEYBOARD_WRITE",
	"SET_MOUSE_BUTTON_DOWN",
	"SET_MOUSE_BUTTON_UP",
	"SET_MOUSE_BUTTON_ALL_UP",
	"SET_MOUSE_BUTTON_PUSH",
	"SET_MOUSE_MOVE_ABS",
	"SET_MOUSE_MOVE_REL",
	"SET_MOUSE_SCROLL"
};
#endif /* DEBUG */


/**
 * Returns the current USB periphery state
 *
 * @return USB periphery state
 */
static uint8_t getCurrentUsbState() {
	uint8_t res = USBSTATE_OFF;
#ifdef PIN_USB2_SENSE
	if ( digitalRead(PIN_USB2_SENSE) ) {
		res = uint8_t(res | USBSTATE_ON);
	}
#endif /* PIN_USB2_SENSE */
	if ( USBDevice.configured() ) {
		res = uint8_t(res | USBSTATE_CONFIGURED);
	}
	res = uint8_t(res | Vkm().getBootModes());
	return res;
}


/**
 * Processes a received frame.
 *
 * @param[in] seq - frame sequence number
 * @param[in] buf - frame data
 * @param[in] len - frame data length
 * @param[in] err - true on error, else false
 */
void handleFrame(const uint8_t seq, const uint8_t * buf, const size_t len, const bool err) {
	if (len < 1 || err) {
		sendResponse(seq, ResponseType::E_BROKEN_FRAME);
		return;
	}
	if (*buf >= RequestType::COUNT) {
		sendResponse(seq, ResponseType::E_INVALID_REQ_TYPE, *buf);
		return;
	}
	const tHandler fn = (tHandler)(VKVM_ROM_READ_PTR(handler, *buf));
	if (fn == NULL) {
		sendResponse(seq, ResponseType::E_INVALID_REQ_TYPE, *buf);
		return;
	}
	DBG_MSG(frameType[*buf]);
#ifdef PIN_USB2_SENSE
	const bool usbConnected = digitalRead(PIN_USB2_SENSE);
#else /* not PIN_USB2_SENSE */
	const bool usbConnected = true;
#endif /* PIN_USB2_SENSE */
	if (*buf <= RequestType::GET_KEYBOARD_LEDS || (usbConnected && USBDevice.configured())) {
		FrameParams fp(seq, static_cast<RequestType::Type>(*buf), buf + 1, size_t(len - 1));
		fn(fp);
	} else {
		/* Tried to send data to the host without a USB connection. */
#ifdef PIN_STATUS_LED
		setStatusLed(false);
#endif /* PIN_STATUS_LED */
		sendResponse(seq, ResponseType::E_HOST_WRITE_ERROR);
		if ( ! usbConnected ) {
			Serial1.flush();
			USBDevice.detach();
			USBDevice.attach();
		}
		return;
	}
}


/**
 * Writes out a single byte to the controller.
 *
 * @param[in] userArg - user defined callback argument
 * @param[in] val - byte to send
 * @param[in] eof - end-of-frame mark
 * @return true on success, else false
 */
inline bool handleWrite(void * /* userArg */, const uint8_t val, const bool eof) {
	const bool res = Serial1.write(val) == 1;
	if ( eof ) Serial1.flush();
	return res;
}


/**
 * Handles protocol version request.
 * Returns the protocol version as uint16_t.
 *
 * @param[in] fp - frame parameters
 */
void getProtocolVersion(const FrameParams & fp) {
	/* assume new connection and ensure proper start of frame */
	framing.setFirstOut();
	if (fp.len > 0) {
		sendResponse(fp.seq, ResponseType::E_INVALID_FIELD_VALUE, uint8_t(0));
		return;
	}
	sendResponse(fp.seq, ResponseType::S_OK, uint16_t(VKVM_PROT_VERSION));
}


/**
 * Handles alive request.
 *
 * @param[in] fp - frame parameters
 */
void getAlive(const FrameParams & fp) {
	if (fp.len > 0) {
		sendResponse(fp.seq, ResponseType::E_INVALID_FIELD_VALUE, uint8_t(0));
		return;
	}
	sendResponse(fp.seq, ResponseType::S_OK);
}


/**
 * Handles get USB state request.
 * Returns the USB state as uint8_t.
 *
 * @param[in] fp - frame parameters
 */
void getUsbState(const FrameParams & fp) {
	if (fp.len > 0) {
		sendResponse(fp.seq, ResponseType::E_INVALID_FIELD_VALUE, uint8_t(0));
		return;
	}
	sendResponse(fp.seq, ResponseType::S_OK, getCurrentUsbState());
}


/**
 * Handles get keyboard LED request.
 * Returns the keyboard LED states as uint8_t.
 *
 * @param[in] fp - frame parameters
 */
void getKeyboardLeds(const FrameParams & fp) {
	if (fp.len > 0) {
		sendResponse(fp.seq, ResponseType::E_INVALID_FIELD_VALUE, uint8_t(0));
		return;
	}
	sendResponse(fp.seq, ResponseType::S_OK, Vkm().getLeds());
}


/**
 * Handles set keyboard down request.
 * Expects up to 6 key codes each as uint8_t.
 * Returns a bit map with the keys actually pressed whereas the LSB is the first key.
 *
 * @param[in] fp - frame parameters
 */
void setKeyboardDown(const FrameParams & fp) {
	if (fp.len < 1 || fp.len > 6) {
		sendResponse(fp.seq, ResponseType::E_INVALID_FIELD_VALUE, uint8_t(0));
		return;
	}
	/* return bit field with the result for each key */
	uint8_t res = 0;
	uint8_t i = 0;
	for (; i < fp.len; i++) {
		res = uint8_t((res >> 1) | (Vkm().pressKey(fp.buf[i]) ? 0x20 : 0x00));
	}
	for (; i < 6; i++) res = uint8_t(res >> 1);
	sendResponse(fp.seq, ResponseType::S_OK, res);
}


/**
 * Handles set keyboard up request.
 * Expects up to 6 key codes each as uint8_t.
 * Returns a bit map with the keys actually released whereas the LSB is the first key.
 *
 * @param[in] fp - frame parameters
 */
void setKeyboardUp(const FrameParams & fp) {
	if (fp.len < 1 || fp.len > 6) {
		sendResponse(fp.seq, ResponseType::E_INVALID_FIELD_VALUE, uint8_t(0));
		return;
	}
	/* return bit field with the result for each key */
	uint8_t res = 0;
	uint8_t i = 0;
	for (; i < fp.len; i++) {
		res = uint8_t((res >> 1) | (Vkm().releaseKey(fp.buf[i]) ? 0x20 : 0x00));
	}
	for (; i < 6; i++) res = uint8_t(res >> 1);
	sendResponse(fp.seq, ResponseType::S_OK, res);
}


/**
 * Handles set keyboard all up request.
 *
 * @param[in] fp - frame parameters
 */
void setKeyboardAllUp(const FrameParams & fp) {
	if (fp.len > 0) {
		sendResponse(fp.seq, ResponseType::E_INVALID_FIELD_VALUE, uint8_t(0));
		return;
	}
	if ( ! Vkm().releaseAllKeys() ) {
		sendResponse(fp.seq, ResponseType::E_HOST_WRITE_ERROR);
		return;
	}
	sendResponse(fp.seq, ResponseType::S_OK);
}


/**
 * Handles set keyboard push request.
 * Expects any number of ASCII characters each as uint8_t.
 * Returns the number of characters sent as uint8_t.
 *
 * @param[in] fp - frame parameters
 */
void setKeyboardPush(const FrameParams & fp) {
	const uint8_t res = uint8_t(Vkm().pushKeys(fp.buf, fp.len));
	sendResponse(fp.seq, ResponseType::S_OK, res);
}


/**
 * Handles set keyboard write request.
 * Expects one modifier as uint8_t and any number of ASCII characters each as uint8_t.
 * Returns the number of characters sent as uint8_t excluding the modifier.
 *
 * @param[in] fp - frame parameters
 */
void setKeyboardWrite(const FrameParams & fp) {
	if (fp.len < 1) {
		sendResponse(fp.seq, ResponseType::E_INVALID_FIELD_VALUE, uint8_t(0));
		return;
	}
	const uint8_t res = uint8_t(Vkm().write(fp.buf[0], fp.buf + 1, fp.len - 1));
	sendResponse(fp.seq, ResponseType::S_OK, res);
}


/**
 * Handles set mouse button down request.
 * Expects up to 3 mouse buttons each as uint8_t.
 *
 * @param[in] fp - frame parameters
 */
void setMouseButtonDown(const FrameParams & fp) {
	if (fp.len < 1 || fp.len > 3) {
		sendResponse(fp.seq, ResponseType::E_INVALID_FIELD_VALUE, uint8_t(0));
		return;
	}
	for (uint8_t i = 0; i < fp.len && i < 3; i++) {
		if ((fp.buf[i] & USBBUTTON_ALL) != fp.buf[i]) {
			sendResponse(fp.seq, ResponseType::E_INVALID_FIELD_VALUE, i);
			return;
		}
	}
	for (uint8_t i = 0; i < fp.len && i < 3; i++) {
		Vkm().pressButton(fp.buf[i]);
	}
	sendResponse(fp.seq, ResponseType::S_OK);
}


/**
 * Handles set mouse button up request.
 * Expects up to 3 mouse buttons each as uint8_t.
 *
 * @param[in] fp - frame parameters
 */
void setMouseButtonUp(const FrameParams & fp) {
	if (fp.len < 1 || fp.len > 3) {
		sendResponse(fp.seq, ResponseType::E_INVALID_FIELD_VALUE, uint8_t(0));
		return;
	}
	for (uint8_t i = 0; i < fp.len && i < 3; i++) {
		if ((fp.buf[i] & USBBUTTON_ALL) != fp.buf[i]) {
			sendResponse(fp.seq, ResponseType::E_INVALID_FIELD_VALUE, i);
			return;
		}
	}
	for (uint8_t i = 0; i < fp.len && i < 3; i++) {
		Vkm().releaseButton(fp.buf[i]);
	}
	sendResponse(fp.seq, ResponseType::S_OK);
}


/**
 * Handles set mouse button all up request.
 *
 * @param[in] fp - frame parameters
 */
void setMouseButtonAllUp(const FrameParams & fp) {
	if (fp.len > 0) {
		sendResponse(fp.seq, ResponseType::E_INVALID_FIELD_VALUE, uint8_t(0));
		return;
	}
	if ( ! Vkm().releaseButton(USBBUTTON_ALL) ) {
		sendResponse(fp.seq, ResponseType::E_HOST_WRITE_ERROR);
		return;
	}
	sendResponse(fp.seq, ResponseType::S_OK);
}


/**
 * Handles set mouse button push request.
 * Expects any number of mouse buttons each as uint8_t.
 * Returns the number of buttons sent as uint8_t.
 *
 * @param[in] fp - frame parameters
 */
void setMouseButtonPush(const FrameParams & fp) {
	for (uint8_t i = 0; i < fp.len; i++) {
		if ((fp.buf[i] & USBBUTTON_ALL) != fp.buf[i]) {
			sendResponse(fp.seq, ResponseType::E_INVALID_FIELD_VALUE, i);
			return;
		}
	}
	uint8_t res = 0;
	for (uint8_t i = 0; i < fp.len; i++) {
		res = uint8_t(res + Vkm().pushButton(fp.buf[i]));
	}
	sendResponse(fp.seq, ResponseType::S_OK, res);
}


/**
 * Handles set mouse move absolute request.
 * Expects the following fields:
 * - int16_t with the position on the x-axis (0 = 0%, 32767 = 100%)
 * - int16_t with the position on the y-axis (0 = 0%, 32767 = 100%)
 *
 * @param[in] fp - frame parameters
 */
void setMouseMoveAbs(const FrameParams & fp) {
	if (fp.len != 4) {
		sendResponse(fp.seq, ResponseType::E_INVALID_FIELD_VALUE, uint8_t(fp.len));
		return;
	}
	const int16_t xVal = int16_t((int16_t(fp.buf[0]) << 8) | int16_t(fp.buf[1]));
	const int16_t yVal = int16_t((int16_t(fp.buf[2]) << 8) | int16_t(fp.buf[3]));
	if ( ! Vkm().moveAbs(xVal, yVal) ) {
		sendResponse(fp.seq, ResponseType::E_HOST_WRITE_ERROR);
		return;
	}
	sendResponse(fp.seq, ResponseType::S_OK);
}


/**
 * Handles set mouse move relative request.
 * Expects the following fields:
 * - int8_t with the amount to move along the x-axis
 * - int8_t with the amount to move along the y-axis
 *
 * @param[in] fp - frame parameters
 */
void setMouseMoveRel(const FrameParams & fp) {
	if (fp.len != 2) {
		sendResponse(fp.seq, ResponseType::E_INVALID_FIELD_VALUE, uint8_t(fp.len));
		return;
	}
	const int8_t xVal = int8_t(fp.buf[0]);
	const int8_t yVal = int8_t(fp.buf[1]);
	if ( ! Vkm().moveRel(xVal, yVal) ) {
		sendResponse(fp.seq, ResponseType::E_HOST_WRITE_ERROR);
		return;
	}
	sendResponse(fp.seq, ResponseType::S_OK);
}


/**
 * Handles set mouse scroll request.
 * Expects the following fields:
 * - int8_t with the amount to move scroll wheel
 *
 * @param[in] fp - frame parameters
 */
void setMouseScroll(const FrameParams & fp) {
	if (fp.len != 1) {
		sendResponse(fp.seq, ResponseType::E_INVALID_FIELD_VALUE, uint8_t(fp.len));
		return;
	}
	const int8_t wheel = int8_t(fp.buf[0]);
	if ( ! Vkm().scroll(wheel) ) {
		sendResponse(fp.seq, ResponseType::E_HOST_WRITE_ERROR);
		return;
	}
	sendResponse(fp.seq, ResponseType::S_OK);
}


#if defined(PIN_STATUS_LED) && defined(VKVM_LED_PWM)
/** Input buffer for the DMA transfer which sets the GPIO port bits of the status LED. */
static uint16_t statusLedDmaInput[2] = {
	uint16_t(getInternalPin(PIN_STATUS_LED)), /* LED off */
	0, /* LED on */
};
/** STM32 HAL specific DMA handle. */
static DMA_HandleTypeDef hDmaStatusLed[1] = {0};
#endif /* PIN_STATUS_LED and VKVM_LED_PWM */


/**
 * Initializes the status LED, if available.
 */
void initStatusLed(void) {
#ifdef PIN_STATUS_LED
	pinMode(PIN_STATUS_LED, OUTPUT_OPEN_DRAIN);
	digitalWrite(PIN_STATUS_LED, LED_OFF);
#ifdef VKVM_LED_PWM
	/* Initialize TIM1 for PWM output. */
	const _TimerPinMap timInfo{1, 2, 1, 0}; /* TIM1_CH3N */
	TIM_TypeDef * inst = reinterpret_cast<TIM_TypeDef *>(timInfo.getInstanceBaseAddr());
	TIM_HandleTypeDef * hTim = _TimerPinMap::getTimHandleFromId(inst);
	if (hTim == NULL) systemErrorHandler();
	TIM_OC_InitTypeDef pwmChannel = {0};
	TIM_ClockConfigTypeDef clkSrc = {0};
	const uint32_t channel = timInfo.getChannel();
	hTim->Instance = inst;
	/* Rounds to the next higher possible number of periods per second. */
	hTim->Init.Prescaler = uint32_t(timInfo.getTimerClockFrequency() / (200 * 0xFFFFUL));
	/* The interval from 0xFFFE to 0 also counts as a single interval which is why there are 0xFFFF intervals here. */
	hTim->Init.Period = 0xFFFE;
	hTim->Init.CounterMode = TIM_COUNTERMODE_UP;
	hTim->Init.ClockDivision = TIM_CLOCKDIVISION_DIV1;
	hTim->Init.AutoReloadPreload = TIM_AUTORELOAD_PRELOAD_ENABLE;
	if (HAL_TIM_PWM_Init(hTim) != HAL_OK) systemErrorHandler();
	clkSrc.ClockSource = TIM_CLOCKSOURCE_INTERNAL;
	if (HAL_TIM_ConfigClockSource(hTim, &clkSrc) != HAL_OK) systemErrorHandler();
	pwmChannel.OCMode = TIM_OCMODE_PWM1;
	pwmChannel.Pulse = VKVM_LED_PWM;
	pwmChannel.OCPolarity = TIM_OCPOLARITY_HIGH;
	pwmChannel.OCNPolarity = TIM_OCNPOLARITY_HIGH;
	pwmChannel.OCFastMode = TIM_OCFAST_DISABLE;
	pwmChannel.OCIdleState = TIM_OCIDLESTATE_RESET;
	pwmChannel.OCNIdleState = TIM_OCNIDLESTATE_RESET;
	HAL_TIM_PWM_ConfigChannel(hTim, &pwmChannel, channel);
	/* Initialize DMA. */
	__HAL_RCC_DMA1_CLK_ENABLE();
	hDmaStatusLed->Instance = DMA1_Channel5; /* triggered by TIM1_CH3/TIM1_UP, see STM32F042F6 ref manual Table 26 */
	hDmaStatusLed->Init.Direction = DMA_MEMORY_TO_PERIPH;
	hDmaStatusLed->Init.PeriphInc = DMA_PINC_ENABLE;
	hDmaStatusLed->Init.MemInc = DMA_MINC_ENABLE;
	hDmaStatusLed->Init.PeriphDataAlignment = DMA_PDATAALIGN_HALFWORD;
	hDmaStatusLed->Init.MemDataAlignment = DMA_MDATAALIGN_HALFWORD;
	hDmaStatusLed->Init.Mode = DMA_CIRCULAR;
	hDmaStatusLed->Init.Priority = DMA_PRIORITY_LOW;
	if (HAL_DMA_Init(hDmaStatusLed) != HAL_OK) systemErrorHandler();
	/* Start DMA transfer to toggle status LED according to TIM3 output. */
	if (HAL_DMA_Start(
		hDmaStatusLed,
		reinterpret_cast<uint32_t>(statusLedDmaInput),
		reinterpret_cast<uint32_t>(&(getInternalPort(digitalPinToPort(PIN_STATUS_LED))->BSRR)),
		2 /* x uint16_t */
	) != HAL_OK) systemErrorHandler();
	if (HAL_TIMEx_PWMN_Start(hTim, channel) != HAL_OK) systemErrorHandler();
	__HAL_TIM_ENABLE_DMA(hTim, TIM_DMA_UPDATE | TIM_DMA_CC3); /* LED on/off */
#endif /* VKVM_LED_PWM */
	setStatusLed(false);
#endif /* PIN_STATUS_LED */
}


/**
 * Sets the status LED state.
 * 
 * @param[in] on - true to enable the LED, else false
 */
void setStatusLed(const bool on) {
#ifdef PIN_STATUS_LED
#ifdef VKVM_LED_PWM
	const_cast<volatile uint16_t *>(statusLedDmaInput)[1] = on ? uint16_t(getInternalPin(PIN_STATUS_LED)) : 0;
#else /* not VKVM_LED_PWM */
	digitalWrite(PIN_STATUS_LED, on ? LED_ON : LED_OFF);
#endif /* not VKVM_LED_PWM */
#else /* not PIN_STATUS_LED */
	(void)on;
#endif /* not PIN_STATUS_LED */
}


/**
 * Initialize the environment.
 */
void setup(void) {
#ifdef PIN_USB2_SENSE
	pinMode(PIN_USB2_SENSE, INPUT_PULLDOWN);
#endif /* PIN_USB2_SENSE */
	initStatusLed();
	Serial1.begin(VKVM_PROT_SPEED);
	Vkm().begin();
}


/**
 * Main processing loop.
 */
void loop(void) {
	static uint8_t leds = 0;
	static uint8_t state = getCurrentUsbState();
#ifdef PIN_STATUS_LED
	static uint32_t statusLedFlush = millis();
	static bool lastStatusLedOn = false;
#endif /* PIN_STATUS_LED */
#if defined(DEBUG) || defined(PIN_STATUS_LED)
	const uint32_t now = millis();
#endif /* DEBUG or PIN_STATUS_LED */
#ifdef DEBUG
	static const char hexStr[] = "0123456789ABCDEF";
	static uint32_t lastPing = 0;
	if ((now - lastPing) > 1000) {
		DBG_MSG("alive");
		lastPing = now;
	}
#endif /* DEBUG */
	/* Process data from the controller. */
	if (Serial1.available() > 0) {
		const uint8_t val = uint8_t(Serial1.read());
#ifdef DEBUG
		const char dbgStr[] = {hexStr[val >> 4], hexStr[val & 0x0F], 0};
		DBG_MSG(dbgStr);
#endif /* DEBUG */
		if ( ! framing.read(val, handleFrame) ) {
			sendResponse(0, ResponseType::E_BROKEN_FRAME);
		}
	}
	/* Resend reports if the idle period has expired. */
	Vkm().update();
	/* Process LED changes. */
	const uint8_t curLeds = Vkm().getLeds();
	if (curLeds != leds) {
		sendResponse(0, ResponseType::I_LED_UPDATE, curLeds);
		leds = curLeds;
	}
	/* Process USB periphery state changes. */
	const uint8_t curState = getCurrentUsbState();
	if (curState != state) {
		sendResponse(0, ResponseType::I_USB_STATE_UPDATE, curState);
		state = curState;
	}
#ifdef PIN_STATUS_LED
	/* Update USB connection status LED. */
	if ((now - statusLedFlush) >= LED_FLUSH_TIME) {
		lastStatusLedOn = !lastStatusLedOn;
		statusLedFlush = now;
	}
	const bool statusLedFlushing = USBDevice.configured() || lastStatusLedOn;
#ifdef PIN_USB2_SENSE
	setStatusLed(digitalRead(PIN_USB2_SENSE) && statusLedFlushing);
#else /* not PIN_USB2_SENSE */
	setStatusLed(statusLedFlushing);
#endif /* PIN_USB2_SENSE */
#endif /* PIN_STATUS_LED */
}

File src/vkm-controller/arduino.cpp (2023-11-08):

/**
 * @file arduino.cpp
 * @author Daniel Starke
 * @copyright Copyright 2020-2022 Daniel Starke
 * @date 2020-08-23
 * @version 2023-10-25
 *
 * USB-UART bridge. Only supports 8N1.
 */
#include <Arduino.h>


/** Pin for USB1 VBUS sense. */
#define PIN_USB1_SENSE PA_4
/** Pin for USB2 VBUS sense. */
#define PIN_USB2_SENSE PA_5


/** Maximum buffer size for both directions. */
#define MAX_BUFFER USB_EP_SIZE /* bytes */
/** Maximum data latency in milliseconds. */
#define MAX_LATENCY 8 /* ms */


uint8_t usbInBuf[MAX_BUFFER]; /**< USB to UART buffer. */
uint8_t usbOutBuf[MAX_BUFFER]; /**< UART to USB buffer. */
uint32_t usbInLen; /**< Number of bytes in `usbInBuf`. */
uint32_t usbOutLen; /**< Number of bytes in `usbOutBuf`. */
uint32_t baudRate; /**< Baudrate used for the UART (taken from USB interface). */
uint32_t lastOut; /**< Timestamp at which the most recent data was sent to USB. */
bool hasLastOut; /**< True if `lastOut` is valid, else false. */


/**
 * Sends the buffered data from the UART to the USB interface.
 *
 * @param[in] now - current time stamp in milliseconds
 */
static void sendToUsb(const uint32_t now) {
	if (usbOutLen <= 0) return;
	const uint8_t * ptr = usbOutBuf;
	for (uint32_t rem = usbOutLen; rem > 0; ) {
		const size_t written = Serial.write(ptr, rem);
		ptr += written;
		rem = uint32_t(rem - written);
	}
	usbOutLen = 0;
	lastOut = now;
	hasLastOut = true;
}


/**
 * Sends the buffered data from the USB interface to the UART.
 */
static void sendToUart() {
	if (usbInLen <= 0) return;
	const uint8_t * ptr = usbInBuf;
	for (uint32_t rem = usbInLen; rem > 0; ) {
		const size_t written = Serial1.write(ptr, rem);
		ptr += written;
		rem = uint32_t(rem - written);
	}
	usbInLen = 0;
}


/**
 * Initializes the application environment.
 */
void setup() {
	baudRate = 115200;
	Serial.begin(baudRate); /* the Baud rate here is just the initial value and may be set by the client */
	Serial1.begin(baudRate);
	while ( ! Serial1 ); /* wait for UART to be ready */
	hasLastOut = false;
}


/**
 * Main processing loop.
 */
void loop() {
	const uint32_t now = millis();

	/* handle Baud rate changes */
	const uint32_t newBaudRate = Serial.baud();
	if (newBaudRate != baudRate) {
		baudRate = newBaudRate;
		Serial1.end();
		Serial1.begin(baudRate);
		while ( ! Serial1 ); /* wait for UART to be ready */
	}

	/* handle latency constraints */
	if (Serial.dtr() && hasLastOut && uint32_t(now - lastOut) >= MAX_LATENCY) {
		sendToUsb(now);
	}

	/* handle data from UART */
	if ( Serial1 ) {
		while (usbOutLen < MAX_BUFFER && Serial1.available() > 0) {
			const int value = Serial1.read();
			if (value >= 0) {
				usbOutBuf[usbOutLen++] = uint8_t(value);
			}
		}
		if (hasLastOut == false && usbOutLen > 0) {
			lastOut = now;
			hasLastOut = true;
		}
		if (Serial.dtr() && usbOutLen >= MAX_BUFFER) {
			sendToUsb(now);
		}
	}

	/* handle data from USB */
	if ( Serial.dtr() ) {
		while (usbInLen < MAX_BUFFER && Serial.available() > 0) {
			const int value = Serial.read();
			if (value >= 0) {
				usbInBuf[usbInLen++] = uint8_t(value);
			}
		}
		if ( Serial1 ) {
			sendToUart();
		}
	}
}

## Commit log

2023-11-08 Initial commit.
    [2086581001.stp, 480371000.stp, Case.FCStd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]
2023-11-15 Add Windows Controller device driver installation guide.
2023-11-15 Fix new line formatting in win-driver.md.
2023-12-08 1.1.0
    - add: description for HDMI Capture Variant 6
    - add: ComPtr implementation for Windows targets
    - change: add video device index number in capture device list on Linux
    - change: use ComPtr based object life-time management in DirectShow related code
    - fix: missing capture devices if multiple share the same name
    - fix: ignore non-capture capable video devices on Linux
    - fix: missing file in build dependency tracking for Linux
    - fix: output format selection issue in DirectShow capture source
    - fix: laggy DirectShow based rendering by dropping frames at capture source
    - remove: dependency on SampleGrabber and NullRenderer for DirectShow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
2024-11-04 1.2.3
    - added: description for HDMI Capture Variant 7
    - changed: internal sorting algorithm to a stable sorting variant
    - fixed: special characters handling in video and serial drop-down list
    - fixed: duplicate name case for video devices handling by adding the device path
    - fixed: missing linker plugin flag for LTO build
2024-11-04 Added missing reference to HDMI capture device variant 7.
2026-06-15 1.3.0
    - added: added periphery USB HID boot protocol mode indicator
    - changed: improved SVG rendering performance by caching blended images
    - changed: use double based absolute mouse positioning at Vkvm API
    - changed: use proper anti-aliased radio buttons in send keys popup menu
    - changed: use libv4lconvert to do the capture image conversion manually on Linux
    - fixed: incorrect internal result value for key releases within the firmware
    - fixed: USB HID conformance issues
    - fixed: HID compatibility issues with some non-standard conform hosts
    - fixed: proper mouse movement if VKVM runs within a remote session (e.g. RDP)
    - fixed: out of bounds issue for video frames from broken video capture de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
